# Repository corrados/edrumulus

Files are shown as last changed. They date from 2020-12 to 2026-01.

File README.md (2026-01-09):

# Edrumulus

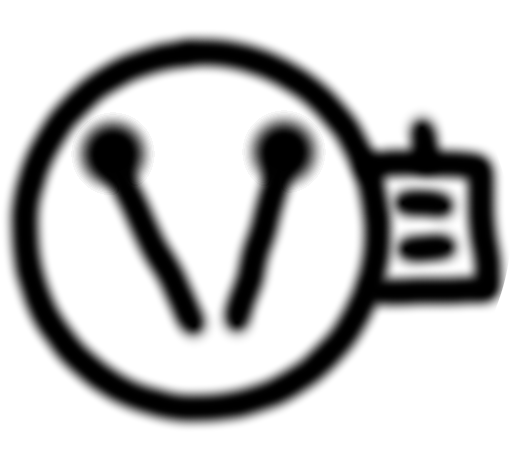
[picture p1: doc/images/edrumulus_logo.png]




**Edrumulus** is a high quality Open Source e-drum trigger module software which runs on a micro processor.

Project requirements:
- The trigger performance shall be similar to the Roland TD-27.
- Overall latency should be as small as possible. The goal is to achieve a latency < 10 ms.
- The required analog front end design shall be as simple as possible using the fewest number of
  parts possible.

## Videos

[](https://www.youtube.com/watch?v=tBlKvivwAE4)
[](https://www.youtube.com/watch?v=naP-ODXl9Y0)
[](https://www.youtube.com/watch?v=HZXtSe5p0rs)

## News

Find all important updates of the Edrumulus project in the [change log file](doc/ChangeLog.md)
and in the [discussion forums](https://github.com/corrados/edrumulus/discussions). A road map
of the Edrumulus project can be found in the [TODO file](doc/TODO.md).

## Features

- Positional sensing
- Retrigger cancellation
- Rim shot/cymbol choke detection
- Cross talk cancellation
- Clipping compensation
- Supported micro processor developer boards:
  - **ESP32 (dual core) DEVKIT V1 or similar**
  - **ESP32-S3**
  - **Teensy 4.0/4.1**

## Documentation

- [Manual](doc/manual.md)
- [Algorithm](doc/algorithm.md)

## Prototype hardware

We want to capture the entire signal without non-linear analog preprocessing.
Since micro controllers usually only convert analog signals in the range of 0 to 3.3 V,
we have to move the point of operation in the middle of the voltage range.

A circuit diagram of a simplified prototype which only supports a mono piezo pad and
a hi-hat controller input is given in the following picture:
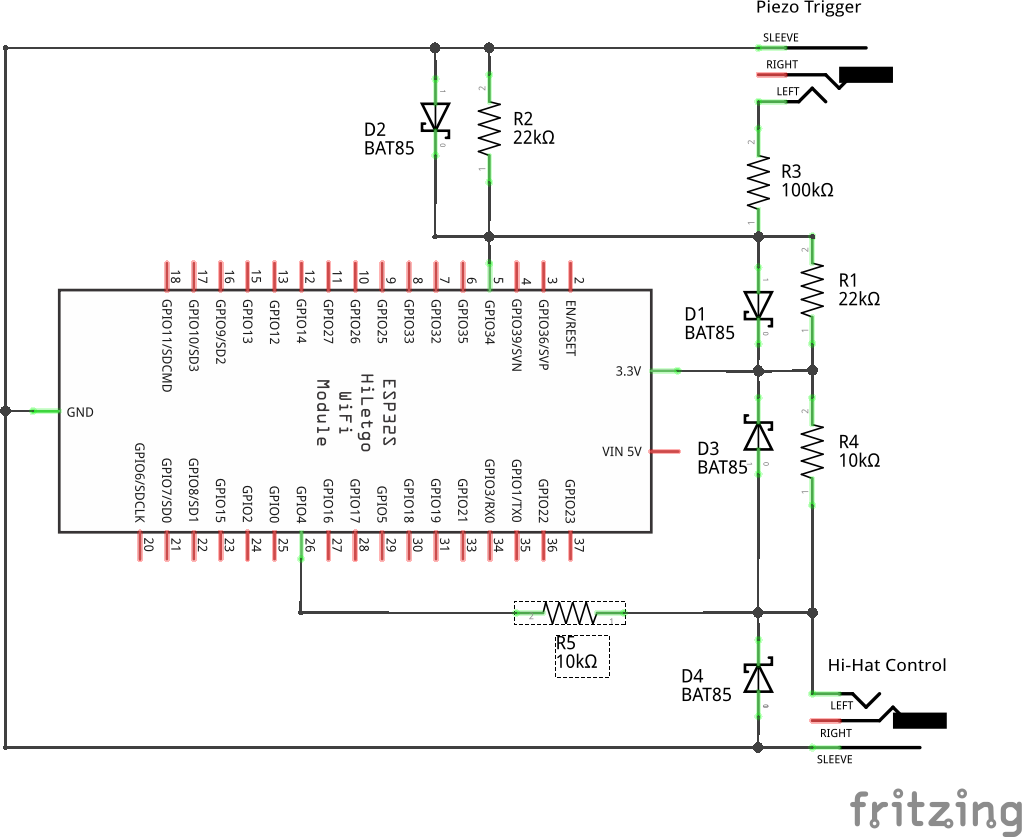
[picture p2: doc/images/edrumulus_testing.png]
<br/><br/>

The full circuit diagram of Prototype2 is given in [this PDF file](hardware/prototype2/edrumulus.pdf).

*DISCLAIMER* All these circuit diagrams are used for my first prototypes and work fine for me. Use them
at your own risk. In particular the circuits may not work for currently unsupported pieces of hardware.

## Gallery

A gallery of user implementations of Edrumulus prototypes [can be found here](doc/gallery.md).

## Links

- [EavesDrum](https://eavesdrum.io) ([Source code](https://github.com/tobigun/EavesDrum))

- [eXaDrums](https://exadrums.com) ([Hackaday](https://hackaday.io/project/9350-exadrums), [Source code](https://github.com/SpintroniK/libeXaDrums))

- [Drumidy](https://hackaday.io/project/176712-drumidy-electronic-midi-drum-controller) ([Source code](https://github.com/EvgenyD/Drumidy)): Uses a STM32 processor with 18 inputs and supports re-trigger cancellation.

- [open e-drums](https://open-e-drums.com) ([Source code](https://github.com/RyoKosaka/HelloDrum-arduino-Library))

- [An Arduino based standalone drum kit Hackaday](https://hackaday.io/project/171929-an-arduino-based-standalone-drum-kit) ([Source code](https://hackaday.io/project/171929-an-arduino-based-standalone-drum-kit#menu-files)): Generates audio, too.

- Forum: [How to solve a system of hyperbola equations](https://math.stackexchange.com/questions/3373011/how-to-solve-this-system-of-hyperbola-equations)

- Forum: [E-Drum Technik-Thread (für Elektrotechnik- und Informatik-Interessierte)](https://www.drummerforum.de/forum/71415-e-drum-technik-thread-f%C3%BCr-elektrotechnik-und-informatik-interessierte.html)

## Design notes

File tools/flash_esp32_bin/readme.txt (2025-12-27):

In Arduino IDE export binaries and copy them in this folder. Note that for current Arduino IDE, the binaries are stored in .cache directory.
Path to boot file for esp32 v3.3.4 library: /home/[user]/.arduino15/packages/esp32/hardware/esp32/3.3.4/tools/partitions/boot_app0.bin

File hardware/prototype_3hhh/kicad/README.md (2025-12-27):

# edrumulus 3hhh prototype with a Teensy 4.1

PCBA design of the [edrumulus circuit](https://github.com/corrados/edrumulus/blob/661487f7e5eb3b547a28747b91cd4156a5f1f353/hardware/prototype2/edrumulus.pdf) with [modifications by 3hhh](https://github.com/corrados/edrumulus/discussions/98) to be used with a [Teensy 4.1](https://www.pjrc.com/store/teensy41.html) with soldered [pins](https://www.pjrc.com/store/teensy41_pins.html).

## Features

- size: 12x7cm
- price: ~30 EUR plus shipping and tariffs (~10 EUR to EU) at https://jlcpcb.com/ for 5 units (2025)
- little soldering required:
  - female socket for the Teensy 4.1
  - SMD components intended for assembly at the manufacturer
- all 18 Teensy 4.1 analog inputs are connected to respective edrumulus circuits
- female header as "breakout" connector to the drum hardware via DuPont jumper wires: Standard 6,3mm Jack stereo cables can relatively easily be soldered to three male-male jumper wires to connect the board to the drum kit (search "solder wires" on youtube). It may make sense to use short cables for soldering and connect them to longer 6,3mm cables as needed.
- 3hhh modifications:
  - Rp=10k for higher sensitivity
  - some pins (A1-A5) with Rs=100k for low sensitivity needs (kick, ...)
  - some pins (A6-A17) with Rs=10k for high sensitivity needs (snare, hihat, ...)
  - 1N5819WS Schottky diode: cheaper and lower forward voltage than BAT85
- M2 screw holes
- also see [this image](./edrumulus_3hhh.jpg)

## JLCPCB manufacturing

Make sure to select:

- 2 layers
- Suface Finish: LeadFree HASL or ENIG
- Mark on PCB: Order Number(Specify Position)
- PCB Assembly

Manufacturing incl. assembly (PCBA) can be done elsewhere as well, but was optimized for JLCPCB.

## Used software

[KiCad 9](https://www.kicad.org/) with the [JLCPCB plugin](https://github.com/Bouni/kicad-jlcpcb-tools).

Useful presets: https://github.com/sethhillbrand/kicad_templates

Helpful KiCad tutorial: https://www.youtube.com/playlist?list=PLUOaI24LpvQPls1Ru_qECJrENwzD7XImd

## Known issues

- edrumulus currently maxes out at ~15 used analog inputs
- the used female headers tend to run out of stock and may have to be replaced with others
- GND needs to be expanded with a small breadboard

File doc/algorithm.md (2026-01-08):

# Drum triggering algorithm

The task to convert a hit on the drum pad with the stick to a MIDI signal consists of multiple stages.
The first stage is the detection of the position in time of the stick hit. This we call the
__peak detection__. Then we __estimate the velocity of the hit__ using the detected peak. The next
step is to estimate the position of the stick hit on the pad (i.e. if the hit was in the center or
at the edge of the pad). This is called __positional sensing__. Another step is to use the information
of a second piezo sensor to detect if we have a rim shot which leads to a __rim shot detection__. In
this step we can also detect if we have a cross stick situation.

## Peak detection

### Signal filtering

The noise of cheap ADCs is usually not equally distributed over the entire frequency spectrum. e.g.,
the Teensy 4.0 noise spectrum looks like the following plot and has high noise energy at the high
frequencies:
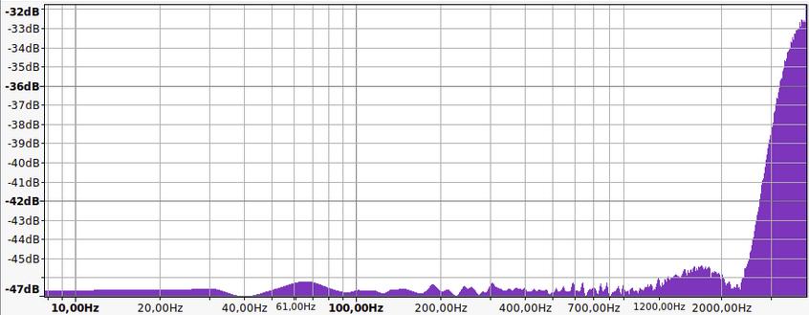
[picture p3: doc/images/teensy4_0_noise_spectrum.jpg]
Teensy 4.0 noise spectrum
<br/>

The spectrum of a piezo signal (in this example using a PD-120 mesh head pad) looks like this:
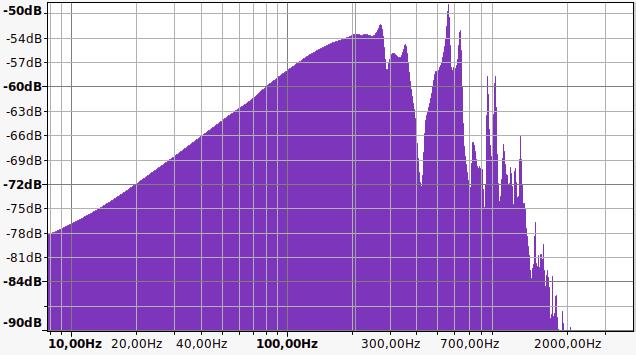
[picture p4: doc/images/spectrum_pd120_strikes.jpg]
Spectrum PD-120 strikes
<br/>

The most energy of that signal is located near 200 Hz. Therefore, to improve the peak detection,
it makes sense to apply a band-pass filter to filter out ADC noise in spectrum parts which are
not used by the pad piezo signal like very low frequencies and high frequencies. Thus,
a band-pass filter is applied to match the useful signal spectrum and filter out the noise.

The pass-band width is a trade-off between noise cancellation and filter delay. As you can see in
the following plot where the blue trace is the original ADC signal and the red trace is the
band-pass filtered signal. Typically, you see three distinct peaks in the red trace which is the
band-pass filtered signal no matter what the original peak looks like:
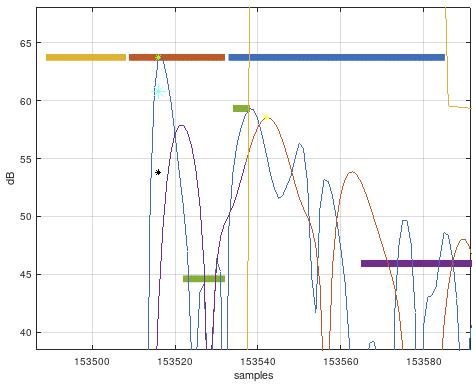
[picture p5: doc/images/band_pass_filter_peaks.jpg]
Band-pass filter peaks
<br/>

This effect is amplified if the upper cut-off frequency of the band-pass filter is lowered.
It has shown that a good compromise is to use a pass-band range of 40 Hz to 400 Hz.

#### Pre-scan time

Caused by the three peaks of the band-pass filtered signal as described in the last section, it
can happen that the second peak (the middle peak) is higher than the first peak. If a buzz-roll
is played and the time distance between strikes is short, the retrigger cancellation can lead to
the fact that the second peak is above the detection threshold and the first peak is not. This
could lead to the problem that the very first/main peak is not inside the scan time period. To
overcome this problem, we introduce a so-called pre-scan time where we store the ADC signal
in a FIFO and search in a time period right before the scan time for a possible first/main
peak. This is marked by the yellow bar in the above plot which shows the three peaks of the
band-pass filtered signal (The red bar is the scan time and the blue bar is the mask time).

#### Latency of the band-pass filtered signal

The band-pass filter introduces a filter delay which is usually below 2 ms. The good thing is
that this filter delay can be ignored as long as it is shorter than the scan time. This is
because we only use the band-pass filtered signal for the threshold test. For anything
else we use the pure ADC signal which is not delayed. So, we store the original ADC signal
in a FIFO and can therefore start the scan time in the past, i.e., undo the band-pass filter
delay.

### Retrigger cancellation

To improve the peak detection, we can make use of the known decay curve of the trigger pad in use.
After successfully detecting a peak we know that this peak causes a slowly decaying power
curve. It has a known shape which we can subtract from the captured signal to improve the
detection of the next pad hit.

The problem is that the main peak power compared to the mesh head vibration power greatly depends
on the position of the hit on the pad. I.e., the main peak stands way out of the _noise_ when hitting
the pad in the middle. If we use the detection hit velocity for the start point of the decay
cancellation, we subtract too much power in case the hit is in the middle of the pad and we may
subtract too little if the hit is at the edge of the pad.

In the following picture, the effect of the retrigger cancellation algorithm on a press roll
example can be seen. The yellow line shows the exponential decay attenuation we apply to the signal
after a hit was detected. The blue trace is the original captured signal and the orange trace is
the captured signal after applying the retrigger cancellation:
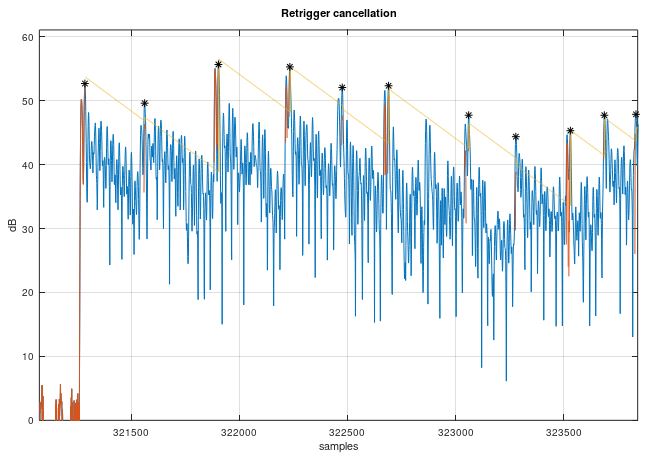
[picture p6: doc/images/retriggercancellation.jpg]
Retrigger cancellation
<br/>

## Positional sensing

If you hit the pad close to the edge, the resulting sound has less low frequencies
and sounds more crisp. Thus, the idea is to low-pass filter the signal and at the detected peak position we
calculate the power ratio of the low-pass filtered signal with the unfiltered signal. This is then
the metric for the positional sensing.

The flow diagram of the algorithm is as follows:

```
                   ┌──────────────┐    ┌───────────┐
                   │              │    │           │    positional
ADC signal ───┬───►│ detect first ├───►│ calculate ├───► sensing
              │    │    peak      │    │   metric  │      result
              │    │              │    │           │
              │    └───────┬──────┘    └───────────┘
              │            │                 ▲
              │            │                 │
              │            │                 │
              │            ▼                 │
              │     ┌────────────┐    ┌──────┴───────┐
              │     │            │    │              │
              └────►│  low-pass  ├───►│ detect first │
                    │   filter   │    │    peak      │
                    │            │    │              │
                    └────────────┘    └──────────────┘
```

The impulse response of the low-pass filter is a triangle shape where the length of the triangle
defines the cut-off frequency of the filter and [can be approximated](https://dsp.stackexchange.com/questions/9966/what-is-the-cut-off-frequency-of-a-moving-average-filter)
with $\frac {\sqrt{0.196202 + F_{co}^2}}{F_{co}},$ where $F_{co}$ is the cut-off frequency and N is the length of the impulse response.

Further testing showed that it is important to use the very first peak in time for positional sensing. If
a later peak is used, the positional sensing based on the low-pass filtered signal does not yield
good results.

### Positional sensing if a rim-shot is played

It has shown that the normal positional sensing metric must be adjusted if a rim shot is used.
In that case, we use the rim shot detection metric instead which gives a good indication of the position:
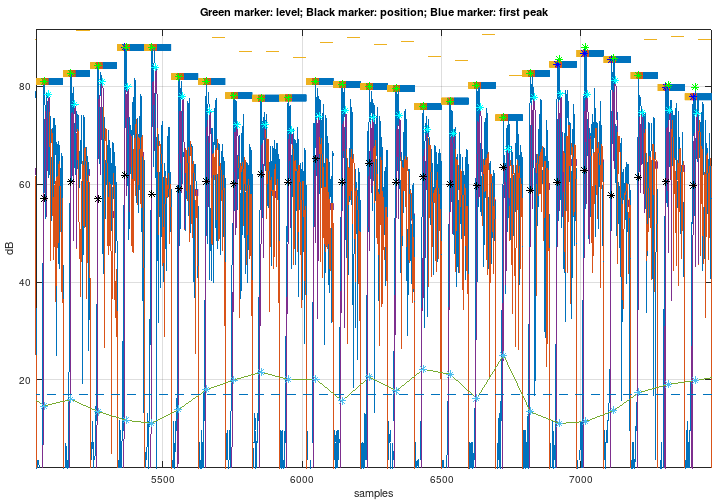
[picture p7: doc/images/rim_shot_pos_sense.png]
Positional sensing with rim shots
<br/><br/>
The idea is that if the strike is far away from the center mounted piezo,
the peak in the rim piezo is much higher than that from the center mounted piezo. If the strike is close
to the middle of the pad, the peak of the center mounted piezo is much higher compared to the rim piezo.

## Rim shot detection

To detect a rim shot, a second piezo sensor is typically mounted at the casing of the pad. To
support rim shot detection, we need a second input signal. At this point I want to reference this
[excellent description of piezo sensing](https://github.com/RyoKosaka/HelloDrum-arduino-Library/blob/master/docs/sensing.md)
by [RyoKosaka](https://github.com/RyoKosaka).

Unfortunately, when I tried out different algorithms for rim shot detection I found out that a simple
algorithm as proposed by RyoKosaka did not give me the expected performance. After I found out that
the rim shot detection is not that straightforward, I did some testing with my Roland TDW-20 and I
figured out that even this professional module has its problems with rim shot detection. The
detection results were not perfect either.

# Algorithm development

The algorithms are developed using a regular audio card. The drum pad output signal is captured and
the signal processing and algorithm development is done in Octave. The development runs in three steps:

1. Create the algorithms using a captured test signal and analyze it as a whole. This is the
   easiest and fastest way to create and improve the algorithms (this is the "playground"). The
   corresponding source file is algorithm/drumtrigger.m.

2. If the algorithm works ok, it is ported to a sample-based processing. The goal is to make the
   Octave code as similar to the C++ micro controller implementation as possible. The corresponding
   source file is algorithm/edrumulus.m.

3. Port the sample-based processing code to C++ and test it in real-time on the hardware. To make
   sure the port was successful, we send test data to the micro controller, query the processed
   signal and compare it in Octave to the reference code.

# Test signals

To support a new pad type, test data should be recorded. If a second trigger is supported, a
stereo signal sampled at 8 kHz shall be used, otherwise use a monophonic recording. Make sure
that the signal is never clipped, even for the highest velocity hits.

## Normal test data capture

The following hit sequence shall be recorded:

- 5 single hits at medium velocity near the center of the pad
  - intended for estimating the decay curve gradient
- 10 to 20 single hits near the center of the pad varying the hit velocity from lowest velocity
  to highest possible velocity
  - intended for threshold/sensitivity adjustment
- about 10 hits with low velocity starting from left edge of the pad going to the middle and
  back to the edge of the pad
- about 10 hits with high velocity starting from left edge of the pad going to the middle and
  back to the edge of the pad
  - both test signals are intended for positional sensing
- press roll at low velocity near the middle of the pad
- press roll at high velocity near the middle of the pad
- press roll at low velocity near the edge of the pad
- press roll at high velocity near the edge of the pad
- press roll varying velocity from high to low and back to high near the middle of the pad
- press roll varying velocity from high to low and back to high near the edge of the pad
  - the press rolls are for optimizing the parameters for the retrigger cancellation

## Rim shot test data capture

The rim shot test data capture is especially useful for mesh hat pads which use a rim shot
piezo. The following hit sequence shall be recorded:

- 5 hits at low velocity near the center of the pad
- 5 rim shots at low velocity near the center of the pad
- 5 hits at medium velocity near the center of the pad
- 5 rim shots at medium velocity near the center of the pad
- 5 hits at high velocity near the center of the pad
- 5 rim shots at high velocity near the center of the pad
- 5 hits at low velocity near the edge of the pad
- 5 hits at high velocity near the edge of the pad

# Latency between pad hit and audio output of the synthesized drum sound

As given in our project specifications, the overall latency should be as small as possible.
The goal is to get a latency < 10 ms. This overall latency consists of:

Time to

- analog-digital convert the analog pad signal,
- process the digital signal with the trigger detection algorithms (filter delays, etc.),
- transmit the MIDI signal,
- create a digital synthesized drum sound signal from the received MIDI signal,
- digital-analg convert the digital signal to get the final audio signal to be played in the loudspeaker or headphone.

If the trigger detection algorithm runs on a microcontroller or DSP and the analog-to-digital conversion
is done on a per-sample bases (i.e. not based on blocks like on a regular audio interface on a PC), this
delay is negligible.

The delay introduced by the trigger detection algorithms is more critical. E.g., if we filter the digital
signal with a FIR filter, this filter will introduce a delay of half the length of the impulse response
used by the FIR filter. As a result, we are restricted in the length of the impulse response to keep the delay low.
The same thing applies to, e.g., moving average filters or scan times. All this introduces delay which we
want to minimize to get to our goal in the project specifications.

The transmission delay of the MIDI signal depends on the channel. If we use the serial communication channel
over USB to transmit the MIDI signal, the delay should be negligible. But if we, e.g., use the bluetooth
of an ESP32 to transmit the MIDI signal, significant delay is introduced by this (about 10 ms).

The synthesis and digital-to-analog conversion of the drum audio signal shall not be covered by this
project (at least not right now). So, we can ignore this part for now.

## Comparison of e-drum module latencies

According to https://www.vdrums.com/forum/general/the-lounge/1182869-fastest-lowest-latency-drum-module-available and http://onyx3.com/EDLM, the drum modules have the following measured latencies:

- Roland TD-50\30: **3 ms**    (measured by Chris K)
- Roland TD11\15:  **3 ms**    (measured by Chris K)
- Roland TD15:     **3.15 ms** (measured by 30YearsLater)
- Roland TD12:     **3.60 ms** (measured by 30YearsLater)
- Roland TD-20:    **5.7 ms**  (measured by Chris K)
- Roland TD-4:     **3.8 ms**  (measured by onyx3.com)
- Roland TD-17:    **3.6 ms**  (measured by onyx3.com)
- MIMIC:           **4 ms**    (measured by Chris K)

I measured the latency of my Roland TDW-20 module by using a stereo splitter cable and connected the
trigger output of my PD-120 pad directly to one channel of my sound card input and also to the trigger
input of the TDW-20 module (note that I used the snare input which supports rim shot detection and
positional sensing which may have an influence on the overall TD-20 latency).
Then I connected the analog audio output of the TDW-20 to the other stereo channel of
my sound card and recorded the signal with Audacity. I now measured the latency between the main
peak of the pad trigger to the first peak of the synthesized signal from the TDW-20. As seen in the
screen shot, there is a latency of about **7 ms**:
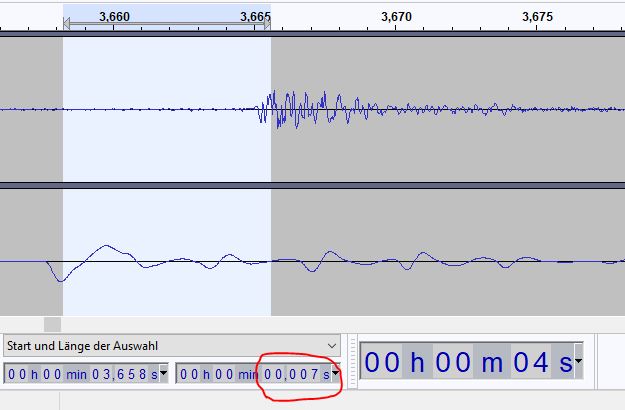
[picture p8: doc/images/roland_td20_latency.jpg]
Roland TDW-20 drum module measured latency
<br/>

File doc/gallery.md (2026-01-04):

# Edrumulus Gallery of User Implementations

## 3hhh

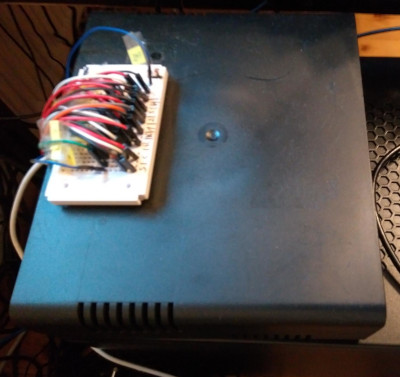
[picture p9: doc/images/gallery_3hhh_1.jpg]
<br/>
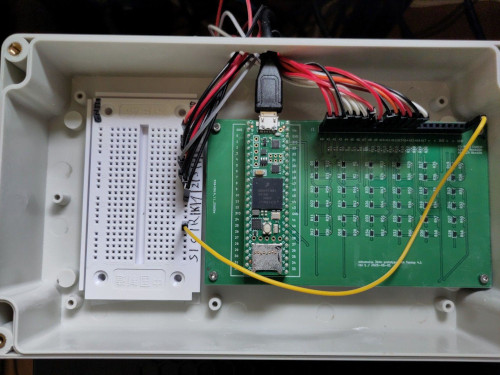
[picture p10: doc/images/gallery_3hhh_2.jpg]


## thijstriemstra

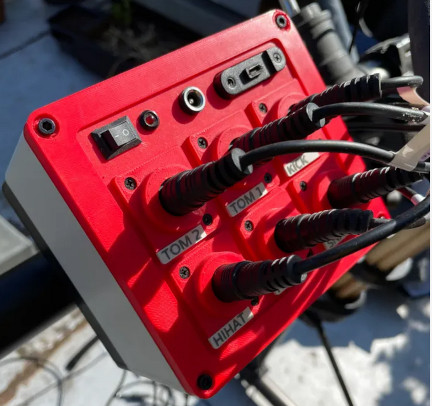
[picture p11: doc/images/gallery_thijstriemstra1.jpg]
thijstriemstra Prototype
<br/>
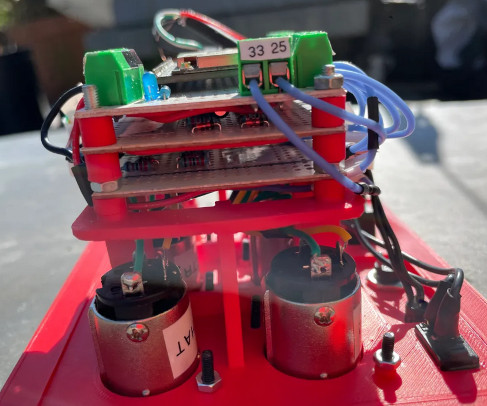
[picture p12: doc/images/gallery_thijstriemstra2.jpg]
thijstriemstra Prototype Inside


<br/>[](https://www.youtube.com/watch?v=YWE1LgwQbbQ)

## analogbetateam

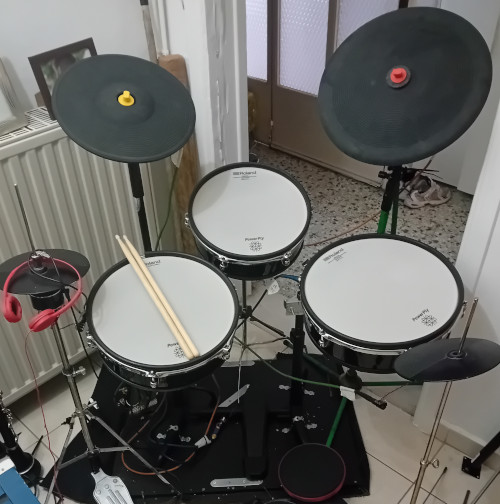
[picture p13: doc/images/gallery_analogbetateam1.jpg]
analogbetateam Prototype
<br/>
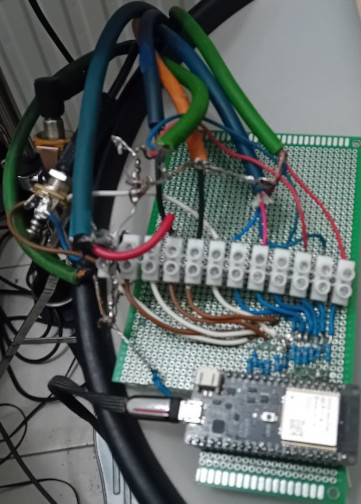
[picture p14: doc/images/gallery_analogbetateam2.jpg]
analogbetateam Prototype Inside


<br/>[](https://www.youtube.com/watch?v=lJCxvKZ8xkM)

## shepss123

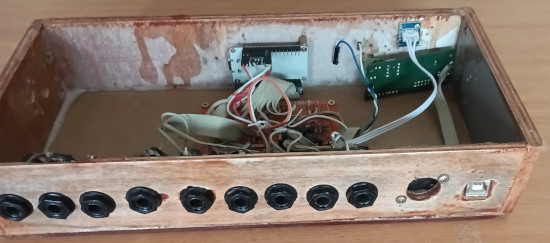
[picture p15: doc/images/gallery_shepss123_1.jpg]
shepss123 Prototype Inside
<br/>
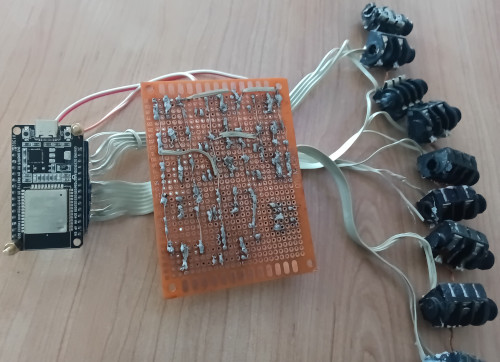
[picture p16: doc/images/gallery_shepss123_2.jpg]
shepss123 Prototype


## ryanalexmartin

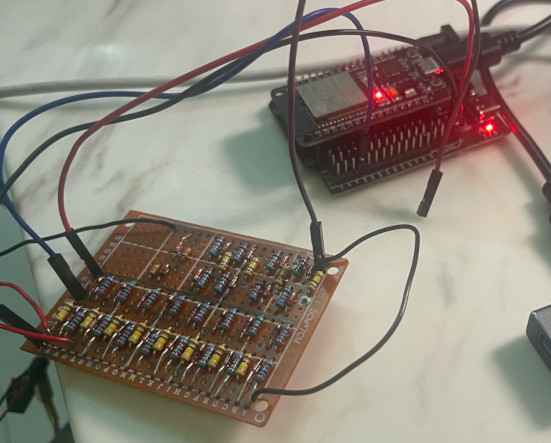
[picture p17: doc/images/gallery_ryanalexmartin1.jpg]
ryanalexmartin Prototype
<br/>

## ocimjr

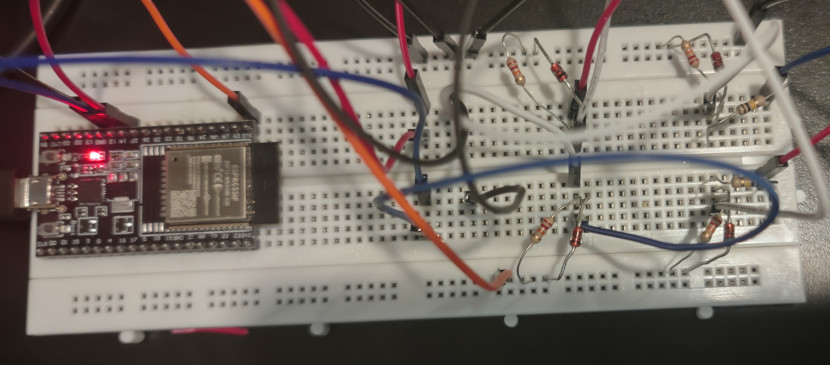
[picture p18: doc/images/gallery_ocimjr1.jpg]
ocimjr Prototype
<br/>

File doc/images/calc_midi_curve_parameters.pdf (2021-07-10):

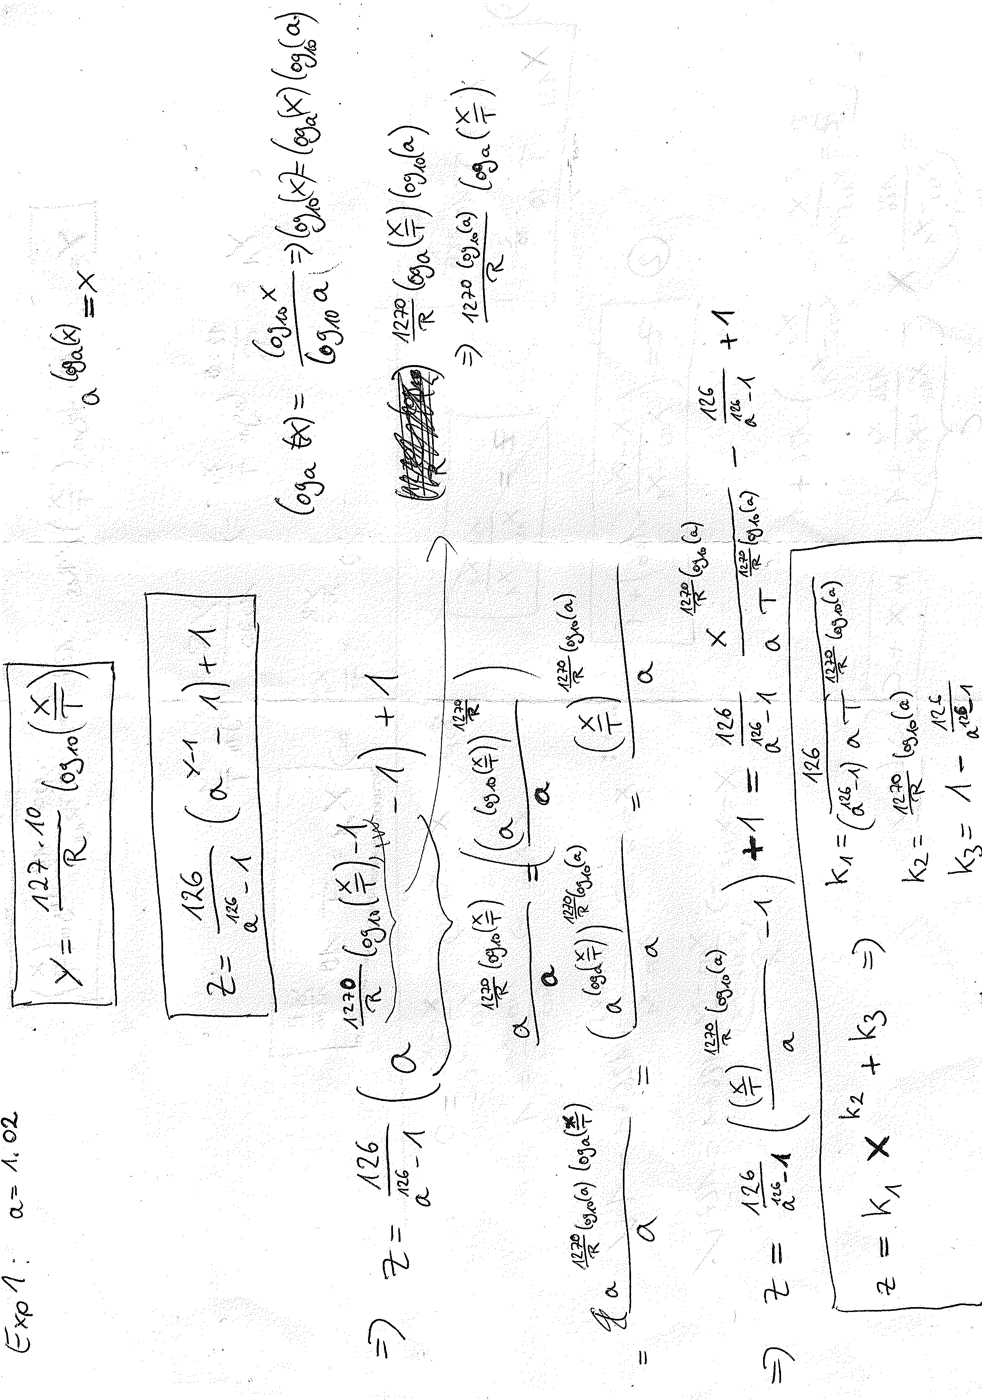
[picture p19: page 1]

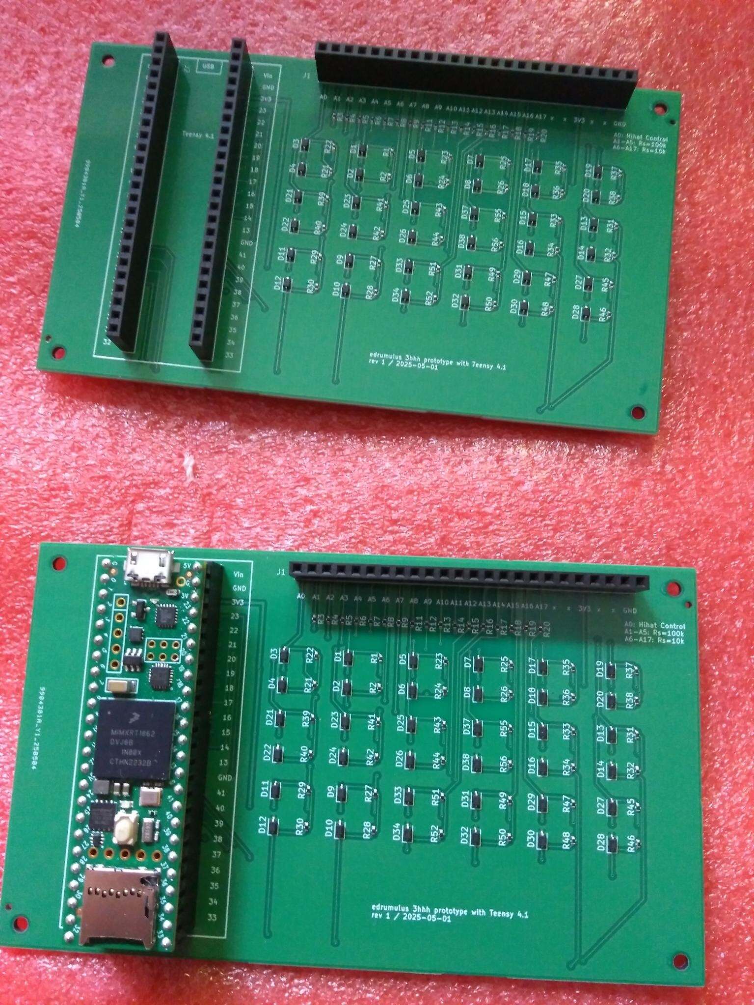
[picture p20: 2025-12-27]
hardware/prototype_3hhh/kicad/edrumulus_3hhh.jpg

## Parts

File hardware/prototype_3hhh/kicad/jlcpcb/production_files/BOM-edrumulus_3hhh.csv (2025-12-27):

Comment | Designator | Footprint | LCSC | Quantity
D | D1,D10,D11,D12,D13,D14,D15,D16,D17,D18,D19,D2,D20,D21,D22,D23,D24,D25,D26,D27,D28,D29,D3,D30,D31,D32,D33,D34,D37,D38,D4,D5,D6,D7,D8,D9 | D_SOD-323 | C191023 | 36
100k | R3,R4,R5,R6,R7 | R_0402_1005Metric | C25741 | 5
10k | R1,R11,R12,R13,R14,R15,R16,R17,R18,R19,R2,R20,R21,R22,R23,R24,R25,R26,R27,R28,R29,R30,R31,R32,R33,R34,R35,R36,R37,R38,R39,R40,R41,R42,R43,R44,R45,R46,R47,R48,R49,R50,R51,R52,R55,R56,R8,R9 | R_0402_1005Metric | C25744 | 48
Conn_01x24_Socket | J1,J2,J3 | 1x24P Female Header Hong Cheng HC-PM254-8.5H-1x24PZ | C41376163 | 3

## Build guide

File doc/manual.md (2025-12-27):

# Edrumulus User Manual

Edrumulus is a high quality open source e-drum trigger module software. To use Edrumulus, you need to have:

- a supported micro controller developer board (see the README file for supported micro controllers),
- an analog front end circuit to connect the trigger pads to the micro controller (either a bread board is
  used or soldering skills are needed),
- the [Arduino](https://www.arduino.cc/en/software) or [PlatformIO](https://platformio.org/) IDE for flashing the micro controller firmware,
- [Python](https://www.python.org) to control Edrumulus trigger parameters in real-time.
  - Install the Python PIP packages python-rtmidi and windows-curses.

## Analog front end circuit

If Edrumulus is installed on the micro controller and there is no analog front end circuit attached,
you will get a lot of false triggering (i.e. a lot of MIDI notes). For the Edrumulus system to work correctly,
all configured ADC inputs must have the analog front end circuit attached.

If an analog front end for a configured input is missing or faulty, Edrumulus will report a DC offset error.

If you need higher sensitivity for low and medium velocity hits, you can try the MPS-750X circuit from below.

## Setup for ESP32

Install the Arduino IDE and add the ESP32 Board Manager according to
[this linked description](https://docs.espressif.com/projects/arduino-esp32/en/latest/installing.html).
Now open the edrumulus.ino file in the Arduino IDE and compile and upload.

## Use Edrumulus in your DAW

Go into edrumulus/tools directory and start edrumulus_gui.py. This tool will connect to Edrumulus and
creates (virtual) MIDI ports which can be selected in your DAW as a MIDI device. This tool works on
Windows, Linux and MacOS.

E.g., on Linux simply type `python3 edrumulus_gui.py`. If you have an ESP32-S3, this usually is on a
different serial port than the normal ESP32. E.g., for an ESP32-S3 on Windows, the following command
should work: `python edrumulus_gui.py serial COM4`.

## Hardware-specific comments

### How to support new pieces of hardware

1. Start with prototype 2 and optimize the analog circuit. Random testing or a simulation with software like LTSpice could be used.
3. Analyze the samples in the Octave model to identify the edrumulus parameters:
   - Attach the pad to a normal sound card and record the strikes with 8 kHz sampling rate and according to https://github.com/corrados/edrumulus/blob/main/doc/algorithm.md#test-signals.
   - Add the recording to https://github.com/corrados/edrumulus/tree/main/algorithm/signals.
   - Create a new type in https://github.com/corrados/edrumulus/blob/main/algorithm/signalsandsettings.m and use an
     initial parameter set from a similar pad as a starting point.
   - Call the script signalsandsettings.m in Octave which automatically uses the script drumtrigger.m.
   - Adjust the parameters so that the decay curve looks ok and try to get as little false triggers as possible.
   - The updated parameters are then used in https://github.com/corrados/edrumulus/blob/main/edrumulus_parameters.cpp.
   - To get it fully working, the new type has to be added at multiple places, e.g. in the GUI python script, too.
4. Test the parameters in practice. Modify the available real-time parameters for hopefully better results. Possibly go back to previous steps.

### Millenium MPS-750X

- Recommended circuit: [Rs=10k, Rp=10k, Cp=0](https://github.com/corrados/edrumulus/discussions/98) with low forward voltage diodes (e.g. Shottky BAT85) and Rs=100k for the kick drum.
  - Rs=10k versus Rs=100k increases the sensitivity for low and medium velocity hits at the expense of higher shorting risk for harder hits. This usually does not make sense for pads with low sensitivity needs such as the kick drum. Values between Rs=10k and Rs=100k may be chosen as a compromise.
- TRS pins:
  - Toms: hit piezo = T, rim piezo = R, GND = S.
  - Cymbals including Hi-Hat: Bow piezo = S, Rim switch = R (none for Hi-Hat), GND = T.
- Ride and crash cymbals draw some current.
- The ride rim switch differs from the ride bell switch by a 5k resistor.
- Set all MPS750X potis to maximum output with a screw driver (sometimes the direction appears to be indicated incorrectly).

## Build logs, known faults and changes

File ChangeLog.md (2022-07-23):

# Edrumulus Project Log

## 2022-07-23 Confusion about the PDA-120LS pad

  My assumption was that all Roland pads with mesh heads do support positional sensing. So, I
  acciently recommended the PDA-120LS for having positional sensing support with Edrumulus.
  After recording a test signal with that pad, I had trouble to find any parameters where the
  positional sensing works at all. Finally, I found out that this pad does not use a center-
  mounted pizeo but three piezos at the edges of the mesh head. That explains why I could not
  get the positional sensing working. So, be careful what kind of mesh head pad you buy if you
  want to have positional sensing.

## 2022-07-02 Youtube video of prototype 3 (HD-1)

  A [Youtube Video](https://youtu.be/tBlKvivwAE4) of Edrumulus prototype 3 (HD-1) is
  now available showing the trigger performance in real action.

## 2022-06-18 Unreliable settings storage on ESP32

  Unfortunately, it seems that the settings storage on the ESP32 does not work as expected.
  On my prototype 3 (HD-1), some settings are not recalled correctly. This especially
  happens if the attached Raspberry Pi must be resetted after, e.g., a freeze. Either the
  sudden power off of the ESP32 is the cause or the Raspberry Pi sends arbitrary MIDI signals
  when it is shut-down. This has to be investigated...

## 2022-01-22 [[r0.4](https://github.com/corrados/edrumulus/releases/tag/r0_4)] Store settings on Edrumulus

  Edrumulus stores all trigger parameter on the micro processor using the Arduino
  EEPROM library now. It is no longer necessary to hard-code pad trigger parameters for
  your prototype in edrumulus.ino. After flashing the new firmware for the first time,
  the settings must be reset. Either use the Linux EdrumulusGUI and press the **r** key
  or use the Octave edrumuluscontrol.m GUI and press the **Reset All Settings** button.

## 2022-01-16 [[r0.3](https://github.com/corrados/edrumulus/releases/tag/r0_3)] New Linux console GUI

  There is a new tool available to show/modify Edrumulus parameters in a Linux (remote) shell
  using the ncurses library. This comes handy if Edrumulus is used with Drumgizmo running on
  a headless Raspberry Pi. This GUI is coded in one single file tools/edrumulus_gui.cpp.
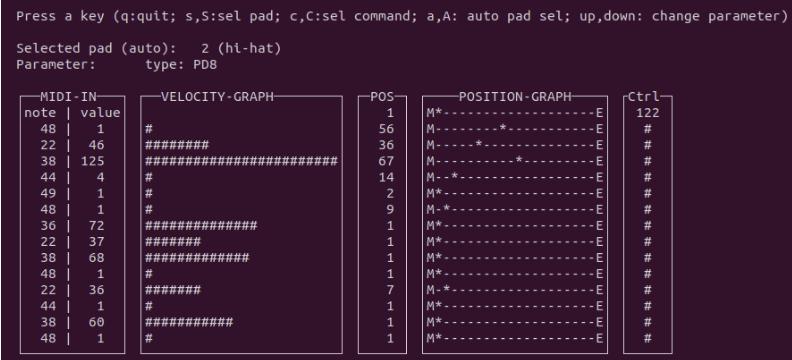
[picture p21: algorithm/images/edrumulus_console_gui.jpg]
Edrumulus console GUI
  <br/>

## 2022-01-09 Edrumulus prototype 3 (HD-1)

  Today was the first time I tested Edrumulus in a full drum-kit setup and
  stand-alone (i.e. no PC or Laptop needed). The prototype 3 consists of an
  ESP32 with 7 pad and 1 control inputs, a Raspberry Pi 3 with a 32 GB SD card
  and a Behringer UFO 202 USB audio interface. It worked pretty amazingly well.
  Of course, there is plenty of room for improvement. But for a first try it was
  a great experience. Even positional sensing was possible with the PDX-8
  mesh pad even that it does not have a center mounted piezo trigger.
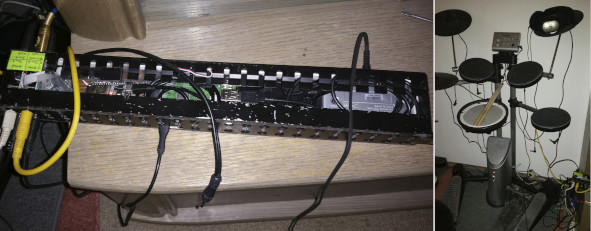
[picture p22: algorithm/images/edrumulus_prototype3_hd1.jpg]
Prototype 3 (HD-1)
  <br/>

## 2022-01-09 Possible out-of-memory issue for the ESP32

  Today I flashed the current Edrumulus code on my ESP32 and it immediately crashed. After
  disabling the initialization of the last configured pad it did not crash anymore so, I
  assume that we have an out-of-memory issue for the ESP32.

## 2022-01-08 Hot spot detection for mesh head pads

  I was working on a hot spot detection algorithm on a Git side branch recently. As a reference,
  I have used the piezo signal of a PD-80R and PD120 recorded with a conventional audio card.
  These audio card inputs are usually optimized for low impedence microphones. I developed an
  algorithm which worked fine for these signals but did not work at all for running it in
  real-time on a micro controller. The reason for that is caused by the mismatched input of the
  audio card for piezo signals. The shape of the signal is so different that the algorithm
  did not work at all. A new algorithm and further investigations are needed.

## 2021-12-16 Rim shot detection again

  After fixing a bug with the detection of the first peak and introducing a band-pass filter
  for the rim piezo signal of the PD-80R, the rim shot detection is now acceptable (but still
  far from perfect).

## 2021-12-05 New algorithms ready

  The improved peak detection and positional sensing algorithms are now ready and the code
  was merged from a Git side branch to the main branch. By implementing these improvements,
  the source code was heavily changed. Thus, a lot of fine tuning has to be done to, e.g.,
  tweak the pad parameters for the new algorithms and fix possible new issues.

## 2021-11-21 Time to say goodbye, Hilbert...

  The filtered signal currently used for peak detection is a Hilbert filtered signal with
  a moving average low-pass filter applied to it. The initial motivation for this design
  was to reduce the noise and improve the main lobe energy measurement. It turned out that
  it is advantageous to just use the peak value instead of an average.<br/>
  Therefore, we should use an optimized filter which improves the peak detection. To
  reduce the noise floor, a low-pass filter should still be applied. At the same time, some
  high pass filter should be applied to filter out very low frequency noise caused by, e.g,
  the movement of the pad stand after a hit on the pad. Thus, a Butterworth band-pass filter
  with a pass-band of 40 to 400 Hz was chosen. The shorter the pass-band, the longer the filter
  settle time will be. Since the settle time should be as short as possible, it
  is a trade-off between noise reduction and latency.<br/>
  In the following picture, the current Hilbert filter based design is compared to the new
  Butterworth filter design where the peak detection threshold is tweaked for each scenario
  so that no false peaks are detected in the entire signal:
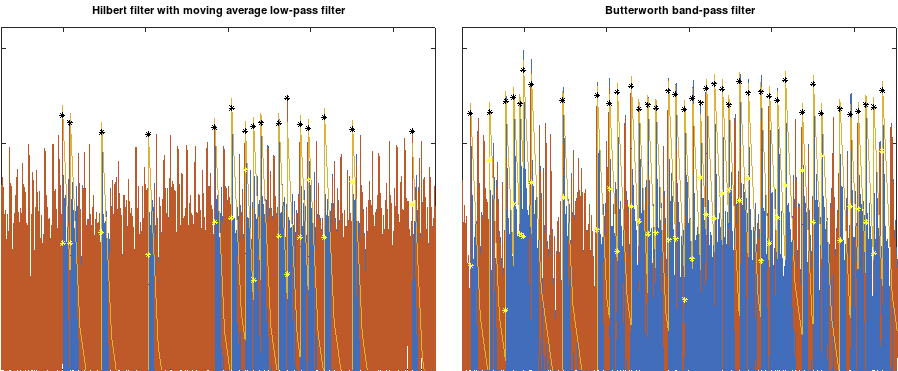
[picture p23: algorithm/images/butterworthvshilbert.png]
Butterworth filter versus Hilbert filter
  <br/><br/>
  It can be seen that the new Butterworth filter design detects more peaks compared to
  the existing Hilber filter design.<br/>
  Note that the investigation and implementation is currently on a Git side branch. It will
  take some time to finish this work until it is ready to be merged on the Git main branch.

## 2021-10-09 Fixing issues and improving positional sensing
  I am currently heavily changing the Edrumulus code on a Git side branch. I found an issue
  with the moving average filter of the Hilbert filter result and also want to improve the
  positional sensing. As soon as these changes are done, the code will be merged onto the
  main Git branch.

## 2021-10-02 PD-80R investigations
  I just found out that on the PD-80R mesh pad the detected MIDI velocity at the
  edge of the pad is much too small compared to the hit with the same force in the middle of
  the pad. The problem is that there is a moving average of 2 ms applied to the signal which
  is used to find the maximum value. If you play a mesh pad at the edge, the main peak is of
  smaller width compared to the peak if you hit the mesh pad in the middle. Therefore, a lot
  more energy is collected with the long moving average filter for the hit in the middle. To
  fix this issue, the moving average could be shortened to, e.g., 0.5 ms. But if this is
  modified, multiple other problems arise like we have to rise the threshold. This is most
  probably caused by the fact that the longer averaging has filtered away small peaks from
  the ADC noise. Also, the retrigger cancellation does not work as good anymore.<br/>
  To solve the issue, one way would be to use the longer moving average filter for the
  threshold detection and a shorter moving average filter for the MIDI velocity detection.

## 2021-09-28 PD-8 positional sensing does not work
  It turned out that the positional sensing algorithm does not work at all for the
  Roland PD-8 rubber pad. Interestingly, it works quite good for the Yamaha TP-80 rubber pad.
  More investigations are needed to find out the cause of the problem.<br/>
  A detailed view of the curcuit board for the jack sockets which are based on the patchbay is
  shown in the following picture:
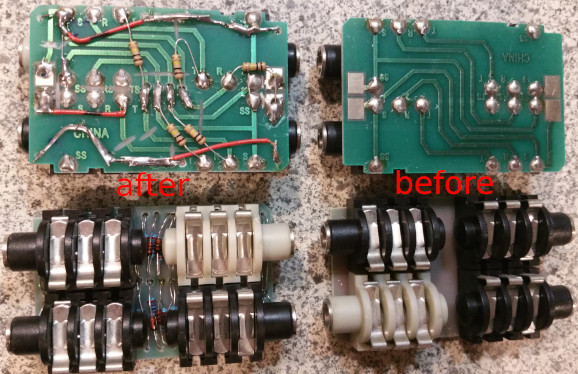
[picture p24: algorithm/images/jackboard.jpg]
Jack board
  <br/>

## 2021-09-19 Some project logs
  - One outstanding serious issue is false triggering in case no pad is played. This may be caused
    by electromagnetic interference like if someone switches a light on or it is caused by the
    microcontroller and its ADC itself.
  - In Edrumulus the start of the Scan Time is defined at the first detected peak. Usually, the
    scan time is defined from the point in time when the input signal crosses the trigger threshold.
    It has shown that if, e.g., the trigger is hit directly, we might get strange effects before the
    main peak so that the signal goes above the threshold earlier than for normal pad hits and as
    a consequence, the scan time would not cover the same amount of the regular peaks as with the
    normal pad hits.
  - For the PD80R, the positional sensing must be improved since sometimes a false first peak is
    detected if the piezo is hit directly with the stick (hot spot).

## 2021-07-17 Adding a cross talk cancellation
  Now an experimental pad cross talk cancellation algorithm is supported in
  Edrumulus. This is useful if pads are attached on the same stand and trigger each other.

## 2021-07-04 Improving ADC spike detection algorithm
  Still too many false detections on the ESP32. The ADC spike detection algorithm
  must be improved. A new algorithm development file "adc_spike_cancellation.m" was created.

## 2021-05-15 Hardware support is stable
  After a lot of tweaking, both boards (ESP32 and Teensy) perform good enough now
  so that I can concentrate on the algorithm development again. On the Teensy, I had to disable
  the "keeper" and average multiple ADC samples to get correct and spike free readings. Since
  the ARM core is so fast, there were no problems running the algorithms in real time.<br/>
  For the ESP32 the situation is different. The CPU speed was the limiting factor for a long time.
  Fortunately, I found out that it is possible to run the ADC processing on one CPU core and
  do the signal processing on a different CPU core. That solved the speed issue. I did not find
  a way to suppress the ADC spikes on the ESP32 but I solved the problem in software with a spike
  cancellation algorithm. This solution is not ideal (especially for low velocity hits the
  performance is degraded) but still good enough.

## 2021-05-09 Teensy 4.0 versus ESP32
  There is a new prototype, now using a Teensy 4.0 developer board:
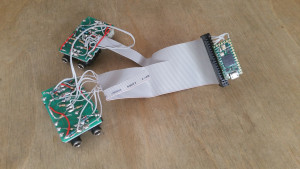
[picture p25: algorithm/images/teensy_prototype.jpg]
Teensy Prototype
  <br/><br/>
  Difference between ESP32 and Teensy 4.0 with regard to Edrumulus:
  Feature | ESP32 | Teensy 4.0
  --- | --- | ---
  #ADC inputs | 18 | 14
  FPU | yes | yes (better performance than ESP32)
  Speed | 240 MHz dual core | 600 MHz single core
  ADC | 2 ADCs, a lot of spikes | 2 ADCs, less spikes (but still some smaller spikes visible)
  USB MIDI | over serial, needs Hairless MIDI or ttyMidi | shows up as USB MIDI device
  Debugging | either serial debugging or MIDI | MIDI and debugging can be done in parallel
  Cost | ~10 € | ~20 €

## 2021-05-02 Prototype 1 on Youtube
  Here is link to a Youtube video of the new Prototype 1 in action: https://youtu.be/UKeuFm_DDTk
  <br/>I was running [Drumgizmo](https://drumgizmo.org) under Linux on my Laptop with the
  [The Aasimonster](https://drumgizmo.org/wiki/doku.php?id=kits:the_aasimonster) drum kit where the
  snare samples were replaced by Tama Artstar snare samples which support positional sensing.

## 2021-05-01 Minimal drumset prototype
  There is another Edrumulus prototype which is a minimal
  drumset with kick/snare/hi-hat:
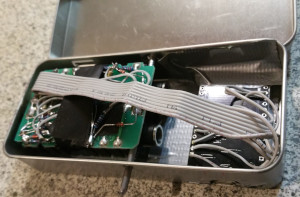
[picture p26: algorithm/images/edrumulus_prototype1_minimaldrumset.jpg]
Prototype 1 minimal
  <br/>

## 2021-04-10 Prototype
  Here is what my current Edrumulus prototype looks like:
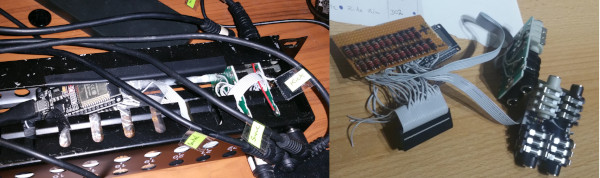
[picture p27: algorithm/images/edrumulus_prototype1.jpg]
Prototype 1
  <br/>

## 2021-04-04 ADC spikes of the ESP32
  This is how the ESP32 ADC signal looks like:
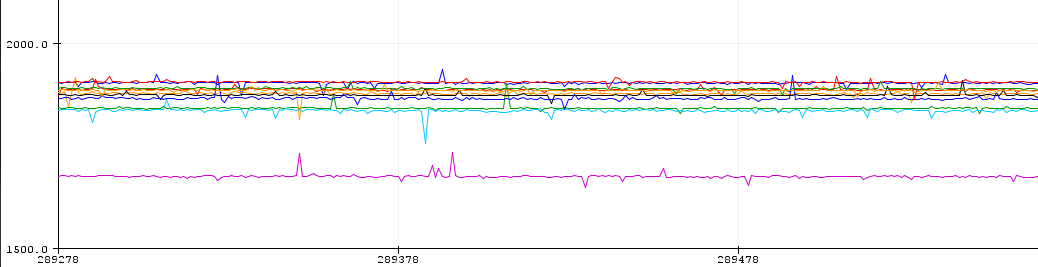
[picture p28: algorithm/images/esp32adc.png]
ESP32 ADC Signals
  <br/><br/>
  These spikes seem to be a hardware restriction of the ESP32. I am trying to mitigate this
  effect by implementing a spike suppression algorithm.

## 2021-04-03 Using our own analogRead implementation
  The Edrumulus now implements its own analogRead function so we can use
  the newest arduino-esp32 library version (which is 1.0.6 at present time).

## 2021-04-01 Speed tests
  Some speed tests with 6 pads:
  Everything + adc1_get_raw call: **0.368 ms**, Everything: **0.1162 ms**, Without process sample: **0.077 ms**,
  Without analogRead: **0.0455 ms**.<br/>
  Conclusion: The new ESP32 Arduino Library now [uses the IDF driver](https://github.com/espressif/arduino-esp32/pull/3377)
  which is basically the adc1_get_raw function which is very slow as seen in my speed tests. My speed tests also
  showed that the bottle neck is the analog read.

## 2021-03-24 Measurements of hi-hat controllers
  Measurements of hi-hat controllers:
  **VH-12 controller:** open **14 kOhm**, closed **10 kOhm**, pressed **8 kOhm**,
  **FD-8 controller:**  open **50 kOhm**, closed **0 Ohm**.

## 2021-03-23 Issue with Arduino board manager for ESP32
  I just updated the Ardunio board manager "ESP32 by Espressif Systems" to Version
  1.0.5 and now the code runs much slower on the ESP32 module so that I cannot even run just one
  pad with 8 kHz sampling rate anymore. So I had to revert the board manager version to 1.0.4. I
  hope that with the next board manager update this issue will be fixed and we get back to the
  normal speed on the hardware. For the time being I will stick to version 1.0.4.

## 2021-03-20 Improving retrigger cancellation algorithm
  The retrigger cancellation algorithm is now improved. The decay power is now estimated
  and the decay curve adjusted accordingly. I also bought three used patchbays which have a lot of
  jack sockets which can be used as trigger inputs.
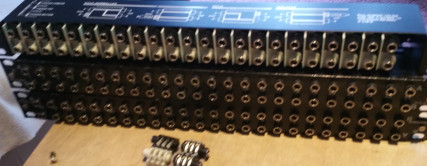
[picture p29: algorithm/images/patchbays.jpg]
Used patchbays
  <br/>

## 2021-02-05 Using Drumgizmo
  I am currently evaluating the great [Drumgizmo](https://drumgizmo.org) software
  to be used in conjunction with Edrumulus. I am in contact with the [main developer](https://drumgizmo.org/wiki/doku.php?id=team) and have
  already written some code to [support ALSA MIDI in Drumgizmo](https://linuxmusicians.com/viewtopic.php?f=56&t=22714).
  I am currently trying to run Drumgizmo on a Raspberry Pi zero but I assume that I will
  need at least a Raspberry Pi 4 to get a decent performance.

## 2021-01-24 Rim shot detection done
  Rim shot detection is now ready but does not yet perform as good as the reference
  Roland TD-20 module. Anyway, by just rotating my PD-120 pad so that I hit the rim approximately
  at the position where the jack plug is located, the rim shot detection works much better now
  since the rim shot piezo is also located close to the jack plug.

## 2021-01-19 Rim shot detection development
  Still working on the rim shot detection using the PD-120 pad. It turns out to be very
  difficult to get a reliable rim shot detection. So, it will take some more time to solve this problem.

  The current project plan is to continue working on making the PD-120 triggering as good as possible.
  If possible, I would like to compare the performance of Edrumulus to the TD-20 by capturing the piezo
  signal together with the MIDI output of the TD-20.

  If the PD-120 triggering is ready, I'll start to support other pad types like the PD-80R and the PD-6.
  Then support kick trigger pads like the KD-8. Finally, the hi-hat/crash/ride pads shall be supported.

## 2020-12-22 Testing BLE MIDI
  Just tested BLE MIDI (i.e. MIDI over bluetooth). I could successfully connect to GarageBand
  on an iPhone. Unfortunately, the bluetooth connection caused some interference in the audio input signal
  so that the threshold had to be increased and also we got a lot of false detections on low velocity hits
  at the edge of the pad. So for future hardware designs some shielding should be considered. Also, I started
  looking at the second piezo signal to support rim shot detection.

## 2020-12-20 Support positional sensing on an ESP32
  The positional sensing algorithm is now also ported to the ESP32 micro controller. I have made a
  new Youtube video using the current implementation (Git commit c796369): https://youtu.be/naP-ODXl9Y0

## 2020-12-18 Running initial algorithms on an ESP32
  I have ported the Octave peak detection code to the ESP32 developer board (a DOIT ESP32 DEVKIT V1,
  no positional sensing yet) and connected it via my PC and Hairless MIDI to my Roland TD-20 module so that
  the snare sound was coming out of the TD-20. This time I could test the performance in real-time. The parameters
  were not yet optimized but still, the results were very promising. Without positional sensing, the ESP32 runs at
  about 56 kHz sampling rate when calculating the peak detection algorithm on one pad. Since I only need 8 kHz
  sampling rate (maybe even 4 kHz is sufficient), we have a lot of headroom for the positional sensing algorithm
  or to add rim shot support and support multiple pads.

## 2020-12-13 Initial algorithm tests
  I am very pleased about the current algorithm performance. The algorithm is not yet fine-tuned but
  already performs pretty well. I have created a short Youtube video of the algorithm (Git commit c83743e) to show
  the current performance in action: https://youtu.be/6eQjCD-DFjo

  The following plot shows how the current status of the algorithms performs. At the beginning there are
  some single hits. Then there follows a region with a snare drum roll. After that, there are single hits
  which start from the middle, move to the edge and go back to the middle of the pad where the hits are
  equally strong. As shown by the black markers, the positional sensing seems to work pretty well. Also,
  the peak detection and velocity estimation seems to be pretty good as well.
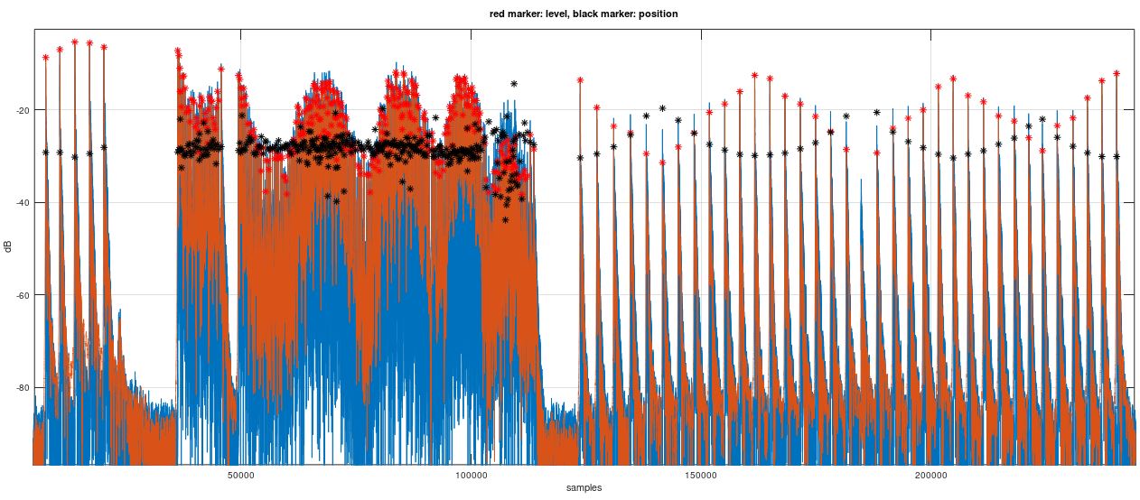
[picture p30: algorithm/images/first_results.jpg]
First results plot
  <br/>

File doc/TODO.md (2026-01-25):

# Edrumulus Road Map

The road map items are sorted by priority.

- [ ] **Investigate if a neural network (AI) can be used for Edrumulus (Github Issue [168](https://github.com/corrados/edrumulus/issues/168))**

  Challanges:
  - Make the network as small as possible so that it can be run on, e.g., an ESP32-S3.
  - What about latency of the algorithm? Can the AI lern to keep the delay below a certain threshold?
  - Do we have sufficient recordings or are there much more needed to lern the neural network?

- [ ] **Hot spot suppression on mesh pads with center piezo**

  Striking directly on the piezo results in detected velocity values which are much too high.

  Recent recordings show that there seems to be no direct detection possibility of hot spot situations.
  It is more likely that we have to use the positional sensing information for this. If a
  position close to the middle of the pad is detected, we can apply an attenuation in case of
  hot spot suppression is turned on. But the positional sensing may not be precise enough to
  result in good detection of a hot spot strike.

- [ ] **Support direct rim strike**

  See https://github.com/corrados/edrumulus/discussions/84.

- [ ] **Introduce a first peak detection reliability**

  This can be used to improve the positional sensing. E.g., if the reliability is low, we could
  use the position of the last detected peak if it is close to the current peak in time (e.g., if
  we have a fast roll situation). But the last detected peak is maybe not a good idea to use since
  we usually have two sticks and the position of the last peak is most probably from the other
  stick which position is most probably away from the correct position of the current peak.

- [ ] **Change rim shot/positinal sensing counters**

  Taken from the code:
    - only use one counter instead of rim_shot_cnt and pos_sense_cnt
    - as long as counter is not finished, do check "hil_filt_new > threshold" again to see if we have a higher peak in that
      time window -> if yes, restart everything using the new detected peak

- [ ] **Create a super simple default drum kit in the git repo so that run_edrumulus.sh runs successfully without any other dependencies**

  See https://github.com/corrados/edrumulus/discussions/94#discussioncomment-6994715.

- [ ] **Add support for USB OTG MIDI for the ESP32-S3**

  It seems we have to wait for the Github espressif/arduino-esp32 project to support the newest ESP-IDF
  so that #include "tinyusb.h" does not give a compiler error. See esp-idf/examples/peripherals/usb/device/tusb_midi
  for an example code.

- [ ] **Improve rim shot detection**

  Especially for pads like the PDA-120L where the piezos are located near the edge, the rim shot detection does perform poorly.

- [ ] **Add support for rim boost setting for multiple head sensor pads**

  The rim boost setting is only supported for pads with just one head sensor.

- [ ] **Cross talk cancellation doesn't work reliably (Github Issue [#109](https://github.com/corrados/edrumulus/issues/109))**

  User 3hhh observed that cross talk spikes may actually arrive before the spike of the pad he actually hit.
  -> Can be fixed with the xtalk programm created by 3hhh (see Git submodule in tools directory).

- [ ] **For the ESP32 prototype, adjust the ADC_noise_peak_velocity_scaling in edrumulus.h correctly**

- [ ] **Should we consider pre-scan time high peaks for velocity estimation?**

- [ ] **Documentation (user manual)**

  Create an Edrumulus manual which describes the hardware/software setup, parameter description, HOWTOs, etc.

- [ ] **Algorihm documentation**

  The algorithm description should be improved. Especially, improve retrigger cancellation section.

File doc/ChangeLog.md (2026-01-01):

# Edrumulus Project Log

## 2026-01-01 Introduce load indicator

  A CPU load indicator is added to the GUI which can be used to get an idea of the available
  CPU headroom for the current pad settings. Also, it can be used to speed optimize the source
  code. Be aware that the load indicator does not include all processing so that a load of
  approx. 95 % already drops the sampling rate.

## 2024-06-19 [[r0.9](https://github.com/corrados/edrumulus/releases/tag/r0_9)] Introduce clang format

  Too much time spend for formatting the source code. We let the clang format tool do this
  from now on. The correct format is now checked in the Github workflow.<br/>
  To format the code use: `clang-format -i *.cpp *.c *.h *.ino`

## 2024-01-07 Initial support for positional sensing for rim shots

  The normal positional sensing algorithm did not work correctly if a rim shot was played.
  A new simple algorithm is now implemented which uses the same metric as the rim shot
  detection. This algorithm is only used in case a rim shot was detected. The idea is that
  if the strike gets farer away from the center piezo, the power ratio between the maximum
  peak of the center piezo to the rim shot piezo becomes lower.

## 2023-12-02 Improvements for edrumulus_gui.py

  On Windows it is no longer required to run loopMIDI and HairlessMIDI tools to communicate
  with Edrumulus ESP32 prototypes. edrumulus_gui.py implements the serial communication
  and creates a virtual MIDI port now.

## 2023-07-16 Initial support for 3-zone pads like the Roland CY-12R

  There is an initial support for 3-zone pads like the Roland CY-12R implemented now. With a
  new coupling setting, the second input jack for the pad can be selected. The coupling is only
  supported for cymbal pad types CY5/6/8.<br/>
  The trigger performance is not yet optimal and still needs some tweaking, i.e., some
  modifications in the code are needed to finish up the support for 3-zone pads.

## 2023-06-27 [[r0.8](https://github.com/corrados/edrumulus/releases/tag/r0_8)] New case for prototype 5

  I bought a new case for my prototype 5 using a Raspberry Pi 3B+. The case was designed
  to use an audio header for the Raspberry Pi but the Edrumulus header fitted well with
  only minor modifications. It works headless, i.e., without any display and buttons. It
  is controlled with a browser on a phone instead. This feature is available with the
  run_edrumulus.sh script using the webui argument.
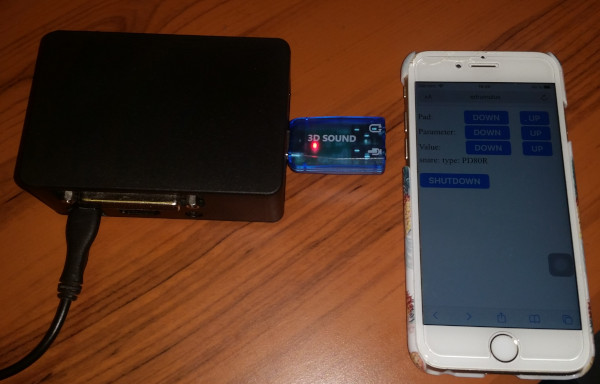
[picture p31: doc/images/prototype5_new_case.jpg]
Edrumulus prototype 5 with new case
  <br/>

## 2023-06-12 [[r0.7](https://github.com/corrados/edrumulus/releases/tag/r0_7)] New clipping compensation

  I finished the new clipping compensation algorithm which is based on the number of clipped
  samples and the average value of the two neighbor samples. Therefore, it supports a continuous
  increase of MIDI velocity values even in case of an overload.

## 2023-04-28 [[r0.6](https://github.com/corrados/edrumulus/releases/tag/r0_6)] Rim shot detection findings

  It seems the assumption that overloaded signals influence the rim shot detection
  performance is not true. Setting max_num_overloads=0 (i.e. rim shots are disabled if
  any clipping is detected) does still give false rim shot detections on the PD-80R in
  case of loud strikes in the middle of the pad. It is quite abvious that hitting the
  piezo cone directly is the real cause of the problem.<br/>
  A test showed that rim_use_low_freq_bp=true works better on the PD-80R. Also, if the
  rim shot detection is not disabled if is_overloaded_state than this does not change
  the rim shot detection behavior on, at least, the PD-80R.<br/>
  I just did a comparison with two PD-80R, where one was connected to Edrumulus and one
  to the Tom1 input of the Roland TD-27. It showed that the rim shot detection performance
  of Edrumulus was at least as good as the TD-27 module. It might be the case that the
  Tom1 input is not as good as the dedicated Snare input of the TD-27.

## 2023-04-18 Added initial support for ESP32-S3

  Initial support for the ESP32-S3 developer board was implemented. Edrumulus runs without crashing
  using 13 ADC inputs. Still outstanding is testing the ESP32-S3 with an analog front-end attached and
  edrum pads connected to it.

## 2023-01-17 Auto start Edrumulus on Raspberry Pi is not trivial

  To auto start Edrumulus on a Raspberry Pi I tried to use the systemctl with:
  ```
  WorkingDirectory=/home/pi/edrumulus/tools
  Environment="JACK_NO_AUDIO_RESERVATION=1"
  ExecStart=/bin/sh -c 'exec /home/pi/edrumulus/tools/run_edrumulus.sh lcdgui >/var/log/edrumulus1.log 2>/var/log/edrumulus2.log'
  ```
  But that gave me a segmentation fault in Drumgizmo. Only running the service as the pi
  user in rc.local has worked:
  ```
  cd /home/pi/edrumulus/tools
  export JACK_NO_AUDIO_RESERVATION=1
  su pi ./run_edrumulus.sh lcdgui &
  ```

## 2023-01-08 edrumulus_gui.py replaces EdrumulusGUI

  The C++ version of the command line Edrumulus GUI is now replaced by an equivalent Python
  implementation. Now, the LCD-GUI can be merged in that file. Also, the settings file
  management can now be implemented in that file giving us a single source implementation.

## 2022-10-16 Multiple head sensors

  The PDA120LS pad has three mesh head piezo sensors which are combined into one output signal.
  I have modified this pad to output each sensor signal separately. On a Git branch I have
  implemented a proof of concept to utilize the multiple head sensor signals to improve the
  positional sensing and eliminate the hot spot problem. The new positional sensing algorithm
  measures the time difference of the first peak location of all three sensors. The transverse
  wave emitted from a strike travells slower than the speed of sound. The measured time difference
  of 20 cm distance is approx. 2 ms or 16 samples at 8 kHz sampling rate. This is enough to
  measure the position with a good precision.<br/>
  The challenge is to detect the first peak of each sensor correctly. Also, since we process
  each sensor separately, it is important to combine the three peaks correctly. Otherwise we get
  double trigger problems. Another issue is to derive the position from the measured distances.
  Right now I am using a simple approximation. This [Youtube Video](https://youtu.be/HZXtSe5p0rs)
  shows how the algorithm performs.<br/>
  A simple way to eliminate the hot spots is to average the detected velocities of all sensors.
  First tests showed that this works very well. The detected velocity is consistent independent
  on the strike position, i.e., even on the edge of the pad and if a piezo sensor is hit directly.

## 2022-08-18 Edrumulus prototype 5 (advanced Raspberry Pi hat PCB)

  The most advanced Edrumulus prototype up to now was build. It is a Raspberry Pi hat design where
  we use a 4 layer PCB. The PCB layout was optimized for minizing the ESP32 ADC spikes and was
  done by [jstma](https://github.com/jstma) (thank you very much for that!).<br/>
  Prototype 5 features a display/button front panel which is stacked on top of the Edrumulus hat.
  First tests showed an improved performance of this prototype compared to other ESP32 prototypes
  where the spike cancellation could be turned off using the same pad threshold settings and also
  almost no "ghost strikes" were seen in the initial test.
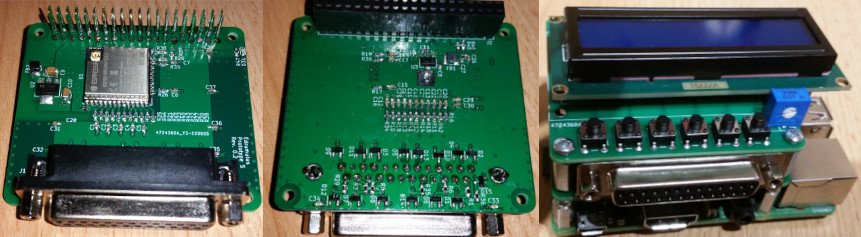
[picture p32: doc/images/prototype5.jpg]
Edrumulus prototype 5
  <br/>

## 2022-08-16 Edrumulus prototype 6 (PCB with audio jacks and DIN5 MIDI ports)

  A new prototype 6 is ready. It uses normal audio jack connectors and features standard DIN-5
  MIDI connectors. The schematics are changed a bit to support a separate voltage regulator
  just for the bias resistors and add some more capacitors to try to reduce the ADC spikes of
  the ESP32. The new MIDI connectors work fine but, unfortunately, the ADC spike reduction was
  not successful. Even with that new design, there are still a lot of spikes visible in the ADC
  readings.<br/>
  Soon, prototype 5 will be ready, too, which uses a much more advanced PCB design to
  eliminate ADC spikes. We will see if that design yields better results.
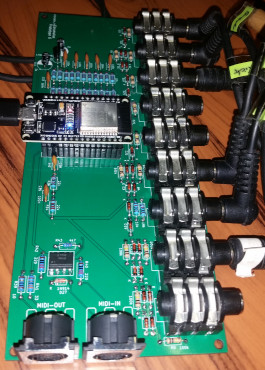
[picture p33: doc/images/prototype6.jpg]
Edrumulus prototype 6
  <br/>

## 2022-08-06 [[r0.5](https://github.com/corrados/edrumulus/releases/tag/r0_5)] Simple overload correction

  A simple signal overload correction is now supported. The initial idea in the TODO list was to
  use a low-pass filter to recreate the clipped peak value. It is quite challanging to find the
  correct filter parameters like cut-off, latency correction, amplitude correction, etc.
  Therefore, a simpler approach was implemented now. We simply count the number of samples which
  are detected to be clipped and assign these numbers to amplification values for the clipped
  estimated peak value. Since the number of clipped samples might be incorrect because of noise
  or even that not only the main peak is clipped but also the second main peak as well, only a
  maximum of 4 dB is amplified and only the steps 1, 2, 3 and 4 dB are supported.

## 2022-08-03 Edrumulus prototype 4 (Raspberry Pi hat PCB)

  There is a new Edrumulus prototype available which uses a custom PCB created with KiCad and
  is intended to be used as a Raspberry Pi hat. It has a DB-25 trigger connector which is
  compatible to the Roland TD9/TD11/TD15/TD25 multicore cable. The usage as a Raspberry Pi hat
  is optional, i.e., this prototype can be used with a PC using a normal USB cable conntected
  to the ESP32 development board. But make sure **not** to attach it to a Raspberry Pi and connect
  the USB cable at the same time! If the prototype is connected to the Raspberry Pi, it gets
  powered from the Raspberry Pi and this would interfere with the power from the PC via the USB
  cable.<br/>
  Unfortunately, there is a hardware bug which has to be fixed by soldering a capacitor
  to the 3.3V and GND near the kick drum input (see the red circle on the last photo), otherwise
  you get false triggering on that input.
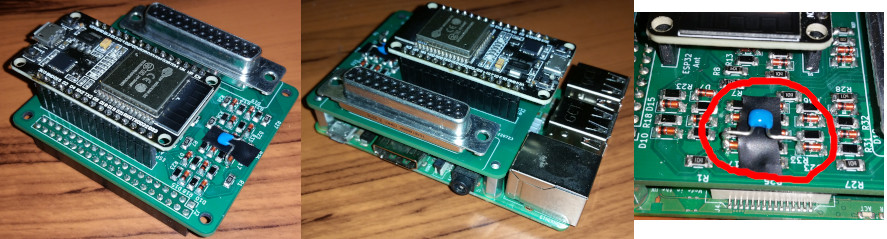
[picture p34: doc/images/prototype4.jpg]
Edrumulus prototype 4
  <br/>

## 2022-07-23 Confusion about the PDA-120LS pad

  My assumption was that all Roland pads with mesh heads do support positional sensing. So, I
  acciently recommended the PDA-120LS for having positional sensing support with Edrumulus.
  After recording a test signal with that pad, I had trouble to find any parameters where the
  positional sensing works at all. Finally, I found out that this pad does not use a center-
  mounted pizeo but three piezos at the edges of the mesh head. That explains why I could not
  get the positional sensing working. So, be careful what kind of mesh head pad you buy if you
  want to have positional sensing.

## 2022-07-02 Youtube video of prototype 3 (HD-1)

  A [Youtube Video](https://youtu.be/tBlKvivwAE4) of Edrumulus prototype 3 (HD-1) is
  now available showing the trigger performance in real action.

## 2022-06-18 Unreliable settings storage on ESP32

  Unfortunately, it seems that the settings storage on the ESP32 does not work as expected.
  On my prototype 3 (HD-1), some settings are not recalled correctly. This especially
  happens if the attached Raspberry Pi must be resetted after, e.g., a freeze. Either the
  sudden power off of the ESP32 is the cause or the Raspberry Pi sends arbitrary MIDI signals
  when it is shut-down. This has to be investigated...

## 2022-01-22 [[r0.4](https://github.com/corrados/edrumulus/releases/tag/r0_4)] Store settings on Edrumulus

  Edrumulus stores all trigger parameter on the micro processor using the Arduino
  EEPROM library now. It is no longer necessary to hard-code pad trigger parameters for
  your prototype in edrumulus.ino. After flashing the new firmware for the first time,
  the settings must be reset. Either use the Linux EdrumulusGUI and press the **r** key
  or use the Octave edrumuluscontrol.m GUI and press the **Reset All Settings** button.

## 2022-01-16 [[r0.3](https://github.com/corrados/edrumulus/releases/tag/r0_3)] New Linux console GUI

  There is a new tool available to show/modify Edrumulus parameters in a Linux (remote) shell
  using the ncurses library. This comes handy if Edrumulus is used with Drumgizmo running on
  a headless Raspberry Pi. This GUI is coded in one single file tools/edrumulus_gui.cpp.
  <br/>Edrumulus console GUI

## 2022-01-09 Edrumulus prototype 3 (HD-1)

  Today was the first time I tested Edrumulus in a full drum-kit setup and
  stand-alone (i.e. no PC or Laptop needed). The prototype 3 consists of an
  ESP32 with 7 pad and 1 control inputs, a Raspberry Pi 3 with a 32 GB SD card
  and a Behringer UFO 202 USB audio interface. It worked pretty amazingly well.
  Of course, there is plenty of room for improvement. But for a first try it was
  a great experience. Even positional sensing was possible with the PDX-8
  mesh pad even that it does not have a center mounted piezo trigger.
  <br/>Prototype 3 (HD-1)

## 2022-01-09 Possible out-of-memory issue for the ESP32

  Today I flashed the current Edrumulus code on my ESP32 and it immediately crashed. After
  disabling the initialization of the last configured pad it did not crash anymore so, I
  assume that we have an out-of-memory issue for the ESP32.

## 2022-01-08 Hot spot detection for mesh head pads

  I was working on a hot spot detection algorithm on a Git side branch recently. As a reference,
  I have used the piezo signal of a PD-80R and PD120 recorded with a conventional audio card.
  These audio card inputs are usually optimized for low impedence microphones. I developed an
  algorithm which worked fine for these signals but did not work at all for running it in
  real-time on a micro controller. The reason for that is caused by the mismatched input of the
  audio card for piezo signals. The shape of the signal is so different that the algorithm
  did not work at all. A new algorithm and further investigations are needed.

## 2021-12-16 Rim shot detection again

  After fixing a bug with the detection of the first peak and introducing a band-pass filter
  for the rim piezo signal of the PD-80R, the rim shot detection is now acceptable (but still
  far from perfect).

## 2021-12-05 New algorithms ready

  The improved peak detection and positional sensing algorithms are now ready and the code
  was merged from a Git side branch to the main branch. By implementing these improvements,
  the source code was heavily changed. Thus, a lot of fine tuning has to be done to, e.g.,
  tweak the pad parameters for the new algorithms and fix possible new issues.

## 2021-11-21 Time to say goodbye, Hilbert...

  The filtered signal currently used for peak detection is a Hilbert filtered signal with
  a moving average low-pass filter applied to it. The initial motivation for this design
  was to reduce the noise and improve the main lobe energy measurement. It turned out that
  it is advantageous to just use the peak value instead of an average.<br/>
  Therefore, we should use an optimized filter which improves the peak detection. To
  reduce the noise floor, a low-pass filter should still be applied. At the same time, some
  high pass filter should be applied to filter out very low frequency noise caused by, e.g,
  the movement of the pad stand after a hit on the pad. Thus, a Butterworth band-pass filter
  with a pass-band of 40 to 400 Hz was chosen. The shorter the pass-band, the longer the filter
  settle time will be. Since the settle time should be as short as possible, it
  is a trade-off between noise reduction and latency.<br/>
  In the following picture, the current Hilbert filter based design is compared to the new
  Butterworth filter design where the peak detection threshold is tweaked for each scenario
  so that no false peaks are detected in the entire signal:
  <br/>Butterworth filter versus Hilbert filter<br/>
  It can be seen that the new Butterworth filter design detects more peaks compared to
  the existing Hilber filter design.<br/>
  Note that the investigation and implementation is currently on a Git side branch. It will
  take some time to finish this work until it is ready to be merged on the Git main branch.

## 2021-10-09 Fixing issues and improving positional sensing
  I am currently heavily changing the Edrumulus code on a Git side branch. I found an issue
  with the moving average filter of the Hilbert filter result and also want to improve the
  positional sensing. As soon as these changes are done, the code will be merged onto the
  main Git branch.

## 2021-10-02 PD-80R investigations
  I just found out that on the PD-80R mesh pad the detected MIDI velocity at the
  edge of the pad is much too small compared to the hit with the same force in the middle of
  the pad. The problem is that there is a moving average of 2 ms applied to the signal which
  is used to find the maximum value. If you play a mesh pad at the edge, the main peak is of
  smaller width compared to the peak if you hit the mesh pad in the middle. Therefore, a lot
  more energy is collected with the long moving average filter for the hit in the middle. To
  fix this issue, the moving average could be shortened to, e.g., 0.5 ms. But if this is
  modified, multiple other problems arise like we have to rise the threshold. This is most
  probably caused by the fact that the longer averaging has filtered away small peaks from
  the ADC noise. Also, the retrigger cancellation does not work as good anymore.<br/>
  To solve the issue, one way would be to use the longer moving average filter for the
  threshold detection and a shorter moving average filter for the MIDI velocity detection.

## 2021-09-28 PD-8 positional sensing does not work
  It turned out that the positional sensing algorithm does not work at all for the
  Roland PD-8 rubber pad. Interestingly, it works quite good for the Yamaha TP-80 rubber pad.
  More investigations are needed to find out the cause of the problem.<br/>
  A detailed view of the curcuit board for the jack sockets which are based on the patchbay is
  shown in the following picture:
  <br/>Jack board

## 2021-09-19 Some project logs
  - One outstanding serious issue is false triggering in case no pad is played. This may be caused
    by electromagnetic interference like if someone switches a light on or it is caused by the
    microcontroller and its ADC itself.
  - In Edrumulus the start of the Scan Time is defined at the first detected peak. Usually, the
    scan time is defined from the point in time when the input signal crosses the trigger threshold.
    It has shown that if, e.g., the trigger is hit directly, we might get strange effects before the
    main peak so that the signal goes above the threshold earlier than for normal pad hits and as
    a consequence, the scan time would not cover the same amount of the regular peaks as with the
    normal pad hits.
  - For the PD80R, the positional sensing must be improved since sometimes a false first peak is
    detected if the piezo is hit directly with the stick (hot spot).

## 2021-07-17 Adding a cross talk cancellation
  Now an experimental pad cross talk cancellation algorithm is supported in
  Edrumulus. This is useful if pads are attached on the same stand and trigger each other.

## 2021-07-04 Improving ADC spike detection algorithm
  Still too many false detections on the ESP32. The ADC spike detection algorithm
  must be improved. A new algorithm development file "adc_spike_cancellation.m" was created.

## 2021-05-15 Hardware support is stable
  After a lot of tweaking, both boards (ESP32 and Teensy) perform good enough now
  so that I can concentrate on the algorithm development again. On the Teensy, I had to disable
  the "keeper" and average multiple ADC samples to get correct and spike free readings. Since
  the ARM core is so fast, there were no problems running the algorithms in real time.<br/>
  For the ESP32 the situation is different. The CPU speed was the limiting factor for a long time.
  Fortunately, I found out that it is possible to run the ADC processing on one CPU core and
  do the signal processing on a different CPU core. That solved the speed issue. I did not find
  a way to suppress the ADC spikes on the ESP32 but I solved the problem in software with a spike
  cancellation algorithm. This solution is not ideal (especially for low velocity hits the
  performance is degraded) but still good enough.

## 2021-05-09 Teensy 4.0 versus ESP32
  There is a new prototype, now using a Teensy 4.0 developer board:
  <br/>Teensy Prototype<br/>
  Difference between ESP32 and Teensy 4.0 with regard to Edrumulus:
  Feature | ESP32 | Teensy 4.0
  --- | --- | ---
  #ADC inputs | 18 | 14
  FPU | yes | yes (better performance than ESP32)
  Speed | 240 MHz dual core | 600 MHz single core
  ADC | 2 ADCs, a lot of spikes | 2 ADCs, less spikes (but still some smaller spikes visible)
  USB MIDI | over serial, needs Hairless MIDI or ttyMidi | shows up as USB MIDI device
  Debugging | either serial debugging or MIDI | MIDI and debugging can be done in parallel
  Cost | ~10 € | ~20 €

## 2021-05-02 Prototype 1 on Youtube
  Here is link to a Youtube video of the new Prototype 1 in action: https://youtu.be/UKeuFm_DDTk
  <br/>I was running [Drumgizmo](https://drumgizmo.org) under Linux on my Laptop with the
  [The Aasimonster](https://drumgizmo.org/wiki/doku.php?id=kits:the_aasimonster) drum kit where the
  snare samples were replaced by Tama Artstar snare samples which support positional sensing.

## 2021-05-01 Minimal drumset prototype
  There is another Edrumulus prototype which is a minimal
  drumset with kick/snare/hi-hat:
  <br/>Prototype 1 minimal

## 2021-04-10 Prototype
  Here is what my current Edrumulus prototype looks like:
  <br/>Prototype 1

## 2021-04-04 ADC spikes of the ESP32
  This is how the ESP32 ADC signal looks like:
  <br/>ESP32 ADC Signals<br/>
  These spikes seem to be a hardware restriction of the ESP32. I am trying to mitigate this
  effect by implementing a spike suppression algorithm.

## 2021-04-03 Using our own analogRead implementation
  The Edrumulus now implements its own analogRead function so we can use
  the newest arduino-esp32 library version (which is 1.0.6 at present time).

## 2021-04-01 Speed tests
  Some speed tests with 6 pads:
  Everything + adc1_get_raw call: **0.368 ms**, Everything: **0.1162 ms**, Without process sample: **0.077 ms**,
  Without analogRead: **0.0455 ms**.<br/>
  Conclusion: The new ESP32 Arduino Library now [uses the IDF driver](https://github.com/espressif/arduino-esp32/pull/3377)
  which is basically the adc1_get_raw function which is very slow as seen in my speed tests. My speed tests also
  showed that the bottle neck is the analog read.

## 2021-03-24 Measurements of hi-hat controllers
  Measurements of hi-hat controllers:
  **VH-12 controller:** open **14 kOhm**, closed **10 kOhm**, pressed **8 kOhm**,
  **FD-8 controller:**  open **50 kOhm**, closed **0 Ohm**.

  **VH-12 MIDI on Roland TD-27**:
  - Strike on the top:
    - MIDI note 42 only at foot pedal MIDI note 127.
    - MIDI note 46 if foot pedal MIDI note is < 127.
  - Strike on the edge:
    - MIDI note 22 only at foot pedal MIDI note 127.
    - MIDI note 26 if foot pedal MIDI note is < 127.

  **FD-8 on Roland TD-6**:
  - Strike on the top:
    - MIDI note 42 if foot pedal MIDI note is >= 85.
    - MIDI note 46 if foot pedal MIDI note is < 85.

## 2021-03-23 Issue with Arduino board manager for ESP32
  I just updated the Ardunio board manager "ESP32 by Espressif Systems" to Version
  1.0.5 and now the code runs much slower on the ESP32 module so that I cannot even run just one
  pad with 8 kHz sampling rate anymore. So I had to revert the board manager version to 1.0.4. I
  hope that with the next board manager update this issue will be fixed and we get back to the
  normal speed on the hardware. For the time being I will stick to version 1.0.4.

## 2021-03-20 Improving retrigger cancellation algorithm
  The retrigger cancellation algorithm is now improved. The decay power is now estimated
  and the decay curve adjusted accordingly. I also bought three used patchbays which have a lot of
  jack sockets which can be used as trigger inputs.
  <br/>Used patchbays

## 2021-02-05 Using Drumgizmo
  I am currently evaluating the great [Drumgizmo](https://drumgizmo.org) software
  to be used in conjunction with Edrumulus. I am in contact with the [main developer](https://drumgizmo.org/wiki/doku.php?id=team) and have
  already written some code to [support ALSA MIDI in Drumgizmo](https://linuxmusicians.com/viewtopic.php?f=56&t=22714).
  I am currently trying to run Drumgizmo on a Raspberry Pi zero but I assume that I will
  need at least a Raspberry Pi 4 to get a decent performance.

## 2021-01-24 Rim shot detection done
  Rim shot detection is now ready but does not yet perform as good as the reference
  Roland TD-20 module. Anyway, by just rotating my PD-120 pad so that I hit the rim approximately
  at the position where the jack plug is located, the rim shot detection works much better now
  since the rim shot piezo is also located close to the jack plug.

## 2021-01-19 Rim shot detection development
  Still working on the rim shot detection using the PD-120 pad. It turns out to be very
  difficult to get a reliable rim shot detection. So, it will take some more time to solve this problem.

  The current project plan is to continue working on making the PD-120 triggering as good as possible.
  If possible, I would like to compare the performance of Edrumulus to the TD-20 by capturing the piezo
  signal together with the MIDI output of the TD-20.

  If the PD-120 triggering is ready, I'll start to support other pad types like the PD-80R and the PD-6.
  Then support kick trigger pads like the KD-8. Finally, the hi-hat/crash/ride pads shall be supported.

## 2020-12-22 Testing BLE MIDI
  Just tested BLE MIDI (i.e. MIDI over bluetooth). I could successfully connect to GarageBand
  on an iPhone. Unfortunately, the bluetooth connection caused some interference in the audio input signal
  so that the threshold had to be increased and also we got a lot of false detections on low velocity hits
  at the edge of the pad. So for future hardware designs some shielding should be considered. Also, I started
  looking at the second piezo signal to support rim shot detection.

## 2020-12-20 Support positional sensing on an ESP32
  The positional sensing algorithm is now also ported to the ESP32 micro controller. I have made a
  new Youtube video using the current implementation (Git commit c796369): https://youtu.be/naP-ODXl9Y0

## 2020-12-18 Running initial algorithms on an ESP32
  I have ported the Octave peak detection code to the ESP32 developer board (a DOIT ESP32 DEVKIT V1,
  no positional sensing yet) and connected it via my PC and Hairless MIDI to my Roland TD-20 module so that
  the snare sound was coming out of the TD-20. This time I could test the performance in real-time. The parameters
  were not yet optimized but still, the results were very promising. Without positional sensing, the ESP32 runs at
  about 56 kHz sampling rate when calculating the peak detection algorithm on one pad. Since I only need 8 kHz
  sampling rate (maybe even 4 kHz is sufficient), we have a lot of headroom for the positional sensing algorithm
  or to add rim shot support and support multiple pads.

## 2020-12-13 Initial algorithm tests
  I am very pleased about the current algorithm performance. The algorithm is not yet fine-tuned but
  already performs pretty well. I have created a short Youtube video of the algorithm (Git commit c83743e) to show
  the current performance in action: https://youtu.be/6eQjCD-DFjo

  The following plot shows how the current status of the algorithms performs. At the beginning there are
  some single hits. Then there follows a region with a snare drum roll. After that, there are single hits
  which start from the middle, move to the edge and go back to the middle of the pad where the hits are
  equally strong. As shown by the black markers, the positional sensing seems to work pretty well. Also,
  the peak detection and velocity estimation seems to be pretty good as well.
  <br/>First results plot

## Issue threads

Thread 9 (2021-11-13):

Circuit question

thijstriemstra, 2021-11-13:
hi, I'd like to give this a try but is this disclaimer still up to date or are there changes to the diagram?

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

corrados, 2021-11-14:
I am no hardware design expert. So, yes, the disclaimer is still valid. All I can say is that it works well for me.

Please note that this schematic does not show you all the needed components nor the input ports to the ESP32 are correct. There is just one schematic given for any piezo trigger and one for the hi-hat controller. If you want to use, e.g., 6 pads with stereo piezo support, you need to build the circuit for the piezo input 12 times and use the correct ESP32 input ports as given in
https://github.com/corrados/edrumulus/blob/10fa7ffbeec366b2b21db8af47cd8eb771b7b096/edrumulus.ino#L60
and
https://github.com/corrados/edrumulus/blob/10fa7ffbeec366b2b21db8af47cd8eb771b7b096/edrumulus.ino#L61

Please also note that Edrumulus is still just experimental software. It works ok but there is still a lot of room for improvement. Also, I only support the pads given in the enum
https://github.com/corrados/edrumulus/blob/10fa7ffbeec366b2b21db8af47cd8eb771b7b096/edrumulus.h#L26
If you have self-made pads, Edrumulus might not perform well at all.

thijstriemstra, 2021-11-14:
i would like to test with my roland cy-5, roland pd-5 and pd-125bk. looks like this project is worth a try so ordering components for this project today!

corrados, 2021-11-14:
Do you want to use the ESP32 or the Teensy? I would recommend the Teensy, actually.

thijstriemstra, 2021-11-14:
i have a esp32 devkit v4 i wanted to use but i can try teensy as well.

thijstriemstra, 2021-11-14:
ps. do you have the source of that fritzing sketch and could you add it to the repository?

corrados, 2021-11-14:
> do you have the source of that fritzing sketch and could you add it to the repository?

Here it is:
[edrumulus_new.zip](https://github.com/corrados/edrumulus/files/7534081/edrumulus_new.zip)

> and any advice on what type of piezo trigger/hhat control ports? A 1/4 stereo jack female pcb mount with 2 pins? or 3?

I am using normal stereo jack ports which are soldered to a small PCB as seen in the following picture: https://github.com/corrados/edrumulus/blob/main/algorithm/images/jackboard.jpg. These PCBs are taken from an old patchbay.

> I really like these: https://www.ebay.com/itm/324731292802

Wow, this looks really professional. Even Roland modules do only use the simply types.

> Also, is it possible to trigger this in a DAW using MIDI?

Edrumulus just sends out MIDI notes over serial to the host PC. If you are using Windows, you need the Hairless MIDI tool to convert it to a MIDI stream which a DAW can use.

In my [Linux script](https://github.com/corrados/edrumulus/blob/main/tools/run_edrumulus.sh), I am using the ttymidi tool and send the MIDI signal to [Drumgizmo](https://drumgizmo.org).

bzass, 2021-11-14:
> If you have self-made pads, Edrumulus might not perform well at all.

Hi, I'm also super impressed by your work - thanks for sharing this project and your active contributions! I would like to give it a try with ESP32 and a custom pad based on the Open Edrums project by Ryo Kosaka. I know that those are not currently supported. Would it be possible for you one day to write or record a short tutorial about your methodology of tuning parameters to the other pads or at least a practical explanation of parameters to allow for manual tuning? That would be much appreciated and make it possible for a broader community to tune them to their pads. Thanks once again!

corrados, 2021-11-14:
> Would it be possible for you one day to write or record a short tutorial about your methodology of tuning parameters to the other pads or at least a practical explanation of parameters to allow for manual tuning?

At present time it would be better that you record a wave file of your piezo trigger signal captured with a sampling rate of 8 kHz and hitting the pad according to the rules defined in https://github.com/corrados/edrumulus/tree/main/algorithm#test-signals. I could then add your wave file in the "signals" directory of the Git repo: https://github.com/corrados/edrumulus/tree/main/algorithm/signals. I could then tune the parameters for you.

> That would be much appreciated and make it possible for a broader community to tune them to their pads.

The problem is that the algorithms are not yet fix. I want to improve the positional sensing and also want to tune some other parts of the algorithm. Each change of the algorithm will most probably require the pad parameters to be adjusted. Therefore it does not make sense to fine-tune the parameters yet.

thijstriemstra, 2021-11-14:
Thanks for the feedback!

>  I would recommend the Teensy, actually.

Any reason? Faster? Cheaper?

> Wow, this looks really professional. Even Roland modules do only use the simply types.

Yea! Found [6 for $14](https://www.ebay.com/itm/124892424978) that I'll give a try.

corrados, 2021-11-14:
> Any reason? Faster? Cheaper?

The ESP32 has some unsolved hardware issues. The ADC multiplexer seems not to separate the inputs good enough. E.g., if I move the Hi-Hat pedal it changes the DC offset of another piezo trigger input which is bad. I did not see such issues with the Teensy. Also, the ADC spikes are much smaller for the Teensy.

bzass, 2021-11-14:
> The problem is that the algorithms are not yet fix. I want to improve the positional sensing and also want to tune some other parts of the algorithm. Each change of the algorithm will most probably require the pad parameters to be adjusted. Therefore it does not make sense to fine-tune the parameters yet.

Thanks a lot for your reply. Fully understood, I will wait for things to get more stable. It would be great to get some docs/tutorials after it happens so that we don't need to bother you with parameters for custom pads.

Thanks again for this great contribution.

thijstriemstra, 2021-11-14:
thanks, didn't know that. I'll get a teensy 4.0.

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

Closed 2021-11-21.

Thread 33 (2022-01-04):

BOARD_LED_PIN definition

thijstriemstra, 2022-01-04:
Currently `BOARD_LED_PIN` is defined in edrumulus_hardware.h. Since my ESP32 doesn't have a builtin LED, [I need to change it to a different GPIO nr](https://github.com/corrados/edrumulus/compare/thijstriemstra_prototype). Ideally I wouldn't want to touch anything in edrumulus source except for the .ino file so my request is to move or add support for defining the BOARD_LED_PIN in the .ino instead, leaving edrumulus source untouched.

corrados, 2022-01-05:
The BOARD_LED_PIN definition is specific to a developer board. E.g., for the ESP32 board I own, it is pin 2 and this should not be changed. That is the reason why it is defined in the edrumulus_hardware header file. You, as an end user, should not change it.

But the current edrumulus code does already support your request in my opinion. The variable which is actually used for the board LED pin is "status_LED_pin" and this is defined in edrumulus.ino file:
https://github.com/corrados/edrumulus/blob/d7a8f19a484a9471233c446e7a2fbfa6572bf7d5/edrumulus.ino#L40

So, you could simply write:
`const int status_LED_pin    = 23;//BOARD_LED_PIN; // internal LED used for overload indicator`
and therefore need no changes in edrumulus_hardware.h.

thijstriemstra, 2022-01-05:
Thanks!

Closed 2022-01-05.

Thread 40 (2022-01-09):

Add version number

thijstriemstra, 2022-01-09:
It would be useful for people using edrumulus in their project to be able to display/determine a version for Edrumulus. For my first prototype, if I add a display, this would be the first thing I want to see when the device is on.

corrados, 2022-01-10:
This is now supported:
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

thijstriemstra, 2022-01-11:
thanks @corrados Only I was more thinking of adding it to `edrumulus.h` which my customized version of `edrumulus.ino` loads. I would expect any user of edrumulus to copy the .ino, make their own adjustments, and include the external edrumulus library (which has the version nr). Your approach would be something the end user uses for their own version nr, e.g. `MyEdrums 0.1`.

thijstriemstra, 2022-01-18:
thanks. can you also use the version number in the changelog (and bump it up when a new changelog entry is added)? And creating a git tag after that would be great.

corrados, 2022-01-19:
Sure. It's done now.

Closed 2022-01-10.

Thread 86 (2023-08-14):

Is Prototype 2 still supported/recommended? (get_prototype_pins)

ryanalexmartin, 2023-08-14:
In this method, there are a few prototype boards listed.  I hand soldered the Prototype 2 circuit, so I'm really hoping I don't need to solder the newer iterations.

If pin 5 is not set to low, then the code defaults to prototype 4.  If I am using the prototype 2 front end circuit, will the pin values and default settings for the prototype 4 board still work correctly?  If so, could this be reflected in a comment in the code?  If not, could prototype 2's PDF be removed, or a disclaimer added?

```
// -----------------------------------------------------------------------------
// ESP32 Dual Core -------------------------------------------------------------
// -----------------------------------------------------------------------------
#ifdef ESP_PLATFORM

int Edrumulus_hardware::get_prototype_pins ( int** analog_pins,
                                             int** analog_pins_rimshot,
                                             int*  number_pins,
                                             int*  status_LED_pin )
{
#ifdef CONFIG_IDF_TARGET_ESP32
  // Definition:
  // - Pin 5 is "input enabled, pull-up resistor" -> if read value is 1, we know that we have a
  //   legacy or custom board. Boards which support the identification set this pin to low.
  // - Pin 18, 19, 22, 23 define a 4 bit sequence which identifies the prototype hardware.
  // NOTE: avoid ESP32 GPIO 25/26 for piezo inputs since they are DAC pins which cause an incorrect DC offset
  //       estimation and DC offset drift which makes the spike cancellation algorithm not working correctly
  pinMode ( 5, INPUT );

  // check support of protoype board identification
  if ( digitalRead ( 5 ) == 0 )
  {
    // read the identification bit field and check the states
    pinMode ( 18, INPUT ); const int bit1 = digitalRead ( 18 );
    pinMode ( 19, INPUT ); const int bit2 = digitalRead ( 19 );
    pinMode ( 22, INPUT ); const int bit3 = digitalRead ( 22 );
    pinMode ( 23, INPUT ); const int bit4 = digitalRead ( 23 );

    if ( ( bit1 == 0 ) && ( bit2 == 0 ) && ( bit3 == 0 ) && ( bit4 == 0 ) )
    {
      // Prototype 5: 0, 0, 0, 0 -----------------------------------------------
      // analog pins setup:               snare | kick | hi-hat | hi-hat-ctrl | crash | tom1 | ride | tom2 | tom3
      static int analog_pins5[]         = { 12,     2,     33,        4,         34,     15,    35,    27,    32 };
      static int analog_pins_rimshot5[] = { 14,    -1,     26,       -1,         36,     13,    25,    -1,    -1 };
      *analog_pins         = analog_pins5;
      *analog_pins_rimshot = analog_pins_rimshot5;
      *number_pins         = sizeof ( analog_pins5 ) / sizeof ( int );
      *status_LED_pin      = 21; // LED is connected to IO21 on prototype 5
      return 5;
    }
    else if ( ( bit1 > 0 ) && ( bit2 == 0 ) && ( bit3 == 0 ) && ( bit4 == 0 ) )
    {
      // Prototype 6: 1, 0, 0, 0 -----------------------------------------------
      // analog pins setup:               snare | kick | hi-hat | hi-hat-ctrl | crash | tom1 | ride | tom2 | tom3
      static int analog_pins6[]         = { 36,    33,     32,       25,         34,     39,    27,    12,    15 };
      static int analog_pins_rimshot6[] = { 35,    -1,     26,       -1,         14,     -1,    13,    -1,    -1 };
      *analog_pins         = analog_pins6;
      *analog_pins_rimshot = analog_pins_rimshot6;
      *number_pins         = sizeof ( analog_pins6 ) / sizeof ( int );
      *status_LED_pin      = BOARD_LED_PIN;
      return 6;
    }
  }

  // if no GPIO prototype identification is available, we assume it is Prototype 4
  // analog pins setup:               snare | kick | hi-hat | hi-hat-ctrl | crash | tom1 | ride | tom2 | tom3
  static int analog_pins4[]         = { 36,    33,     32,       25,         34,     39,    27,    12,    15 };
  static int analog_pins_rimshot4[] = { 35,    -1,     26,       -1,         14,     -1,    13,    -1,    -1 };
  *analog_pins         = analog_pins4;
  *analog_pins_rimshot = analog_pins_rimshot4;
  *number_pins         = sizeof ( analog_pins4 ) / sizeof ( int );
  *status_LED_pin      = BOARD_LED_PIN;
  return 4;
#else // CONFIG_IDF_TARGET_ESP32S3
  // analog pins setup:                 snare | kick | hi-hat | hi-hat-ctrl | crash | tom1 | ride | tom2 | tom3
  static int analog_pins_s3[]         = {  4,     6,      7,        9,         10,     12,    13,    15,    16 };
  static int analog_pins_rimshot_s3[] = {  5,    -1,      8,       -1,         11,     -1,    14,    -1,    -1 };
  *analog_pins         = analog_pins_s3;
  *analog_pins_rimshot = analog_pins_rimshot_s3;
  *number_pins         = sizeof ( analog_pins_s3 ) / sizeof ( int );
  *status_LED_pin      = BOARD_LED_PIN;
  return 4;
#endif
}
```

corrados, 2023-08-14:
That's correct. I just added some clarification in the source code to make it clear, see https://github.com/corrados/edrumulus/commit/6fbba963e4070379057935972f63135191c61021.

corrados, 2023-08-15:
> If so, could this be reflected in a comment in the code? If not, could prototype 2's PDF be removed, or a disclaimer added?

Since I changed the code and added the additional comment, I treat this issue as solved and will close it now.

Closed 2023-08-15.

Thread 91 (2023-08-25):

Floating signal on disconnected ports

3hhh, 2023-08-25:
The input and thus the midi signals generally start to float on ports without drums connected.
Obviously that's not great for testing, broken parts, performances, ...

The available solutions I'm currently aware of:
1. Use a simple pull-down resistor.
    Apparently there's some debate about whether this is advisable for analog inputs (e.g. [here](https://forum.pjrc.com/threads/23522-pull-up-down-and-analog-inputs)), but I guess I'll give it a try sooner or later.
1. Use e.g. cinch connectors with 3 pins where the third pin can be used to deactivate the input circuit ("off switch").
1. Fix it in software by detecting floating input signals and not generate midi output in that case.

Since the second option is not backwards compatible and also doesn't work with the Roland cable, I only consider the other two options viable at the moment.

corrados, 2023-08-26:
> The input and thus the midi signals generally start to float on ports without drums connected.

Does it make a difference if the pad is connected on that port or not? For my prototypes, I have a lot of unused ports but they do not behave differently if a pad is connected or not. Maybe your 100k resistor has long legs and acts like an antenna?

Usually, the power supply of the ESP32 board is responsible for the ghost MIDI notes. E.g., for my prototype 5 which get's its power directly from a raspberry pi and not from the PC USB port, the noise is much smaller and therefore the sensitivity is much better.

If you use a noisy power supply, I recommend to increase the threshold.

ocimjr, 2023-08-26:
Yesterday I was testing with a mac, plugged in a wall with 3 pins plug, and esp32 was plugged in a active usb hub... I was having a lot of spikes and it was impossible to use. I had to put threshold to 31.

Since you said the leg of a component, if it is long, can be an antenna, this can be my problem?
Or should I buy a dedicated power supply to esp32? With so, which one you suggest?

corrados, 2023-08-26:
> I had to put threshold to 31.

That doesn't sound correct at all. I never had it on such high values. Are these channels where you have to set the threshold to 31 are inputs which are not used? I assume that you have the correct resistors/diodes connected to all ESP32 ADC inputs which are used by ESP32. Is this the case?

ocimjr, 2023-08-26:
This only occurs when I have my mac plugged in a wall. I only use 4 inputs. I you don't my I put some photos of prototype

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

Can you check... I change the input on software to match the one on the board.

Thank you

corrados, 2023-08-26:
Have you changed the software to only use these 4 inputs?

ocimjr, 2023-08-26:
Yes ->
Edrumulus.ino
`void preset_settings()
{

  // default MIDI note assignments
  edrumulus.set_midi_notes      ( 0, 38, 37 ); // snare
  edrumulus.set_midi_notes      ( 1, 36, 36 ); // kick
  //edrumulus.set_midi_notes      ( hihat_pad_idx, 42, 22 );
  //edrumulus.set_midi_notes_open ( hihat_pad_idx, 46, 26 );
  //edrumulus.set_midi_notes      ( hihatctrl_pad_idx, 44, 44 ); // Hi-Hat pedal hit
  //edrumulus.set_midi_notes      ( 4, 51, 53 ); // ride (edge: 59, bell: 53)
  //edrumulus.set_midi_notes      ( 5, 53, 59 ); // ride (edge: 59, bell: 53)

  // default drum kit setup
  edrumulus.set_pad_type ( 0, Edrumulus::PDX100 );  // snare
  edrumulus.set_pad_type ( 1, Edrumulus::PDX100 );  // snare
  //edrumulus.set_pad_type ( 1, Edrumulus::KD8 );  // kick
  //edrumulus.set_pad_type ( 2, Edrumulus::CY5 );  // Hi-Hat
  //edrumulus.set_pad_type ( 3, Edrumulus::FD8 );  // Hi-Hat-ctrl
  //edrumulus.set_pad_type ( 4, Edrumulus::CY8 );  // ride1
  //edrumulus.set_pad_type ( 5, Edrumulus::CY8 );  // ride2
  //edrumulus.set_coupled_pad_idx( 4, 5 );
}`

and in edrumulus_hardware.cpp

`Edrumulus_hardware::get_prototype_pins
// if no GPIO prototype identification is available, we assume it is Prototype 4
  // analog pins setup:               snare | kick | hi-hat | hi-hat-ctrl | ride1 | ride2
  static int analog_pins4[]         = { 32 ,   34}; //33,     32,       25,            34,    12 };
  static int analog_pins_rimshot4[] = { 33 ,   35};//-1,     26,       -1,            27,    -1 };
`

corrados, 2023-08-26:
Ok, these software changes look ok.

> Or should I buy a dedicated power supply to esp32? With so, which one you suggest?

The problem is that you need the USB connection to the PC to receive the MIDI notes. In prototype 5, I use a serial connection to the Raspberry Pi and therefore can power the ESP32 differently.

As I mentioned in another thread, you might try to use a powered USB hub. Maybe the power supply of these hubs are a little bit less noisy.

ocimjr, 2023-08-26:
I'm already using a powered usb hub, I saw that thread. So, I'm running out of ideas.

Get Outlook for Android<https://aka.ms/AAb9ysg>
________________________________
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

ocimjr, 2023-08-26:
This is a plotter from ports 32 and 33. More in the region of 2000 and some spikes from 2100 and I event saw 2600

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

corrados, 2023-08-27:
These peaks look too high. I've never seen such high peaks on my prototypes. Maybe you have a cell-phone right next to your prototype or something else which does a lot of electrical interference. I can see that you have a slightly different ESP32 board than me. Mine has a bit less inputs. Maybe the power unit is different and makes more noise?

ocimjr, 2023-08-28:
No cellular is not near or other source of interference.
I bought a expansion board that has a power supply. I should receive in 2 weeks time. I'll this will solve the issue. I update you when i received. Thanks again for your help.

3hhh, 2023-08-29:
> Does it make a difference if the pad is connected on that port or not? For my prototypes, I have a lot of unused ports but they do not behave differently if a pad is connected or not. Maybe your 100k resistor has long legs and acts like an antenna?

I haven't seen this issue yet neither and one of my tests indeed shows a zero signal without a pad connected. Now that I look at the prototype 2 diagram again I also see that a constant 1,65V should be at the ADC when there's no signal, i.e. practice confirmed theory.

I think I always misunderstood the manual sentence:
"If Edrumulus is installed on the micro controller and there is no analog front end circuit attached, you will get a lot of false triggering (i.e. a lot of MIDI notes). For the Edrumulus system to work correctly, all configured ADC inputs must have the analog front end circuit attached."

Apparently you meant the front end circuit without the pads...

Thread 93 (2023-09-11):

Analog circuit

3hhh, 2023-09-11:
As already discussed, I'm pretty sure that the analog circuit is not optimal and likely doesn't work for everyone.
E.g. for me the proposed 22k voltage divider produced a rather bad SNR leading to many other issues.

The differences mostly come from the unknown Piezo output voltage range, which may be +- 0,1-10V.
The effective voltage range depends on:
- piezo hardware (size, thickness)
- trigger cushion foam (i.e. the maximum velocity at which a user can possibly hit the piezo)

In my particular case the voltage range of the piezo seems to be around +-1V and rarely more. This can be measured rather easily by plugging the piezo to the line in which runs at +-1V range. If there's no clipping, then you're apparently in that range.

I played a bit with the apparent industry-standard software [LTSpice](https://www.analog.com/en/design-center/design-tools-and-calculators/ltspice-simulator.html) to find a set of parameters that may work for me and interestingly found quite a different one from the proposed parameters.

Here's a comparison of the parameters proposed by edrumulus and the seemingly better ones for my case (+-1V, 2kHz spikes):
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
[simulation (needs to be renamed to edrumulus.asc)](https://github.com/corrados/edrumulus/files/12576561/edrumulus.txt)
(The C3=1p case is roughly identical to what edrumulus does = no capacitor.)

One can see that the voltage range in the edrumulus example is ~0,3V, whereas it could be ~2V as in the second example. Of course that also affects the SNR.

Therefore imho it would be more honest to tell people that they need to play with the parameters to find a circuit that may work for them.

Disclaimer: I still need to validate the simulation in practice.

corrados, 2023-09-11:
> If there's no clipping, then you're apparently in that range.

Some clipping is allowed. I have implemented a clipping compensation in software.

> Therefore imho it would be more honest to tell people that they need to play with the parameters to find a circuit that may work for them.

This is the current disclaimer on the main page:

**DISCLAIMER All these circuit diagrams are used for my first prototypes and work fine for me. Use them at your own risk.**

If you want to see a different text then please make a proposal.

corrados, 2023-09-11:
BTW, I may convert this Issue in a Discussion thread later on because as soon as I close it, most people will not find the investigation results you have given in your initial post. I assume that new users will only check for help in the Discussion forums.

3hhh, 2023-09-12:
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

I guess "In particular the circuits may not work for currently unsupported pieces of hardware." might be fair enough for a disclaimer.

However additionally some documentation on how to support new pieces of hardware would've been clarifying and helpful.

Currently the steps appear to be:

1. Start with prototype2 & optimize the analog circuit (atm it is unclear to me how to do that apart from random testing; I might know more once I can verify my simulation in practice).
2. Create samples for the edrumulus Octave model according to the existing doc. Probably getting them from the edrumulus hardware itself is more realisitic than from whatever sound card.
3. Analyze the samples in the Octave model to identify the edrumulus parameters. We discussed that in the forum.
4. Set the identified parameters in the edrumulus C++ code and test them in practice. Modify the available real-time parameters for hopefully better results. Possibly go back to previous steps.

corrados, 2023-09-12:
> I guess "In particular the circuits may not work for currently unsupported pieces of hardware." might be fair enough for a disclaimer.

done

3hhh, 2023-09-15:
Nice, thanks!

Btw I tested it in practice and unfortunately I couldn't record a signal that looked significantly better than previous ones (maybe there's some generic issue with the way I'm recording, idk). However I could lower the edrumulus threshold from an unusable 20 to around 10. Therefore I guess I'm going to stick with Rs=1k, Rp=100k, Cp=0 for the MPS 750x Tom for now. Cp dampens the gain as expected, but it doesn't look like I need it for the MPS 750x Tom.

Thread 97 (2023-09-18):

spike cancellation looks like a local parameter, but is a global one

3hhh, 2023-09-18:
[edrumulus_parameters.cpp](https://github.com/corrados/edrumulus/blob/f63b367f78c7ee1b8e91e68009a4e7668ca356ec/edrumulus_parameters.cpp) currently has no way of setting the spike cancellation parameter.

According to https://github.com/corrados/edrumulus/blob/f63b367f78c7ee1b8e91e68009a4e7668ca356ec/edrumulus.cpp#L31-L35 it should be set to 4 for ESP32 and to 0 for Teensy. However edrumulus_gui.py sets it to 4 when opened.

(I want to permanently set it to 2 for one of my pads.)

corrados, 2023-09-18:
> I want to permanently set it to 2 for one of my pads.

Spike cancellation is a global parameter and cannot be set for each pad separately.

> it should be set to 4 for ESP32 and to 0 for Teensy. However edrumulus_gui.py sets it to 4 when opened.

edrumulus_gui.py stores the current parameters in a settings file and recovers these settings on the next start. If you change the spike cancellation to 2, close edrumulus_gui.py and re-open it, is it then set to 2 or to 4?

corrados, 2023-09-18:
> Hm then maybe edrumulus_gui.py is misleading as it allows setting this per pad.

It's a bit of a hack. edrumulus_gui.py does not support global parameters. If you change the spike cancellation on one pad in edrumulus_gui.py, it will be changed on all other pads, too.

> Also it's a bit weird that it apparently overwrites the C++ define, which would be in place without edrumulus_gui.py starting.

This is the case with all user parameters. I am always using edrumulus_gui.py to manage all the trigger parameters.

> I also want to set the default because I'm pretty sure I'll forget about this setting after using it for a longer while...

Then you have to decide: Either use edrumulus_gui.py and let this tool manage all the parameters or do not use edrumulus_gui.py at all and only use hard-coded parameters in the Edrumulus firmware.

corrados, 2023-09-18:
> it should be set to 4 for ESP32 and to 0 for Teensy. However edrumulus_gui.py sets it to 4 when opened.

BTW: If you checkout the Edrumulus Git repo and did not change any parameter manually in edrumulus_gui.py, you are using my trigger settings which I am using for my current testing. This is the reason you are seeing a 4:

https://github.com/corrados/edrumulus/blob/6876846aedd3711f255a8a6c53989b148718fbea/tools/settings/trigger_settings.txt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

(110 is the MIDI note for the spike cancellation setting)

In this file you can also see that all pads have the same value, e.g.,
https://github.com/corrados/edrumulus/blob/6876846aedd3711f255a8a6c53989b148718fbea/tools/settings/trigger_settings.txt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
and
https://github.com/corrados/edrumulus/blob/6876846aedd3711f255a8a6c53989b148718fbea/tools/settings/trigger_settings.txt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

corrados, 2023-10-26:
I have now implemented an additional label for the "spike" parameter to make it clear that it is a global and not a pad-specific parameter:

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

3hhh, 2023-10-26:
Thanks, looks good to me! :-)

Closed 2023-10-26.

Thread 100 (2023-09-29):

Rim signals may be too strong for edrumulus

3hhh, 2023-09-29:
My MPS750x ride generates a rim piezo signal that is very strong. Setting the rim boost to 0 and the rim threshold to 31 still produces bad results (too many rim triggers).
It would therefore be good to have higher threshold or negative rim boost available.

Alternatively I could of course dampen the signal in hardware, but imho having a strong signal available shouldn't be a disadvantage.

By the way that's how one might distinguish bell, bow & rim on that ride: If the rim signal is weak (currently rim boost 0, rim threshold 31), it's probably the bell, if it's mediocre, it's the bow, otherwise the rim.
Possibly Millenium still does it differently though.

corrados, 2023-09-29:
> My MPS750x ride generates a rim piezo signal that is very strong

Are you shure that it is a piezo which detects the rim signal? I would have assumed that it is a switch and not a piezo. How have you setup your pad paramters? You can configure if it shall be a rim pizeo or rim switch.

3hhh, 2023-09-30:
I just updated the MPS750x branch so that you can see it for yourself.

corrados, 2023-09-30:
This is a recording of my PD-8 pad which definitely has a switch and no piezo on the second channel (first channel is the head piezo, second channel is the rim switch):
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
It looks very similar to what is in your file mps750x_ride_all:
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
I am very sure that you also have a switch and no pizeo on the rim.

corrados, 2023-09-30:
On test you could do is to measure the resistance of the rim if you have a multi-meter at hand. Then you can measure the Ohms when the pad is not touched and measure the Ohms when you press the choke (i.e., press the edge of the cymbal as if you would choke a real cymbal) which should close the rim switch.

3hhh, 2023-09-30:
Kk, I'll see whether I can do that.

Anyway [this line here](https://github.com/corrados/edrumulus/blob/b0b166b8f097994ed9c09867722e050e4969f20e/edrumulus.cpp#L502) only allows at most 10^((31-44)/10) = 5% as threshold.

corrados, 2023-09-30:
Yea, you are right. I think I have to fix this, soon. It's already too long on my [TODO list](https://github.com/corrados/edrumulus/blob/a12022450183326117c2aa946cc758a870b7e79f/doc/TODO.md?plain=1#L46) :-).

corrados, 2023-09-30:
Ok, TODO is done now: https://github.com/corrados/edrumulus/commit/55516d7516f6b2bb02411829039922a2fb868ff1

corrados, 2023-09-30:
> Anyway [this line here](https://github.com/corrados/edrumulus/blob/b0b166b8f097994ed9c09867722e050e4969f20e/edrumulus.cpp#L502) only allows at most 10^((31-44)/10) = 5% as threshold.

BTW, the line you referenced is for piezo rim triggers but you have to set your pad to rim switch which then uses the new formula I have just changed.

3hhh, 2023-10-02:
> On test you could do is to measure the resistance of the rim if you have a multi-meter at hand. Then you can measure the Ohms when the pad is not touched and measure the Ohms when you press the choke (i.e., press the edge of the cymbal as if you would choke a real cymbal) which should close the rim switch.

The resistance goes down from MOhm to 0 on the choke. I guess that indicates it's a switch?

corrados, 2023-10-02:
Yes, definitely. It's a switch.

3hhh, 2023-10-03:
Thanks for the update!

It kind of works now.
"Kind of" because it's less reliable than with the original module: E.g. if I hit the bell or bow with medium velocity, edrumulus will trigger a rimshot.

corrados, 2023-10-03:
I assume you are using the same resistors for the rim switch as for the piezos, right? Maybe it makes sense to play a bit with the resistor values to improve the rim switch detection.
In my setup with Roland pads, the same resistors work fine for piezo and switch but that may not be the case with your Millenium pads.

3hhh, 2023-10-04:
The signal and SNR is just fine, i.e. there's no need to play with the resitors at the moment. However I verified with my sound card that there is a rim signal whenever I hit the bell. That signal has roughly the same strength as the one I get whenever I hit the rim, which imho indicates that Millenium uses a different algorithm to identify rim, bow and bell. Hitting the bow also triggers the rim signal, albeit at a much lower level.

Anyway the original issue was fixed, i.e. this one can be closed.

Closed 2023-10-04.

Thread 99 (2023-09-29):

Disconnecting a rimshot input makes regular hits become rimshots

3hhh, 2023-09-29:
1. Use a pad with `pad_settings.rim_shot_is_used = true;` and possibly `pad_settings.rim_use_low_freq_bp = false;`.
2. Notice that everything works as intended.
3. Physically disconnect the rimshot input cable.
4. Notice that regular hits on the pad play the rimshot Midi note instead of the regular Midi note.

This may be a programming mistake or an instance of #91 on the rimshot input, idk.

corrados, 2023-09-29:
Have you tried to adjust the rim shot threshold to mitigate the incorrect rim shot detection on a disconnected cable?

3hhh, 2023-10-02:
> Have you tried to adjust the rim shot threshold to mitigate the incorrect rim shot detection on a disconnected cable?

Yes, but reliably only with a threshold of 31.

corrados, 2023-10-02:
Is it a rim switch or a piezo on the rim?

3hhh, 2023-10-02:
I tested it with the snare, i.e. pieo.

corrados, 2023-10-02:
Are you sure the piezo is directly connected to Edrumulus input? Because a piezo has a high resistance, see e.g. [this page](https://www.f3lix-tutorial.com/piezo-materials): "_A piezo material is basically an insulator. That means the internal Resistance is extremely high._".

I.e., if the piezo is directly connected, it should not make a difference if it is connected to Edrumulus or not.

corrados, 2023-10-02:
But anyway, this is actually not a supported use case for Edrumulus. You either connect your dual-trigger pad with a stereo jack connector to an Edrumulus input. Therefore, always both piezos or no piezo is connected. If you permanently want to disconnect the rim piezo, you simply configure the pad in Edrumulus as a single-trigger pad.

3hhh, 2023-10-02:
I don't want to permanently disconnect it. This is once again about accidents that may happen during playing.

The only good thing about this behaviour is that one probably notices it rather quickly.

A piezo that is not being hit is essentially a capacitor. That should explain why it makes slightly unsteady 1.65V from a power supply more steady.

3hhh, 2023-10-03:
So essentially you're saying that this is an instance of #91.

To prevent #91, only band pass filtering or some application logic such as "if there are more than X (configurable per port) triggers per second from a single port, disable that port & inform the user".

3hhh, 2023-10-04:
My signal and SNR seem very fine since I use Rp=100k, Rs=1k, velocity threshold 2 & high sensitivity. I could even remove the powered USB hub and power the Teensy from a desktop PC USB port without noticing any difference.

We digress though. If you don't want to fix that issue, that's fine as well. It's your call after all.

3hhh, 2023-10-11:
> My signal and SNR seem very fine since I use Rp=100k, Rs=1k, velocity threshold 2 & high sensitivity. I could even remove the powered USB hub and power the Teensy from a desktop PC USB port without noticing any difference.

Looks like I need to revise that as once I connect more than just the snare, I have a lot of noise in my circuit. Is this a common well-known issue or do I have to suspect that my circuit is bad somewhere?

corrados, 2023-10-11:
> I connect more than just the snare, I have a lot of noise in my circuit

I do not have such an issue with my ESP32 prototype even if I connect multiple pads to it.

3hhh, 2023-10-12:
So I kept the circuit & kick input pin stable (A0) and moved the snare pin around for testing on a Teensy 4.1.

The results are very confusing:
Snare on A9/A8 produces the aforementioned noise (but only with the kick connected), snare on A10/11 has less noise, same on A17/18 and snare on A14/15 (I tested https://github.com/corrados/edrumulus/pull/103) runs into ADC max (the LED blinks) on medium velocity hits. All of that just by recompiling edrumulus with new pin numbers and moving the snare input cable around.

Why does the ADC quality depend so much on the input pin? Any ideas what to try?
I'm lost.
Btw it's not the Teensy power input - I even ran it on batteries and experienced the aforementioned noise.

corrados, 2023-10-12:
> snare on A14/15 (I tested https://github.com/corrados/edrumulus/pull/103) runs into ADC max (the LED blinks) on medium velocity hits

That's a very interesting find. Maybe that is the reason why you were not happy with my analog front end design and selected your own resistor values. Maybe the reason was that your Teensy input was somehow attenuated causing the problems.

I have a Teensy 4.0 which works fine with the Edrumulus code. Obviously, there seem to be some incompatibilities between Teensy 4.0 and Teensy 4.1, unfortunately.

I can see in your code (https://github.com/corrados/edrumulus/pull/103) that you did changes at the ADC configuration. The "MIMXRT1062DVL6A keeper" gave me headaches when I was trying to support the Teensy. In your code I see that you use "INPUT_DISABLE". Do you really want to disable the inputs? Or is it to disable the keeper?

One reason for the effects you see could be (which I do not hope) that your hardware has a defect. Maybe some high spikes from the piezos did harm the inputs.

3hhh, 2023-10-12:
> That's a very interesting find. Maybe that is the reason why you were not happy with my analog front end design and selected your own resistor values. Maybe the reason was that your Teensy input was somehow attenuated causing the problems.

> One reason for the effects you see could be (which I do not hope) that your hardware has a defect. Maybe some high spikes from the piezos did harm the inputs.

Yes, maybe you're right that my Teensy is broken - especially since I noticed that I hadn't [minded the gap](https://www.youtube.com/shorts/QerwqYASMLg). ^^
So the Piezo may well have sent some negative voltages to the ADC input for a while.
On a side note: If that bricks the Teensy, I wonder whether the Teensy may brick when it's switched off and someone plays the drums for fun (e.g. kids)?
Anyway my parameters apparently even somehow work without the voltage divider lol.

> I can see in your code (https://github.com/corrados/edrumulus/pull/103) that you did changes at the ADC configuration. The "MIMXRT1062DVL6A keeper" gave me headaches when I was trying to support the Teensy. In your code I see that you use "INPUT_DISABLE". Do you really want to disable the inputs? Or is it to disable the keeper?

It disables the keeper. I also removed the pin-specific code as the ADC library should do it better anyway. The ADC library e.g. also implements load balancing between the ADCs.

corrados, 2023-10-13:
> It disables the keeper. I also removed the pin-specific code as the ADC library should do it better anyway. The ADC library e.g. also implements load balancing between the ADCs.

More than two years ago, I have used the same functions as you now do but this was my comment: "try to disable keepers [...] seems not to work".
See https://github.com/corrados/edrumulus/commit/e66203f994f48930c29f1bcef8db23c44383e186.
And after that, I introduced the direct modification of the registers instead:
See https://github.com/corrados/edrumulus/commit/f52ad6018cc71ce0bc0395f0ca8d91faec11d891.

So, obviously, I was not happy with this function. I cannot remember the details but it certainly had a good reason to modify the registers directly because I also prefer to use the API functions normally.

3hhh, 2023-10-13:
Hm I now tested the Teensy with the voltage divider connected to several pins and some simple analogRead() code and the voltage continually degrades from 1.65V to 1.4V and possibly less. I'd say it's gone for good...

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

I'm pretty sure you were unhappy because it didn't work as you attempted to use analog pin numbers with `pinMode()`, which only accepts real pin numbers.

corrados, 2023-10-14:
> I'm pretty sure you were unhappy because it didn't work as you attempted to use analog pin numbers with pinMode(), which only accepts real pin numbers. At least that's what the incorrect code you referenced indicates.

No, it was not about the pin numbers. That worked fine for me all the time. It really was about strange behavior of the ADC input.

Maybe your Teensy is not dead but just is not configured correctly and shows a weird behavior caused by this. Can you upload an official example source code from the Teensy page which makes use of the ADC to check if they are really broken?

3hhh, 2023-10-14:
> Maybe your Teensy is not dead but just is not configured correctly and shows a weird behavior caused by this. Can you upload an official example source code from the Teensy page which makes use of the ADC to check if they are really broken?

My tests were done with a slightly modified version of the official code from https://github.com/pedvide/ADC/blob/master/examples/analogRead/analogRead.ino

I'll also check the replacement I ordered with that code, i.e. I'll then know for sure.

corrados, 2023-10-15:
I recommend to start with my values of the resistors first since I use these schematics for a long time and very happy with it. It has a 100k resistor in series and that should also protect the Teensy/ESP32.

3hhh, 2023-10-15:
On 10/15/23 12:53, Volker Fischer wrote:
> I recommend to start with my values of the resistors first since I use these schematics for a long time and very happy with it. It has a 100k resistor in series and that should also protect the Teensy/ESP32.

Hm yes, my values are indeed somewhat more risky. However I believe that the clamping diodes are the real issue, not the series resistor:
The clamping diodes may need 0,6-0,7V to short, thus leaving the input at ~4V, but the Teensy ADC only supports -0,3V-3,6V. Your 100k series resistor mitigates the issue by almost always making the clamping diodes useless (the input voltage would need to be _really_ high to make the clamping diodes short). With 1k, I rely on them, but that may be a false sense of security as indicated above... A real solution wuld be another voltage divider to make the diodes short at 3,3V, but of course that's not great on a breadboard - possibly suitable for your PCB designs though.

On a plus side, my values should be a lot better at low piezo input voltages as you drop ~100/122 = 81% input signal voltage on your 100k series resistor whereas I only drop ~1/101 = 1% there. Possibly I could live with Rs=100k, Rp=100k and thus drop ~50% at Rs. Or choose Rp higher, but that produces other issues with the ADC, which needs low input impedance to be able to draw current quickly enough (one might be able to mitigate those issues with a capacitor I read, but oh well...).

corrados, 2023-10-15:
I was just curious if you are happy with my schematics if the Teensy is ok (and not broken) because I would like to know if the Millenium pads really have such a lower output voltage compared to the Roland pads.

Closed 2023-10-20.

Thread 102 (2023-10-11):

Teensy: High pins don't work

3hhh, 2023-10-11:
I just wanted to use pin A17 on a Teensy 4.1 and it didn't work.

I think the reason is that analogRead(17) reads pin 17, which is A3. Teensy forums suggest to use analogRead(A17) instead, but putting A17 as pin for edrumulus didn't work neither. Possibly A17 is defined by some non-Teensy include, I don't know.

According to the Teensy forums this behaviour applies to all pins >= 14. Maybe it even applies to all Arduino boards?

https://forum.pjrc.com/threads/64046-Cannot-find-A14-A17-on-a-Teensy-4-1
https://forum.pjrc.com/threads/54963-trouble-reading-Analog-pins-A14-and-above

3hhh, 2023-10-11:
Btw I also tried with pin `41` instead of `17` and `A17` and that didn't work neither.

Closed 2023-10-24.

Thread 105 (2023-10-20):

Hihat stomp is weak and cannot be mixed alone

3hhh, 2023-10-20:
The hihat stomp output was rather weak during my tests compared to the hihat hits.

This could be fixed by postprocessing it with a mixer; however edrumulus currently uses the same Midi note for a stomp as for a hit on the hihat.

Imho it would be better to use different notes, so that such volume issues can be fixed during postprocessing.
Also, stomping sounds slightly different from hitting a hihat in practice, i.e. one might want to use different samples anyway.

corrados, 2023-10-20:
There is a separate MIDI not for Hi-Hat stomp action, see https://github.com/corrados/edrumulus/blob/e8c524a2bbbc87cd74a47a6215480357342b2832/edrumulus.ino#L107

3hhh, 2023-10-21:
Thanks for the hint!

During my testing I had noticed 4 different notes for the hihat: Two for hits on bow and edge and another two for the open/closed bow/edge variant.
Maybe my stomps aren't detected?
I'll investigate further....

3hhh, 2023-10-22:
> Maybe my stomps aren't detected?

Yes, they weren't detected. I managed to fix it by setting a high threshold & sensitivity for the control port.

With a lower threshold I could observe my hihat pedal movements on the screen, which was really nice and would easily enable half-open hihat Midi notes, if one wanted to support that feature.

Anyway this particular issue is invalid.

Closed 2023-10-22.

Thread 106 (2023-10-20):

Pos sensing only works with middle piezo

3hhh, 2023-10-20:
The Millenium MPS750x snare has its piezo at the top of the pad.

This has the advantage of a reduced hot spot effect, but doesn't work so well with edrumulus pos sensing, which currently assumes the piezo to be located in the middle of the pad.

It would be nice to support pads with piezos at the top.

I believe a simple version might be possible by translating the current pos sensing as follows:
middle --> edge
edge --> edge
everything else (somewhere in between) --> middle / reduce distance to edge by 50%

I'll test that once I have some time.

corrados, 2023-10-20:
The PDX-8 has the piezo on the bottom of the pad. You can tweak the positional sensing to work of for that pad with the existing parameters pos_threshold and pos_sensitivity.

3hhh, 2023-10-21:
> The PDX-8 has the piezo on the bottom of the pad.

But in the middle, isn't it?

> You can tweak the positional sensing to work of for that pad with the existing parameters pos_threshold and pos_sensitivity.

Yes, I noticed that it produces some consistent values.
However obviously it believes the middle to be at the top.
It should be possible to adapt that behaviour though.

corrados, 2023-10-21:
>>    The PDX-8 has the piezo on the bottom of the pad.

> But in the middle, isn't it?

No, it is at the bottom.

> However obviously it believes the middle to be at the top.

No, it does not. I just outputs the distance to the piezo. More information you cannot extract from a single sensor.

ignotus666, 2023-10-21:
This was with a Megadrum, but I was able to get positional sensing working with a side-mounted trigger. The trick was to install a cone (no sensor) in the centre. You can see how it performed [here](https://youtube.com/watch?v=rB1VslJnXjE&si=jxRTz72flsqtkOcD).

corrados, 2023-10-21:
That's a nice trick, thanks for sharing.

3hhh, 2023-10-30:
> It just outputs the distance to the piezo. More information you cannot extract from a single sensor.

I then wonder how the PDX-8 behaves when you get close to the bottom. Does it correctly identify it as edge?
I guess not as that would contradict your distance statement.

So if a signle piezo can just measure the distance - which makes sense to me -, this problem cannot be solved in software only anyway (if you draw a circle on the top of a pad you'll notice that it hits both edges, but the middle as well - how should one decide then?) and I guess my current settings with the top piezo are as good as they can get.

corrados, 2023-10-30:
> I guess not as that would contradict your distance statement.

That's correct. If you hit at the bottom, it detects it as the center. You have to adjust the positional sensing parameters in a way that the actual strike in the middle position is detected as the middle position so that if you move to the bottom, the position does not change. Just if you move towards the upper edge, the position is detected as edge. This is the best you can do with a piezo which is not mounted in the middle (or you use the trick suggested by ignotus666 but this would require to change the hardware).

3hhh, 2023-10-30:
Ok, then this won't be implemented and can be closed.

Closed 2023-10-30.

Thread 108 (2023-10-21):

edrumulus_gui.py removes trigger settings, if killed

3hhh, 2023-10-21:
To reproduce:

1. Start `edrumulus_gui.py`.
2. E.g. remove the Teensy controller from USB to make it hang (this may be a separate bug of its own).
3. Kill `edrumulus_gui.py`
4. Notice that the `trigger_setting.txt` is 0 bytes.

corrados, 2023-10-22:
This is annoying. Thanks for reporting. I have just implemented a fix for this issue.

3hhh, 2023-10-23:
Nice, thanks!

Closed 2023-10-24.

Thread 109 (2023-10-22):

cross talk cancellation doesn't work reliably

3hhh, 2023-10-22:
My set has a lot of cross talk and setting all cross talk values of all pads to 31 still doesn't fix it.

I even set the cancellation time to 100ms, but I still observed cross talk on e.g. hard snare rim shots.

Imho the issue probably lies with the [algorithm](https://github.com/corrados/edrumulus/blob/a6489c6a952ec3fcea3d6e65bf15fbdb5d347c6c/edrumulus.cpp#L300-L326):
If I understand it correctly, it simply checks whether there were higher spikes in the past. However I observed in practice that cross talk spikes may actually arrive _before_ the spike of the pad I actually hit. This is not taken into account by the current algorithm. Of course that would involve holding back the Midi output, which in effect introduces a latency.

corrados, 2023-10-23:
> However I observed in practice that cross talk spikes may actually arrive before the spike of the pad I actually hit

That is very interesting. I have not experienced such an issue with my setup.

Initially, I thought this would make no sense because if I hit a pad and this triggers another one, the pad which is hit should always be the first to trigger since it will take some time for the audio wave to travel from the original pad to the pad which give a false trigger. But this is just the view of the physics. It may happen that the pad configurations are different between the two pads (e.g. scan times) which can lead to the case that the original pad generates a MIDI signal after the other pad.

Hmm. As you wrote, introducing latency is not a good thing.

3hhh, 2023-10-23:
I was considering to fix it by piping the edrumulus Midi output to Ardour and using a Midi cross-talk cancellation plugin there, then pipe it to drumgizmo. I'm unsure how well that setup will perform though...
Also it seems that there's no such pre-made Midi plugin out there (I found a native one for Reaper, but that's it).

corrados, 2023-10-23:
Interesting concept of using an external tool to mitigate cross-talk. If that works, other similar projects like, e.g., eXaDrums could also use it.

3hhh, 2023-10-28:
I'll test [this filter](https://gist.github.com/3hhh/640e66a959f21b074bafb289fc1887cf) for now.

corrados, 2023-10-30:
Great. Please update us in this thread how it works and how happy you are with that solution.

3hhh, 2023-11-03:
I noticed some delay on fast hihat pedal stomps. I guess those cause the most MIDI messages to be created and can  overwhelm the script. Since that happened on a rather fast machine I guess it won't work too well on a raspberry pi.
However I improved the script a bit in the latest version, so that it's harder to run into the issue.
Possibly multithreading might help, too.

Anyway in total I'm pretty happy with it so far.

corrados, 2023-11-03:
Thanks for the feedback. Maybe it's now time that you create a post in [this discussion thread](https://github.com/corrados/edrumulus/discussions/28) ;-)

3hhh, 2023-11-04:
Fyi: I just fixed the code causing the aforementioned issues.

3hhh, 2023-11-11:
New repo: https://github.com/3hhh/xtalk

corrados, 2023-11-11:
Great :-). I have just added your repo as a sub-module in the edrumulus/tools directory.

giff25, 2025-05-27:
Id like to take a spin at the problem but im struggling to know where to start. Is the crosstalk between different pads or between different sensors on each pad? either way why does it occur?

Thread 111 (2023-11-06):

cymbal choke causes rim triggers

3hhh, 2023-11-06:
Using the cymbal choke currently causes low volume rim triggers (usually two or so).

Also, holding the choke sometimes seems to just delay playback rather than stopping it. The latter may be a drumgizmo issue though.

corrados, 2023-11-07:
Yes, this is true. I can see this with my Roland cymbal as well. But it is not noticeable during my normal playing.

The choke detection in Edrumulus is delayed a bit. Therefore, you will have a similar issue like you had with the cross-talk cancellation. The invalid detected strike will be there before the choke is detected.

Maybe you could try to suppress these MIDI notes with your Python script like you do with the cross-talk cancellation. Would be interesting to know if that works.

corrados, 2023-11-07:
I just tested this with my Roland TD-27 and the Roland cymbal pad and I sometimes see exactly the same behavior as in Edrumulus, i.e., a Note On with MIDI not 49 is output on pressing the pad (choking it):
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

3hhh, 2023-11-07:
Hm, I don't like to do things badly just because others do that, too.

I'll probably try to fix it with my cross-talk script.

corrados, 2023-11-07:
Would be interesting to know how your Millenium brain performs in this situation. Do you see similar effects?

3hhh, 2023-11-11:
This could partially be fixed via [my script](https://github.com/3hhh/xtalk). Only partially as the first incorrect MIDI event happens ~10ms before the choke, the second ~5ms and I only want to delay events by at most 5ms, i.e. the first will continue to pass.

3hhh, 2024-01-05:
Btw increasing the sense time helped with this issue. However it caused worse rim detection, so that I dropped the change again.

3hhh, 2025-05-27:
Nowadays I don't use the choke anymore.

I simply use soft MIDI notes (just move the pad a bit) after strong ones to choke.

Essentially this technique makes rim switches somewhat obsolete for choking.

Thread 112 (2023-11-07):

hihat pedal cross-talk

3hhh, 2023-11-07:
If the hihat pedal is used, the outcome is usually not just a pedal MIDI note, but a regular medium velocity hihat note or even hihat rim note as well. This is obviously caused by the hihat cymbals moving during the stomp. The resulting notes should be suppressed. Using the cross talk setting on the hihat helps, but isn't great as the hihat is only meant to be suppressed in that particular case and not when played together with other instruments.

Related: #109

corrados, 2023-11-07:
I tested this with my Roland TD-27 and my VH-12 hi-hat and see exactly the same behavior as in Edrumulus:

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

You get a hi-hat stomp sound (MIDI note 44) but also multiple MIDI notes 46 which are the normal hi-hat hits.

ignotus666, 2023-11-07:
This is a common issue in electronic hi hats that use a hi hat stand and a bottom cymbal - as opposed to a single cymbal, no stand, and a separate foot controller. There are people who prefer to use the latter setup precisely to avoid this.

There isn't really an easy way around it, because if you supress note on messages while the hi hat is travelling up or down, what about an actual intentional hit? I don't want that supressed, and how is the module supposed to tell the difference? At best you could supress notes sent that coincide with the hi hat hitting the top and bottom ranges after moving, but again it's the same problem - what if I intentionally hit it at that moment?

The best I've been able to do is address it at hardware level, using soft foam on the bottom cymbal to prevent them from clapping hard together when stomped on, and some more down where the felt is at the pedal chain to soften the hit when it goes up.

corrados, 2023-11-08:
Thanks for you comment, ignotus666. Since you have a lot of experience with DIY e-drums, it would be highly appreciated if you could build your own Edrumulus hardware and give valuable feedback ;-). BTW, great to have you contributing to my new project. It was a pleasure to work with you on Jamulus :+1:.

ignotus666, 2023-11-08:
The pleasure was (and still is) mine!

I would like to get around to building an Edrumulus module, but before I do I need to know whether my kit would be supported - I can't seem to find a list of compatible pad types. A lot of work has gone into building the kit over the years and I'd be quite reluctant to scrap what I have:

- Piezo/piezo snare and toms. I'd say these are supported.
- Piezo/switch crashes. Not sure about this. Piezo gives a bow note and the edge switch an edge note + choke.
- Piezo/switch/switch hi hat and ride. Same as the crashes + bell switch. Here the edge switch goes through a 10k resistor to distinguish it from the bell switch (both switches go to ring on the jack so all three zones just use a single stereo jack, like Yamaha does with their pads).
- Hall-effect sensor + magnet for the hi hat controller. Needs a ~5v source. The Megadrum module measures voltage changes, not resistance as seems the case here.
- In total my kit uses 21 inputs + hi hat controller. Not sure if that many inputs are supported.

If any of these are not yet supported but there are plans to do so, I'd be happy to collaborate with testing. My pads are DIY but mimic the behaviour of existing commercial pads, so it wouldn't be adding support for just a single user. Except maybe the hall-effect hi hat controller, which I am a huge fan of, however. For literally less than €10 you can make a DIY controller that is virtually indestructable as there are no mechanical/moving parts, and it works really reliably.

3hhh, 2023-11-09:
On 11/7/23 22:59, ignotus wrote:
> The best I've been able to do is address it at hardware level, using soft foam on the bottom cymbal to prevent them from clapping hard together when stomped on, and some more down where the felt is at the pedal chain to soften the hit when it goes up.

Thanks for the hint!
I tried it and indeed it made the issue less prominent, but unfortunately didn't fix it entirely. I guess I'll still have a look into a software solution. I agree that it's suboptimal, but on the other hand false suppressions would only happen, if I wanted to play a 1/16 note on the hihat bow at 80bpm with 40% the velocity of the hihat stomp or so. This is pretty uncommon for my play style so far...

Regarding your question on edrumulus support, you can see the commercially available supported pads in the code (edrumulus_parameters.cpp). They include piezo/piezo snare & toms, piezo/switch crashes and a poti hihat. The list of supported inputs is currently limited to snare | kick | hi-hat | hi-hat-ctrl | crash | tom1 | ride | tom2 | tom3 (each with at most 2 channels), but imho it essentially depends on the Arduino hardware used. You could combine multiple to obtain more ports. 21 is quite an impressive number though...

ignotus666, 2023-11-09:
So, I see that 3-zone cymbals, the hall-effect hi hat controller and the higher number of inputs aren't supported. I'm afraid that's a deal-breaker for me. I imagine it could be relatively easy to support the cymbals and maybe even the hi hat controller, but combining several Arduino boards to get more inputs sounds a bit... too much hassle. I was hoping multiplexers could be used; I think I recall someone testing that with some success but I'm not sure to what extent.

3hhh, 2023-11-09:
On 11/9/23 10:36, ignotus wrote:
> So, I see that 3-zone cymbals, the hall-effect hi hat controller and the higher number of inputs aren't supported. I'm afraid that's a deal-breaker for me. I imagine it could be relatively easy to support the cymbals and maybe even the hi hat controller, but combining several Arduino boards to get more inputs sounds a bit... too much hassle. I was hoping multiplexers could be used; I think I recall someone testing that with some success but I'm not sure to what extent.

Hm the Teensy registers itself as Midi device via USB to whatever host you're using. So multiplexing those together shouldn't be hard - probably you can just use qjackctl and in the worst case it's a ~100 line script with python-rtmidi. But yes, you'd have to run edrumulus GUI two times at the moment.
The Teensy 4.1 has 18 analog input pins, i.e. it would support 18 mono inputs (e.g. one piezo trigger per pin) in theory. Edrumulus currently uses 1-2 per pad. Whether the Teensy CPU is powerful enough to keep up with an 18 pin load idk - possibly @corrados knows more.

ignotus666, 2023-11-09:
The problem I see with using more than one Teensy (or ESP or whatever) is crosstalk. Unless the boards are "aware" of each other, it would be an issue. I know [Edrumin](https://www.audiofront.net/eDRUMin.php) modules can be daisy-chained and crosstalk between all pads is taken care of, but I have no idea how feasible doing that is.

corrados, 2023-11-09:
> A lot of work has gone into building the kit over the years and I'd be quite reluctant to scrap what I have

Sure, that was my expectation. You have something which works and why to change it. I have to admit, my intention for you was to do something [like this](https://github.com/corrados/edrumulus/discussions/83) which is a cheap ESP32 dev board, a bread board and some components and build a simple single input prototype. This way you do not have to spend a lot of money and can test the edrumulus performance for dynamics and positional sensing. Then you can already give me very valuable feedback :-).
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
corrados, 2023-11-10:
> This sounds good to me - I've got one of [these](https://www.lilygo.cc/products/lilygo%C2%AE-ttgo-t-display-1-14-inch-lcd-esp32-control-board) lying around that someone gave me. Would this board work?

I also have one of these. I just tried it out: Yes, it works :-).

> I use 21 channels - 10 stereo inputs + 1 mono.

Ok, then it's not so bad. Maybe a Teensy 4.0/4.1 is already capable of this number of channels.

3hhh, 2023-11-11:
To come back to the original issue:
I could fix this via https://github.com/3hhh/xtalk.

thijstriemstra, 2023-11-14:
>  Except maybe the hall-effect hi hat controller, which I am a huge fan of, however. For literally less than €10 you can make a DIY controller that is virtually indestructable as there are no mechanical/moving parts, and it works really reliably.

That sounds great @ignotus666, any resources on how to build such a diy version you can share?

ignotus666, 2023-11-14:
@thijstriemstra

It's very simple. I use a A1302 hall effect sensor, but I think they've been out of production for a few years. You can find what I presume to be knock-offs on Aliexpress that work, but I've found them to be less sensitive than the original. However, [this](https://www.bitsboxuk.com/index.php?main_page=product_info&cPath=302_305&products_id=2084) one will work too.

These sensors have three pins: voltage in, signal out and ground - I'm not sure how this would connect to the edrumulus board, but I suppose you'd take a 3.3v source from the board and connect the sensor's signal out pin to the hi hat input. And gnd of course. Then you need a neodymium magnet. I use one that's 10 x 20 x 30 mm.

Place the sensor fixed to the frame under the hi hat pedal, and the magnet stuck to the underside of the pedal, in such a way that when closed, sensor and magnet are ~2-5 mm away from each other (not touching). The open/closed range depends on the power of the magnet and your preference - I use a range of about 25-30 mm. The sensor is sensitive to polarity, so before mounting everything, make sure you know which side of the magnet (and the sensor - narrower face up) is the correct one. I 3D printed parts for the sensor (so it's at the right height) and the magnet. The magnet holds itself in place as the part it attaches to under the pedal is metal. I'll post an image - it's a bit dark and dusty, but hopefully you get the idea.

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

To give you an idea, I've been using this sensor for almost 15 years. I used to use magnets recycled from a hard drive but "upgraded" that a few years ago. Controllers that use mechanical parts (pots, FSRs with rubber actuators, etc.) will eventually wear, degrade and break. Bar an accident, this one will keep going indefinitely ;)

corrados, 2023-11-14:
That's brilliant. I wonder if the voltage curve you get is direct proportional to the position of the pedal or is it more like a non-linear relationship? Anyway, any non-linear curve could be compensated for in software.

ignotus666, 2023-11-14:
It isn't linear but it's close. As you say, it's easily compensated for in software. I use Superior Drummer and assign the different open levels there.

thijstriemstra, 2023-11-14:
that's great @ignotus666. are the 3d print files on thingiverse or printables.com by any chance? 😄

ignotus666, 2023-11-14:
I had a go at publishing it on Thingiverse but I can't get it to work... so I'll attach the .stl files here. You might have to edit them to fit your hi hat stand, though it's such a simple design you could just use them as a reference to create your own. The hole at the top isn't really needed for the hall sensor - the magnetic field won't mind a plastic barrier, doh! :-)

[hall-effect_housing.zip](https://github.com/corrados/edrumulus/files/13357189/hall-effect_housing.zip)

thijstriemstra, 2023-11-15:
thanks! I'll give it a try and get back to you.

3hhh, 2024-01-05:
Btw I noticed that significantly increasing the scan time for the cymbals helped with this issue. However it also caused worse rim shot detection, so that I dropped the change again.

giff25, 2025-05-27:
This makes me think of defining different voltage Delta thresholds for the hall effect sensor. If its above a certain threshold then the likely intention is to stomp and any "notes" should be suppressed until the voltage becomes roughly constant or there is distinct indication the hi-hats are closed . Would this be computationally feasible?

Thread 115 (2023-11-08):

Unable to run edrumulus_gui.py on Windows

thijstriemstra, 2023-11-08:
OS: Win10
Python: 3.10
Shell: Git bash
Controller: ESP32

After following the manual and installing Python packages I tried running `edrumulus_gui.py` using:

```console
tools/edrumulus_gui.py rtmidi
```

which results in:

```
/usr/bin/env: ‘python3’: No such file or directory
```

I would suggest using this in the docs instead:

```console
python tools/edrumulus_gui.py rtmidi
```

but it results in:

```
Redirection is not supported.
```

Any idea?

thijstriemstra, 2023-11-08:
If I use Powershell instead:

```
 python .\tools\edrumulus_gui.py rtmidi
```

I get this error instead:

```
Traceback (most recent call last):
  File "C:\Users\foo\projects\edrumulus\edrumulus\tools\edrumulus_gui.py", line 593, in <module>
    midiin, port_name_in   = open_midiinput([s for s in rtmidi.MidiIn().get_ports() if in_name in s][0], client_name="EdrumulusGUI")
IndexError: list index out of range

During handling of the above exception, another exception occurred:

Traceback (most recent call last):
  File "C:\Users\foo\projects\edrumulus\edrumulus\tools\edrumulus_gui.py", line 597, in <module>
    raise Exception("No Teensy Edrumulus device found")
Exception: No Teensy Edrumulus device found
```

But I'm using an ESP32 though..

corrados, 2023-11-08:
Did you run loopMIDI and HairlessMIDI before you started edrumulus_gui? See https://github.com/corrados/edrumulus/discussions/16#discussioncomment-5630286

corrados, 2023-11-08:
This help text should also be up to date: https://github.com/corrados/edrumulus/blob/main/doc/manual.md#setup-for-esp32-under-windows

corrados, 2023-11-08:
Also checkout the comment here: https://github.com/corrados/edrumulus/blob/main/doc/manual.md#edrumulus-user-manual

**"[Python](https://www.python.org/) to control Edrumulus trigger parameters in real-time.
    Install the Python PIP packages python-rtmidi and windows-curses."**

Did you install these Python packages?

thijstriemstra, 2023-11-08:
> Install the Python PIP packages python-rtmidi and windows-curses."

> Did you install these Python packages?

Yes, see my previous comment:

> Python 3.10.4 (tags/v3.10.4:9d38120, Mar 23 2022, 23:13:41) [MSC v.1929 64 bit (AMD64)] on win32
Type "help", "copyright", "credits" or "license" for more information.
>>> import rtmidi
>>> rtmidi.API_WINDOWS_MM in rtmidi.get_compiled_api()
True
>>> midiout = rtmidi.MidiOut()
>>> midiout.get_ports()
['Microsoft GS Wavetable Synth 0']

> Did you run loopMIDI and HairlessMIDI before you started edrumulus_gui? See https://github.com/corrados/edrumulus/discussions/16#discussioncomment-5630286

No, but when I do start them, and then run `python tools/edrumulus_gui.py rtmidi`, I'm getting a new exception:

```
Traceback (most recent call last):
  File "C:\Users\foo\projects\edrumulus\edrumulus\tools\edrumulus_gui.py", line 37, in <module>
    from rtmidi.midiutil import open_midiinput
ModuleNotFoundError: No module named 'rtmidi.midiutil'
```

thijstriemstra, 2023-11-08:
With pr #117 I am able to run `python tools\edrumulus_gui.py rtmidi` but the prompt/window is just empty:

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

Hopefully this is because I haven't my edrumulus esp32 device connected (because I haven't flashed new firmware yet)? Have you/can you try to start the edrumulus gui without a device connected @corrados and do you also get a blank screen in that case?

corrados, 2023-11-08:
> >  Did you install these Python packages?

> Yes, see my previous comment:

You have to be very carefully with the Python packages. Unfortunately, there are multiple rtmidi packages available but only the python-rtmidi works with Edrumulus. Please make sure you actually installed exactly this package and no other.

> No, but when I do start them, and then run python tools\edrumulus_gui.py rtmidi, I'm getting a new exception:

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

That indicates that the command line argument is not correctly given to the script. If rtmidi command line argument is given, no jack audio is used at all.

>  but the prompt/window is just empty [...] Hopefully this is because I haven't my edrumulus esp32 device connected

Exactly. Edrumulus must be connected for the script to work. Otherwise I also get an empty screen.

thijstriemstra, 2023-11-08:
> Exactly. Edrumulus must be connected for the script to work. Otherwise I also get an empty screen.

Great, then I'm confident to upgrade firmware and have ability to tune the parameters. I'd hate to put my edrumulus out of commission and go through trouble of reverting the firmware. Could you merge #117 though, without it I'm getting path issues.

corrados, 2023-11-08:
Before you update, please tag your current Git commit to be able to easily go back to the old version (just in case ;-) ).

corrados, 2023-11-08:
> Could you merge https://github.com/corrados/edrumulus/pull/117 though, without it I'm getting path issues.

done

thijstriemstra, 2023-11-08:
thanks. I'll upgrade firmware tomorrow and if everything's fine, close this ticket.

thijstriemstra, 2023-11-10:
>  if everything's fine, close this ticket.

So yesterday we were all ready to test out the new code, flashed new firmware, started edrumulus_gui.py and unfortunately it resulted in same black command prompt.. no errors, nothing. How can I debug this issue?

corrados, 2023-11-10:
Have you checked that you have loopMIDI correctly configured with the names "EdrumulusIn" and "EdrumulusOut"? You can try to flip the assignments in HairlessMIDI. Maybe this is the issue.

corrados, 2023-11-10:
I have just tried it out with the latest Git main branch and it works fine for me:
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

corrados, 2023-11-10:
I am pretty sure that it does not make a difference but you could try to enter the tools directory and start the script from there (you are in the edrumulus root directory: 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). At least this is what I usually do.

thijstriemstra, 2023-11-11:
> Have you checked that you have loopMIDI correctly configured with the names "EdrumulusIn" and "EdrumulusOut"?

Good point, I used a different name, let me try.

thijstriemstra, 2023-11-11:
>

Awesome, that worked:

> Good point, I used a different name, let me try.

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

I opened #121 to clarify things a little bit more, thanks for the screenshot.

thijstriemstra, 2023-11-11:
> I am pretty sure that it does not make a difference but you could try to enter the tools directory and start the script from there

I believe this potential issue was fixed with #117 but before that PR it would surely be an issue.

Closed 2023-11-11.

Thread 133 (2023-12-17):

Bad cymbal rim dynamics

3hhh, 2023-12-17:
I noticed that the cymbal rim dynamics are generally bad - there's just one or two velocity levels even though I have rim boost set to zero.

This may be related to my experiments in https://github.com/corrados/edrumulus/discussions/126, but I doubt that as the cymbal piezo value should be taken for the MIDI velocity and not the rim switch value.

corrados, 2023-12-17:
I cannot reproduce this issue. With my Roland CY pad, I get good dynamics when I hit the rim.

3hhh, 2023-12-17:
Interesting. Then I'll have to investigate this further...

3hhh, 2023-12-19:
So I went to some lengths to obtain proper samples from my Teensy with [this code](https://gist.github.com/3hhh/94f7199d1ebea5dd0502415375400813).
(Btw it would be useful to have some standardized way of obtaining samples in the repo.)

The results:
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

Unfortunately I cannot see any fault in my signals as their peak voltage clearly indicates the velocity (IIRC my hard ride rim hit wasn't so hard). Also, the rim switch capacitor circuit correctly indicates that it was used - admittedly sometimes a bit earlier or later than the hit piezo.
So in total I still think that the issue must be with the edrumulus code...

Also, with regards to https://github.com/corrados/edrumulus/discussions/126 the plots look neither good for the sample counting of the rim switch open time nor for the second threshold method to discern the bell from the edge. :-(
Maybe the velocity of the hit also has to be taken into account somehow, idk. Or use the hit piezo ripple length, but I don't understand the electronic background for that atm and it makes the different rim input impedances pointless.
Maybe I'll go back to the original circuit...

[raw data download](https://github.com/corrados/edrumulus/files/13718414/all.tar.gz)

corrados, 2023-12-20:
Maybe it is an issue with the internal pad trigger parameters. Maybe Edrumulus detects the main peak at the beginning of the burst:
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
BTW, you should use logarithmic voltage-axis to better visualize the dynamics of the signal.

3hhh, 2023-12-20:
On 12/20/23 07:21, Volker Fischer wrote:
> Maybe it is an issue with the internal pad trigger parameters. Maybe Edrumulus detects the main peak at the beginning of the burst

Ok, I increased the scan time to 8ms and since then I obtain _some_ dynamics in the range of 70 to 127 on the MPS750x crash and ride. I still cannot obtain lower velocities though. In fact, if I move from the center of the pad to the rim at constant low velocity, I can get velocity 10-20 hits until I reach the rim - then it suddenly becomes a rim hit of velocity ~70. Any idea why?

The high scan time is only needed for rim hits - I guess I _sometimes_ (definitely not in my test above) hit the pad multiple times during a rim hit (once at the rim and possibly one more time at the regular piezo location - at least that way I appear to get better dynamics) and I guess those signals may come in at different points in time.

I haven't tested increasing the scan time with the Lemon hihat yet (it has the same issue).

3hhh, 2024-01-05:
I went back to the original voltage divider circuit with my parameters and I now have good cymbal rim dynamics for the MPS750x pads again. So apparently this issue was a byproduct of [my capacitor circuit for the rim switch](https://github.com/corrados/edrumulus/discussions/126).

The Lemon hihat is still not perfect imo, but I'll look into that separately. Maybe the parameters could be chosen a bit differently.

Closed 2024-01-05.

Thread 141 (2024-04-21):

Idea: Test edrumulus on x64 hardware

3hhh, 2024-04-21:
Testing would be easier, if edrumulus could run on x64 hardware with emulated I/O.

It would also make the current Octave modeling unnecessary as an input signal could be directly run against the edrumulus code and the MIDI output be observed.

Ultimately it would enable automated testing via the CI pipeline.

One of the projects claiming to accomplish this: https://github.com/Arduino-CI/arduino_ci

giff25, 2025-05-28:
Why use a x64 system?

3hhh, 2025-05-29:
On 5/28/25 21:48, Victor Butkov wrote:
> giff25 left a comment (corrados/edrumulus#141)
>
> Why use a x64 system?

Some standard PC hardware was the point.

giff25, 2025-05-29:
Ok, Im still having trouble understanding the purpose of emulated I/O. Is it so we can just run the program on a PC rather than a dedicated board?

corrados, 2025-05-30:
I found out that each new function which was introduced caused more CPU cycles. Since we want to have a maximum number of inputs, it is not desired to have new functions.

For what reason do we need tests? Did the software crash in the past? At least it was never crashing for me.

Having a reference model in Octave/Matlab is a must for me.

giff25, 2025-05-30:
We can declare the functions as inline, it'll cause zero changes in performance while being able to separate the code into more neat units

giff25, 2025-05-30:
> For what reason do we need tests? Did the software crash in the past? At least it was never crashing for me.

Testing in this way just makes it easier to make changes in the code later down the road. Also I was thinking we might be able to automate the configuration process for new hardware after we figure out unit tests

Also also, we can potentially use some python libraries for the analysis instead of MATLAB/Octave so that its all part of the code; however i am not sure how this will effect the program size and whether we have enough memory to store it on the chip

corrados, 2025-05-30:
> use some python libraries for the analysis instead of MATLAB/Octave

This is how the Edrumulus algorithm design works: https://github.com/corrados/edrumulus/blob/main/doc/algorithm.md#algorithm-development

> declare the functions as inline, it'll cause zero changes in performance

Depends on the compiler. I am not sure if the ESP32 compiler does what you expect it to do.

giff25, 2025-05-30:
Also related to this issue, I see you were starting to mess around with platformIO. Have you considered ESP-IDF as an alternative?

corrados, 2025-06-01:
> How are you porting the code?

I port the code "by hand".

> I know GCC is very good at optimizing C/C++.

GCC is of no use for ESP32. We need the Espressif compiler to do the job.

> if [this](https://github.com/corrados/edrumulus/blob/main/doc/manual.md#setup-for-esp32) is your build process, then I think it would be worth changing it.

This is just my personal preference. I even do not use platformIO, the configuration is just for the GitHub runner. You can use any IDE you like.

3hhh, 2025-06-01:
> Do we currently have a standard way to view the midi output?
>
> Also, How would that get rid of the need for octave? wouldn't we need to see the processed digital signal rather than the midi output?

The idea was to not have to view anything by hand, if everything works as expected.

Essentially all input signals are [here](https://github.com/corrados/edrumulus/tree/main/algorithm/signals) and could be replayed as virtual ADC input against an emulated edrumulus implementation. The output would be MIDI, which can be easily automatically verified via unit tests (must be 3 hihat pedal stomps of increasing velocity or whatever).

Currently testing against the edrumulus C code only works if you have the respective drum hardware and the respective board and must be conducted manually.

The octave model enables some semi-manual testing of the input signals against the octave model, which in theory should be identical to the C code, but of course it won't be 100% accurate.

Anyway this was just an idea and I gues it would be quite a massive undertaking to implement it.
It's unlikely that I'll do it at least. The same probably applies to @corrados .

giff25, 2025-06-02:
> GCC is of no use for ESP32. We need the Espressif compiler to do the job.

is the espressif compiler what you currently use?

giff25, 2025-06-04:
So from what I can tell @corrados chose one of the only/better options for simulating adc with octave, while espressif has their own simulator it doesnt seem to support device drivers so I think emulating I/O is not going to be possible at the moment; however, I do think doing unit testing with CMock would still be beneficial. This way people can develop/test their functions without needing _all_ _of the hardware present._

If we want to move forward with it, I just need to know how to interact with the repo (I.e. develop the unit tests on a separate branch or fork the repo, etc.). let me know how you would like me to proceed and I can start developing them.

corrados, 2025-06-06:
You need to ask 3hhh. He created the "Idea". I actually do not see a need to do unit tests in the current state of the project. If we would have algorithm changes all the time and need to verify functionality, that could make sense.

If you are searching for things to improve in Edrumulus, you should pick one from the TODO list. E.g. the [user documentation](https://github.com/corrados/edrumulus/blob/main/doc/manual.md) could be improved, see, e.g., https://github.com/corrados/edrumulus/discussions/164

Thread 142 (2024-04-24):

Direct piezo hits sometimes cause a MIDI mute

3hhh, 2024-04-24:
As discussed in https://github.com/corrados/edrumulus/discussions/139#discussioncomment-9177871 direct very hard piezo hits on my MPS750x sometimes cause no edrumulus MIDI output.

In fact, there appears to be a very low volume (velocity usually around 1) MIDI note instead. This note and others were correctly filtered out as cross-talk by my `xtalk` script, which is why I had incorrectly not seen and mentioned them before.

After some investigation I came to the conclusion that the missing MIDI output is likely caused by the edrumulus clipping compensation algorithm:

By commenting in [these lines](https://github.com/corrados/edrumulus/blob/498634ce4e4da4f97486fd742cf2bd6d79b343ff/edrumulus.cpp#L1007-L1021) I obtained the following output whenever I ran into the bug:
```
1.
0.00 0.00 0.00 0.00 0.00 0.00 0.00 0.00 0.00 0.00 0.00 0.00 0.00 0.00 0.00 0.00 0.00 0.00 0.00 0.00 0.00 0.00 0.00 0.00 0.00 0.00 0.00 0.00 0.00 0.00 0.00 0.00 0.00 0.00 1.00 1.00 1.00 1.00 1.00 1.00 1.00 1.00 1.00 1.00 1.00 1.00 1.00 0.00 0.00 0.00 0.00 0.00 2.00 2.00 2.00 2.00 2.00 2.00 2.00 2.00 2.00 2.00 2.00 2.00 2.00 2.00 2.00 2.00 0.00 0.00 0.00 0.00 0.00 0.00 0.00 0.00

34 76 34 76 34

1303.47 1139.37 13 1221.42 -463.04 0.00

2.
0.00 0.00 0.00 0.00 0.00 0.00 0.00 0.00 0.00 0.00 0.00 0.00 0.00 0.00 0.00 0.00 0.00 0.00 0.00 0.00 0.00 0.00 0.00 0.00 0.00 0.00 0.00 0.00 0.00 0.00 0.00 0.00 0.00 0.00 1.00 1.00 1.00 1.00 1.00 1.00 1.00 1.00 1.00 1.00 1.00 1.00 1.00 1.00 0.00 0.00 0.00 2.00 0.00 2.00 2.00 2.00 2.00 2.00 2.00 2.00 2.00 2.00 2.00 2.00 2.00 2.00 2.00 2.00 0.00 0.00 0.00 0.00 0.00 0.00 0.00 0.00

34 76 34 76 34

191.25 909.14 14 550.19 -1134.04 0.00

3.
0.00 0.00 0.00 0.00 0.00 0.00 0.00 0.00 0.00 0.00 0.00 0.00 0.00 0.00 0.00 0.00 0.00 0.00 0.00 0.00 0.00 0.00 0.00 0.00 0.00 0.00 0.00 0.00 0.00 0.00 0.00 0.00 0.00 0.00 1.00 1.00 1.00 1.00 1.00 1.00 1.00 1.00 1.00 1.00 1.00 1.00 1.00 1.00 0.00 0.00 0.00 0.00 0.00 2.00 2.00 2.00 2.00 2.00 2.00 2.00 2.00 2.00 2.00 2.00 2.00 2.00 2.00 2.00 0.00 0.00 0.00 0.00 0.00 0.00 0.00 0.00

34 76 34 76 34

155.27 341.17 14 248.22 -1436.04 0.00
```

Please note that the peak (last value) is always considered to be zero by edrumulus whenever I ran into the bug.

Three samples where it works correctly:
```
1.
0.00 0.00 0.00 0.00 0.00 0.00 0.00 0.00 0.00 0.00 0.00 0.00 0.00 0.00 0.00 0.00 0.00 0.00 0.00 0.00 0.00 0.00 0.00 0.00 0.00 0.00 0.00 0.00 0.00 0.00 0.00 0.00 0.00 0.00 0.00 0.00 0.00 0.00 1.00 1.00 1.00 1.00 1.00 0.00 0.00 0.00 1.00 1.00 1.00 1.00 0.00 0.00 0.00 2.00 0.00 0.00 0.00 0.00 0.00 0.00 0.00 0.00 0.00 0.00 0.00 0.00 0.00 0.00 0.00 0.00 0.00 0.00 0.00 0.00 0.00 0.00

38 76 38 76 38

1509.29 1125.25 5 1317.27 -70.61 0.00 1.45 2434.53

2.
0.00 0.00 0.00 0.00 0.00 0.00 0.00 0.00 0.00 0.00 0.00 0.00 0.00 0.00 0.00 0.00 0.00 0.00 0.00 0.00 0.00 0.00 0.00 0.00 0.00 0.00 0.00 0.00 0.00 0.00 0.00 0.00 0.00 0.00 0.00 0.00 0.00 1.00 1.00 1.00 1.00 1.00 0.00 0.00 1.00 1.00 1.00 0.00 0.00 0.00 0.00 0.00 0.00 0.00 0.00 0.00 0.00 0.00 0.00 0.00 0.00 0.00 0.00 0.00 0.00 0.00 0.00 0.00 0.00 0.00 0.00 0.00 0.00 0.00 0.00 0.00

37 76 37 76 37

925.41 1537.37 5 1231.39 -156.59 0.00 1.45 2434.70

3.
0.00 0.00 0.00 0.00 0.00 0.00 0.00 0.00 0.00 0.00 0.00 0.00 0.00 0.00 0.00 0.00 0.00 0.00 0.00 0.00 0.00 0.00 0.00 0.00 0.00 0.00 0.00 0.00 0.00 0.00 0.00 0.00 0.00 0.00 0.00 0.00 0.00 1.00 1.00 1.00 1.00 1.00 0.00 0.00 0.00 0.00 1.00 1.00 1.00 1.00 0.00 0.00 2.00 0.00 0.00 0.00 0.00 0.00 0.00 0.00 2.00 0.00 0.00 0.00 0.00 0.00 0.00 0.00 0.00 0.00 0.00 0.00 0.00 0.00 0.00 0.00

37 76 37 76 37

257.99 1290.95 5 774.47 -613.99 0.00 1.45 2435.54
```

corrados, 2024-04-24:
Great that you found the cause of the issue and thank you for the detailed debug data.

> In fact, there appears to be a very low volume (velocity usually around 1) MIDI note instead. This note and others were correctly filtered out as cross-talk by my xtalk script, which is why I had incorrectly not seen and mentioned them before.

Yea, that makes totally sense now.

corrados, 2024-04-24:
That is very interesting. I just tried it out to dump the debug data on my PD-80R where the clipping compensation works just fine, and I got the following numbers:

```
19:47:37.999 -> 0.00 0.00 0.00 0.00 0.00 0.00 0.00 0.00 0.00 0.00 0.00 0.00 0.00 0.00 0.00 0.00 0.00 0.00 0.00 0.00 0.00 0.00 0.00 0.00 0.00 0.00 0.00 1.00 1.00 1.00
19:47:38.032 -> 27 30 27 30 27
19:47:38.032 -> 1378.04 0.00 3 1378.04 -455.95 0.00 nan nan
```
The nan are obviously wrong and a bug. What puzzles me is that I see nan and in your case there are just 6 values given where I expect 8 values. I assume that you also have nan values but your serial plotter may just omit the nan values.

corrados, 2024-04-24:
I guess you do not get the nan because I am using ESP32 and your are a Teensy. These two devices most probably treat nan values differently.

Anyway, I think I found the issue but have not a solution how to solve it. After deriving the clipping compensation in Octave, I later introduced a limit in the C++ implementation which was not there in the Octave reference code:

https://github.com/corrados/edrumulus/blob/89ccdd25d220467a12051861267e0b5f686c632e/edrumulus.cpp#L588

The "min ( 5," seems to cause the issue. If you like, you could remove that limit and try again if you still get the muted MIDI signals. Anyway, the limit was introduced by a reason and now I have to find a solution which still applies a limit but does not produce the nan values...

corrados, 2024-04-24:
I have just applied a fix to Git main branch. Can you please test if this fixes your issue?

3hhh, 2024-04-25:
Yes, that fixes it. Many thanks!
Maybe that'll make me look into pos sensing for the MPS750x again...

Btw you might be interested [in my latest project](https://github.com/3hhh/klickly).

Closed 2024-04-25.

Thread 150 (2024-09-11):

Hihat bow play sometimes not working

3hhh, 2024-09-11:
On my Lemon hihat I noticed that bow play sometimes does not produce any edrumulus output for mutiple seconds.

I _believe_ it happens right after edrumulus startup or after I do a very strong stomp. The latter may indicate an hardware issue as the Lemon hihat has a mute switch, which may be turned on by the stomp.

Usually it can be fixed by a few rim shots on the hihat - probably making the mute switch get loose again.

@corrados : Do you happen to have similar issues with your Roland hihat? Any ideas as to where to look?

3hhh, 2024-09-12:
Ok, I did some measurements and by now I think that the bow piezo is probably somewhat broken.

In any case it seems to be unlikely to be related to edrumulus, so that I'll close this for now.

Closed 2024-09-12.

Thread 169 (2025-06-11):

3hhh rev PCB teensy / gui

daltronbeats, 2025-06-11:
is there anything special i need to do to in the code to get the gui working with teensy 4.1? I can use it no problems with esp32 but im stuck at "trying to connect to edrumulus device" with the teensy (already enabled Serial + MIDI in arduino)

I have no led errors and MIDI output appears as normal in midi monitor, i just need to set the sensitivity.

Thanks!

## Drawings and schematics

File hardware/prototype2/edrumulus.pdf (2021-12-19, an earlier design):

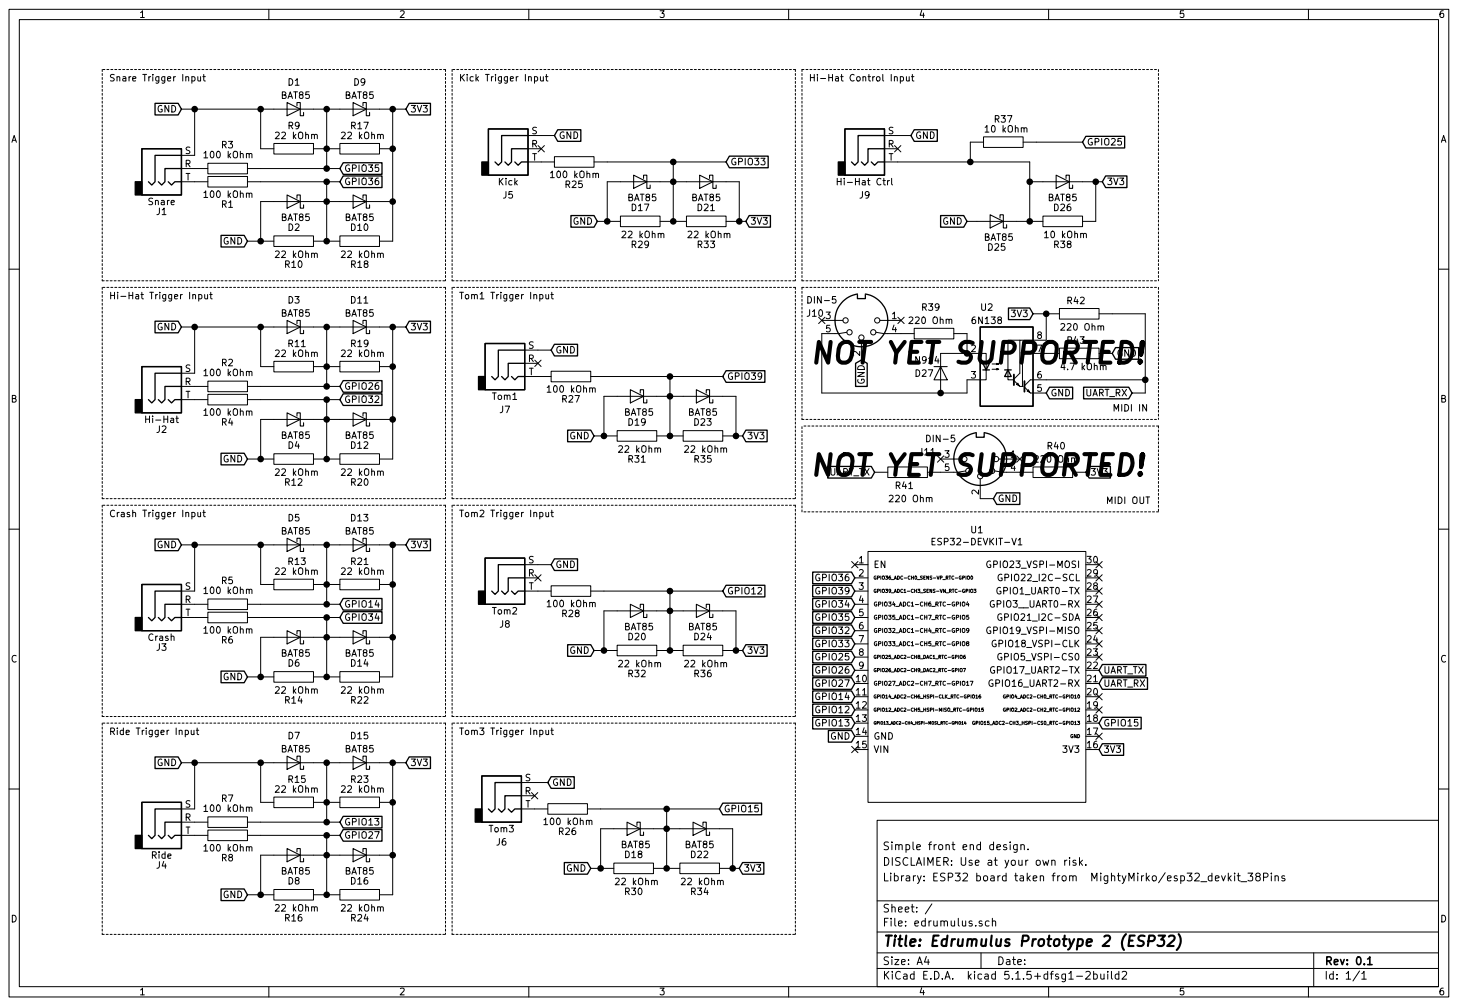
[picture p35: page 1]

Hi-Hat Trigger Input

Simple front end design.
DISCLAIMER: Use at your own risk.
Id: 1/1 Title: Edrumulus Prototype 2 (ESP32) File: edrumulus.sch Sheet: / Library: ESP32 board taken from MightyMirko/esp32_devkit_38Pins

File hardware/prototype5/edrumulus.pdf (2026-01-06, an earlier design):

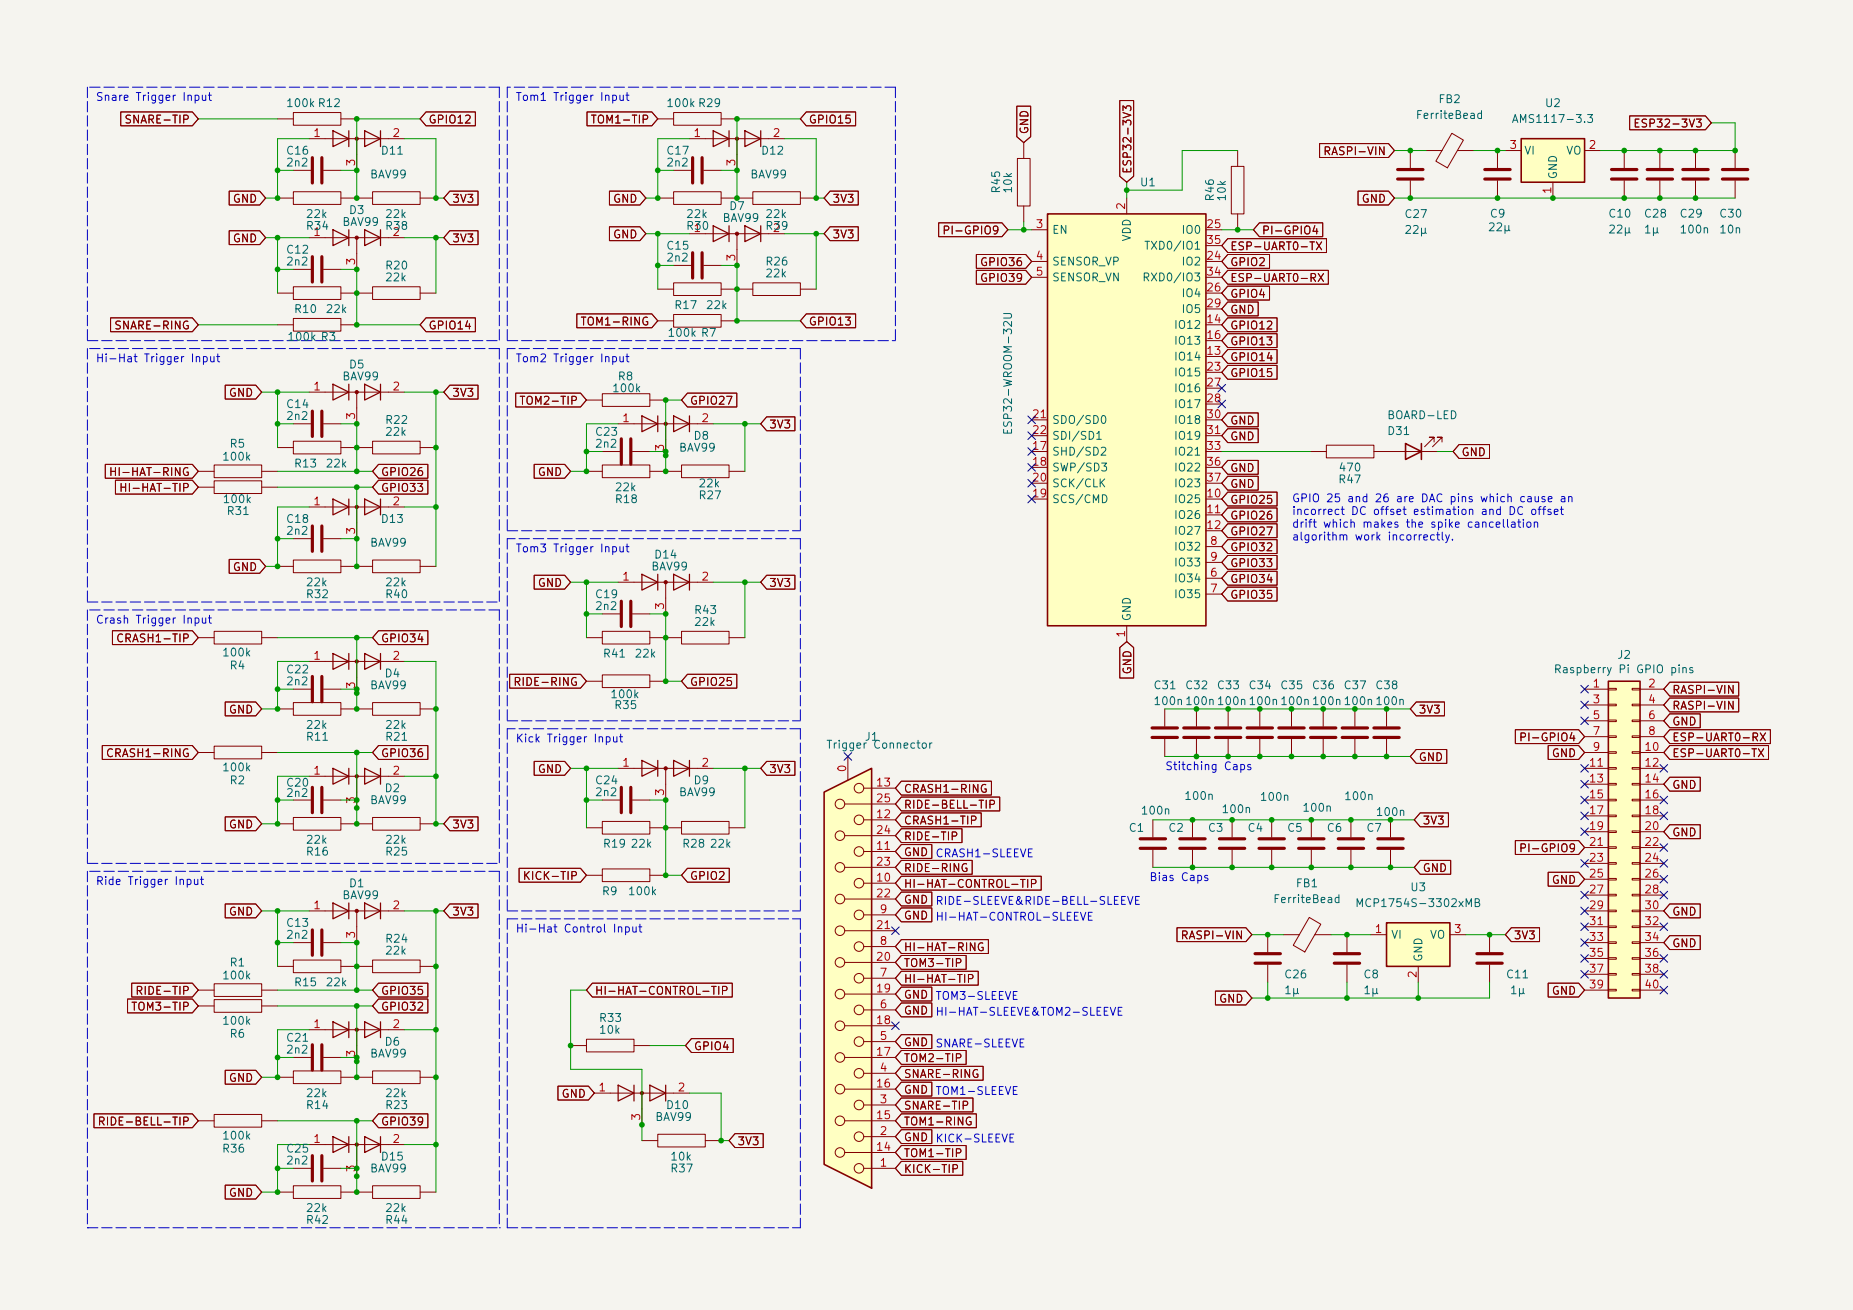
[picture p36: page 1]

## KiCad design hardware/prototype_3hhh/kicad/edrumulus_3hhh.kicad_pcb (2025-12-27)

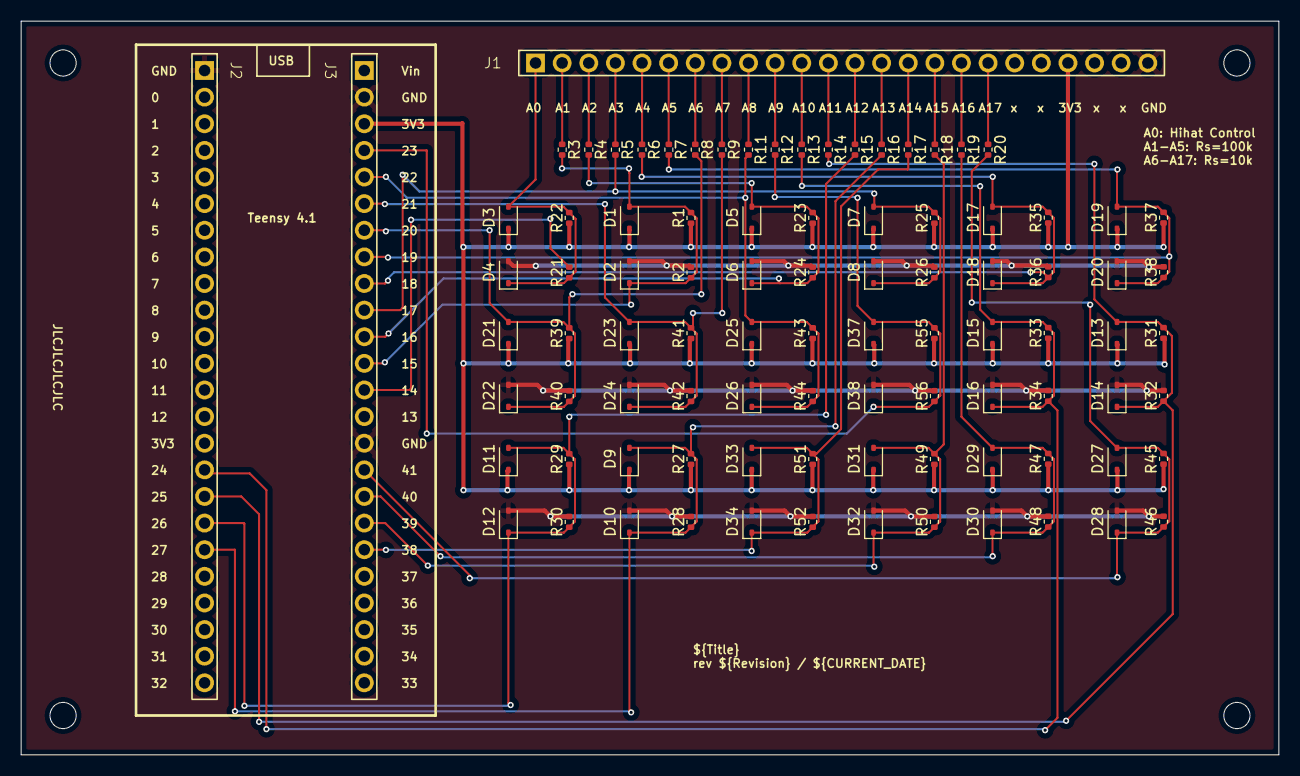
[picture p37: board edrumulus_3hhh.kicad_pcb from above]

Board: 2 copper layers, 120.0 x 70.0 mm, 92 parts (0 on the bottom side), 38 nets.

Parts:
D1, D2, D3, D4, D5, D6, D7, D8, D9, D10, D11, D12, D13, D14, D15, D16, D17, D18, D19, D20, D21, D22, D23, D24, D25, D26, D27, D28, D29, D30, D31, D32, D33, D34, D37, D38: D; D_SOD-323
J1, J2, J3: Conn_01x24_Socket; 1x24P Female Header Hong Cheng HC-PM254-8.5H-1x24PZ
R1, R2, R8, R9, R11, R12, R13, R14, R15, R16, R17, R18, R19, R20, R21, R22, R23, R24, R25, R26, R27, R28, R29, R30, R31, R32, R33, R34, R35, R36, R37, R38, R39, R40, R41, R42, R43, R44, R45, R46, R47, R48, R49, R50, R51, R52, R55, R56: 10k; R_0402_1005Metric
R3, R4, R5, R6, R7: 100k; R_0402_1005Metric

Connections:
+3V3: D1.1 (K), D3.1 (K), D5.1 (K), D7.1 (K), D9.1 (K), D11.1 (K), D13.1 (K), D15.1 (K), D17.1 (K), D19.1 (K), D21.1 (K), D23.1 (K), D25.1 (K), D27.1 (K), D29.1 (K), D31.1 (K), D33.1 (K), D37.1 (K), J1.21, J3.3, R1.1, R22.1, R23.1, R25.1, R27.1, R29.1, R31.1, R33.1, R35.1, R37.1, R39.1, R41.1, R43.1, R45.1, R47.1, R49.1, R51.1, R55.1
GND: D2.2 (A), D4.2 (A), D6.2 (A), D8.2 (A), D10.2 (A), D12.2 (A), D14.2 (A), D16.2 (A), D18.2 (A), D20.2 (A), D22.2 (A), D24.2 (A), D26.2 (A), D28.2 (A), D30.2 (A), D32.2 (A), D34.2 (A), D38.2 (A), J1.24, J2.1, J3.2, J3.15, R2.2, R24.2, R26.2, R28.2, R30.2, R32.2, R34.2, R36.2, R38.2, R40.2, R42.2, R44.2, R46.2, R48.2, R50.2, R52.2, R56.2
unnamed: D1.2 (A), D2.1 (K), J3.12, R1.2, R2.1, R3.2
unnamed: D3.2 (A), D4.1 (K), J1.1, R21.1, R22.2
unnamed: D5.2 (A), D6.1 (K), J3.11, R4.2, R23.2, R24.1
unnamed: D7.2 (A), D8.1 (K), J3.10, R5.2, R25.2, R26.1
unnamed: D9.2 (A), D10.1 (K), J2.19, R16.2, R27.2, R28.1
unnamed: D11.2 (A), D12.1 (K), J2.18, R15.2, R29.2, R30.1
unnamed: D13.2 (A), D14.1 (K), J2.17, R14.2, R31.2, R32.1
unnamed: D15.2 (A), D16.1 (K), J2.16, R13.2, R33.2, R34.1
unnamed: D17.2 (A), D18.1 (K), J3.9, R6.2, R35.2, R36.1
unnamed: D19.2 (A), D20.1 (K), J3.8, R7.2, R37.2, R38.1
unnamed: D21.2 (A), D22.1 (K), J3.7, R8.2, R39.2, R40.1
unnamed: D23.2 (A), D24.1 (K), J3.6, R9.2, R41.2, R42.1
unnamed: D25.2 (A), D26.1 (K), J3.5, R11.2, R43.2, R44.1
unnamed: D27.2 (A), D28.1 (K), J3.16, R20.2, R45.2, R46.1
unnamed: D29.2 (A), D30.1 (K), J3.17, R19.2, R47.2, R48.1
unnamed: D31.2 (A), D32.1 (K), J3.18, R18.2, R49.2, R50.1
unnamed: D33.2 (A), D34.1 (K), J3.19, R17.2, R51.2, R52.1
unnamed: D37.2 (A), D38.1 (K), J3.4, R12.2, R55.2, R56.1
unnamed: J1.2, R3.1
unnamed: J1.3, R4.1
unnamed: J1.4, R5.1
unnamed: J1.5, R6.1
unnamed: J1.6, R7.1
unnamed: J1.7, R8.1
unnamed: J1.8, R9.1
unnamed: J1.9, R11.1
unnamed: J1.10, R12.1
unnamed: J1.11, R13.1
unnamed: J1.12, R14.1
unnamed: J1.13, R15.1
unnamed: J1.14, R16.1
unnamed: J1.15, R17.1
unnamed: J1.16, R18.1
unnamed: J1.17, R19.1
unnamed: J1.18, R20.1
unnamed: J3.13, R21.2

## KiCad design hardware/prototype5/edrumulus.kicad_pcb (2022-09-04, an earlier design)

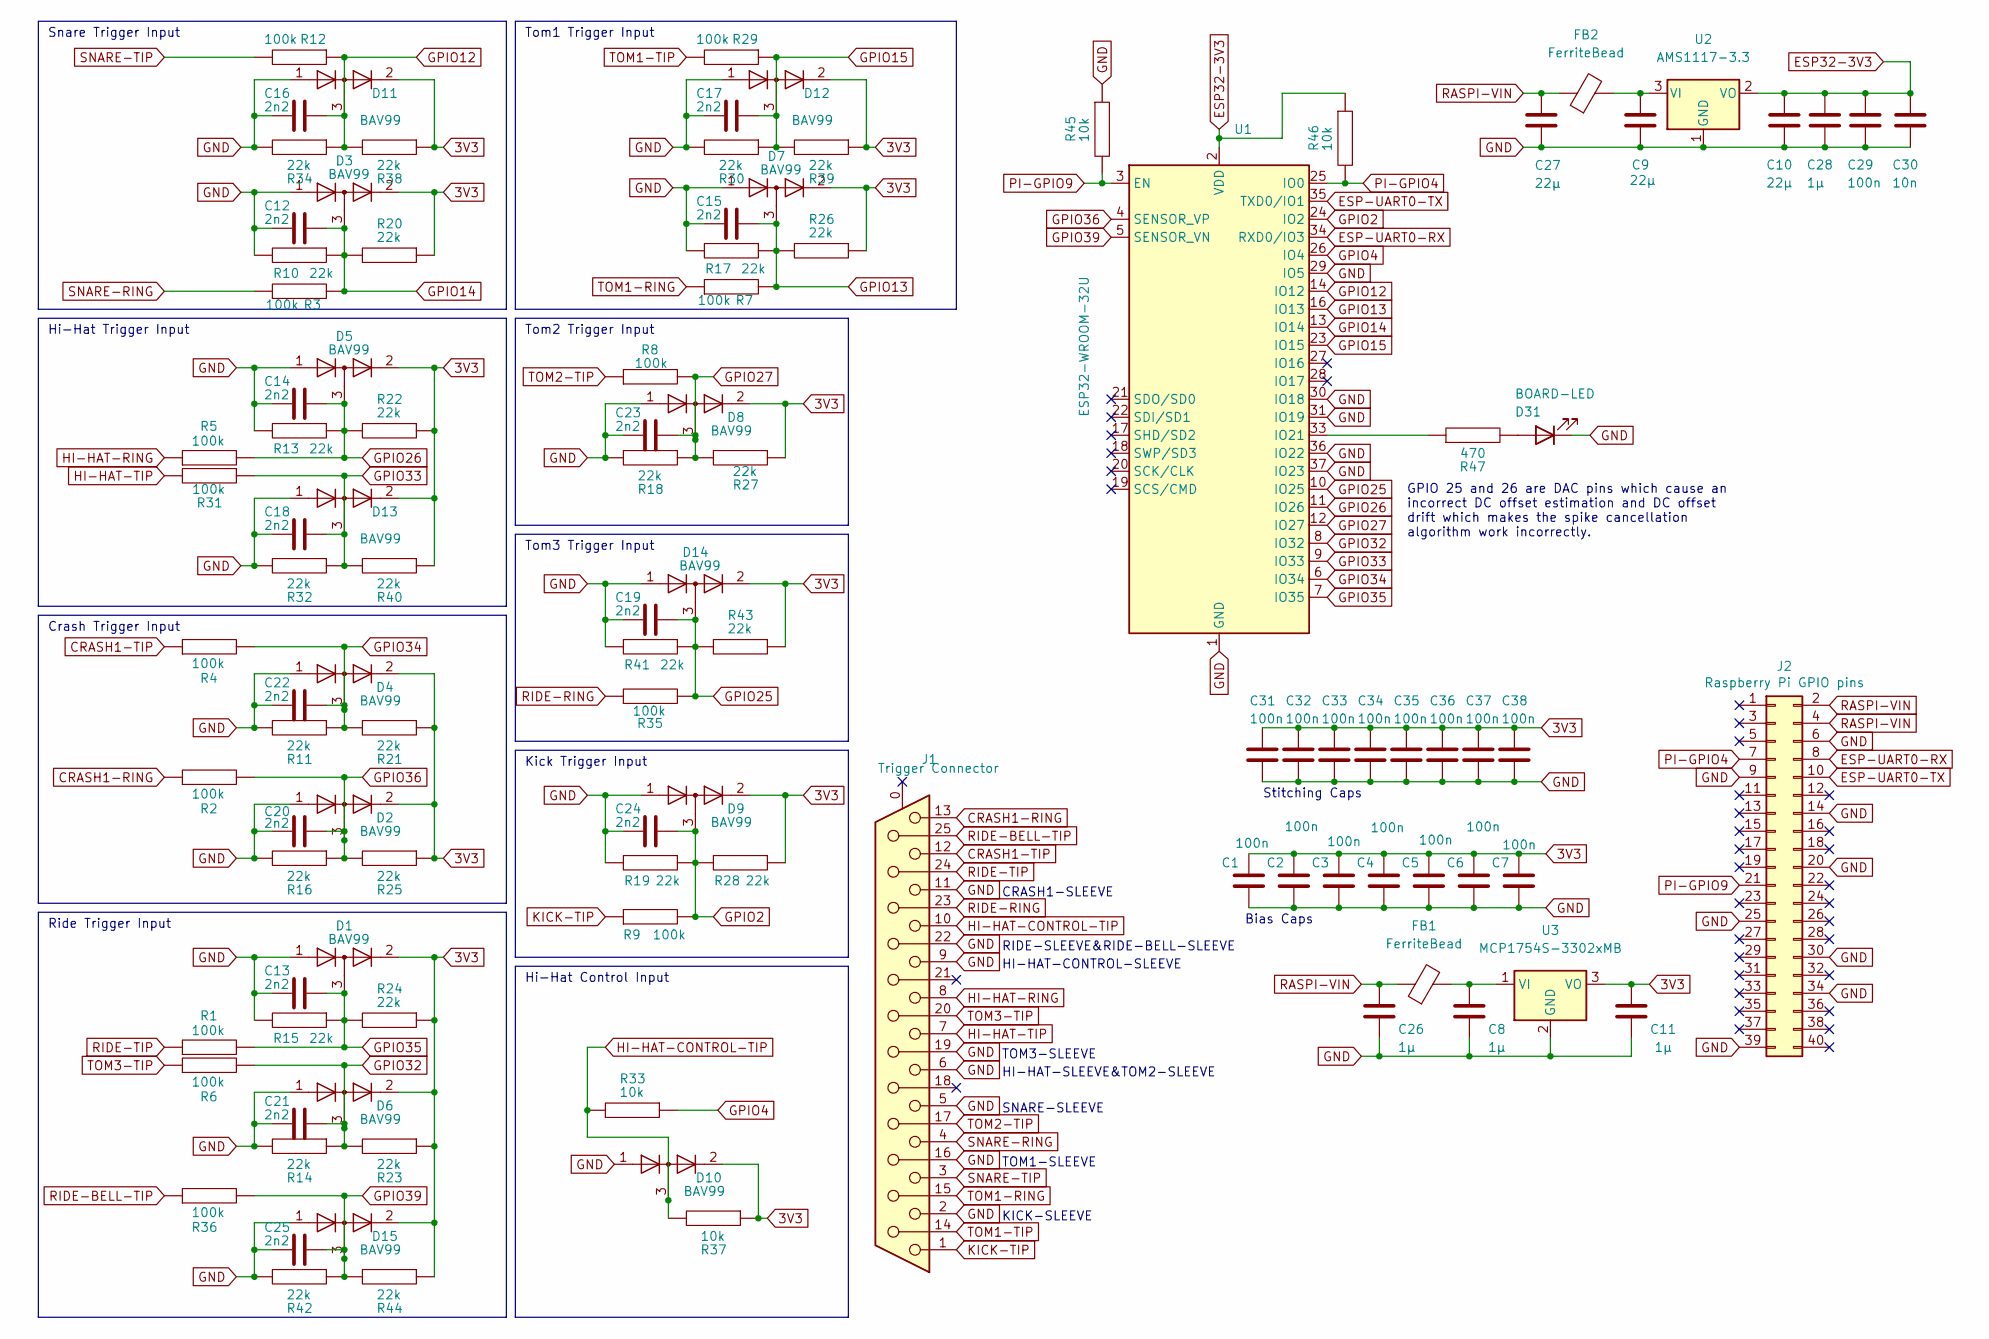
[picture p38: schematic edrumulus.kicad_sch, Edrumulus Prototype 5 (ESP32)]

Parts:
C1, C2, C3, C4, C5, C6, C7, C29, C31, C32, C33, C34, C35, C36, C37, C38: 100n; C_0603_1608Metric_Pad1.08x0.95mm_HandSolder
C8, C11, C26, C28: 1µ; C_0603_1608Metric_Pad1.08x0.95mm_HandSolder
C9, C10: 22µ; C_1210_3225Metric_Pad1.33x2.70mm_HandSolder
C12, C13, C14, C15, C16, C17, C18, C19, C20, C21, C22, C23, C24, C25: 2n2; C_0603_1608Metric_Pad1.08x0.95mm_HandSolder
C27: 22µ; C_0603_1608Metric_Pad1.08x0.95mm_HandSolder
C30: 10n; C_0603_1608Metric_Pad1.08x0.95mm_HandSolder
D1, D2, D3, D4, D5, D6, D7, D8, D9, D10, D11, D12, D13, D14, D15: BAV99; SOT-23
D31: BOARD-LED; LED_0603_1608Metric
FB1, FB2: FerriteBead; L_1210_3225Metric_Pad1.42x2.65mm_HandSolder
J1: Trigger Connector; DSUB-25_Female_Horizontal_P2.77x2.84mm_EdgePinOffset7.70mm_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
J2: Raspberry Pi GPIO pins; PinSocket_2x20_P2.54mm_Vertical
R1, R2, R3, R4, R5, R6, R7, R8, R9, R12, R29, R31, R35, R36: 100k; R_0603_1608Metric_Pad0.98x0.95mm_HandSolder
R10, R11, R13, R14, R15, R16, R17, R18, R19, R20, R21, R22, R23, R24, R25, R26, R27, R28, R30, R32, R34, R38, R39, R40, R41, R42, R43, R44: 22k; R_0603_1608Metric_Pad0.98x0.95mm_HandSolder
R33, R37, R45, R46: 10k; R_0603_1608Metric_Pad0.98x0.95mm_HandSolder
R47: 470; R_0603_1608Metric_Pad0.98x0.95mm_HandSolder
U1: ESP32-WROOM-32U
U2: AMS1117-3.3; SOT-223-3_TabPin2
U3: MCP1754S-3302xMB; SOT-89-3

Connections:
3V3: C1.2, C2.2, C3.2, C4.2, C5.2, C6.2, C7.2, C11.1, C31.1, C32.1, C33.1, C34.1, C35.1, C36.1, C37.1, C38.1, D1.2 (A), D2.2 (A), D3.2 (A), D4.2 (A), D5.2 (A), D6.2 (A), D7.2 (A), D8.2 (A), D9.2 (A), D10.2 (A), D11.2 (A), D12.2 (A), D13.2 (A), D14.2 (A), D15.2 (A), R20.1, R21.1, R22.1, R23.1, R24.1, R25.1, R26.1, R27.1, R28.1, R37.1, R38.1, R39.1, R40.1, R43.1, R44.1, U3.3 (VO)
CRASH1-RING: J1.13, R2.1
CRASH1-TIP: J1.12, R4.1
ESP32-3V3: C10.1, C28.1, C29.1, C30.1, R46.1, U1.2 (VDD), U2.2 (VO)
ESP-UART0-RX: J2.8, U1.34 (RXD0/IO3)
ESP-UART0-TX: J2.10, U1.35 (TXD0/IO1)
GND: C1.1, C2.1, C3.1, C4.1, C5.1, C6.1, C7.1, C8.2, C9.2, C10.2, C11.2, C12.2, C13.2, C14.2, C15.2, C16.2, C17.2, C18.2, C19.2, C20.2, C21.2, C22.2, C23.2, C24.2, C25.2, C26.2, C27.2, C28.2, C29.2, C30.2, C31.2, C32.2, C33.2, C34.2, C35.2, C36.2, C37.2, C38.2, D1.1 (K), D2.1 (K), D3.1 (K), D4.1 (K), D5.1 (K), D6.1 (K), D7.1 (K), D8.1 (K), D9.1 (K), D10.1 (K), D11.1 (K), D12.1 (K), D13.1 (K), D14.1 (K), D15.1 (K), D31.1 (K), J1.2, J1.5, J1.6, J1.9, J1.11, J1.16, J1.19, J1.22, J2.6, J2.9, J2.14, J2.20, J2.25, J2.30, J2.34, J2.39, R10.2, R11.2, R13.2, R14.2, R15.2, R16.2, R17.2, R18.2, R19.2, R30.2, R32.2, R34.2, R41.2, R42.2, R45.1, U1.1 (GND), U1.15 (GND), U1.29 (IO5), U1.30 (IO18), U1.31 (IO19), U1.36 (IO22), U1.37 (IO23), U1.38 (GND), U1.39 (GND), U2.1 (GND), U3.2 (GND)
GPIO2: C24.1, D9.3 (K), R9.2, R19.1, R28.2, U1.24 (IO2)
GPIO4: R33.1, U1.26 (IO4)
GPIO12: C16.1, D11.3 (K), R12.1, R34.1, R38.2, U1.14 (IO12)
GPIO13: C15.1, D7.3 (K), R7.2, R17.1, R26.2, U1.16 (IO13)
GPIO14: C12.1, D3.3 (K), R3.2, R10.1, R20.2, U1.13 (IO14)
GPIO15: C17.1, D12.3 (K), R29.1, R30.1, R39.2, U1.23 (IO15)
GPIO25: C19.1, D14.3 (K), R35.2, R41.1, R43.2, U1.10 (IO25)
GPIO26: C14.1, D5.3 (K), R5.2, R13.1, R22.2, U1.11 (IO26)
GPIO27: C23.1, D8.3 (K), R8.2, R18.1, R27.2, U1.12 (IO27)
GPIO32: C21.1, D6.3 (K), R6.2, R14.1, R23.2, U1.8 (IO32)
GPIO33: C18.1, D13.3 (K), R31.1, R32.1, R40.2, U1.9 (IO33)
GPIO34: C22.1, D4.3 (K), R4.2, R11.1, R21.2, U1.6 (IO34)
GPIO35: C13.1, D1.3 (K), R1.2, R15.1, R24.2, U1.7 (IO35)
GPIO36: C20.1, D2.3 (K), R2.2, R16.1, R25.2, U1.4 (SENSOR_VP)
GPIO39: C25.1, D15.3 (K), R36.2, R42.1, R44.2, U1.5 (SENSOR_VN)
HI-HAT-CONTROL-TIP: D10.3 (K), J1.10, R33.2, R37.2
HI-HAT-RING: J1.8, R5.1
HI-HAT-TIP: J1.7, R31.2
KICK-TIP: J1.1, R9.1
unnamed: C8.1, FB1.2, U3.1 (VI)
unnamed: C9.1, FB2.2, U2.3 (VI)
unnamed: D31.2 (A), R47.2
unnamed: R47.1, U1.33 (IO21)
PI-GPIO4: J2.7, R46.2, U1.25 (IO0)
PI-GPIO9: J2.21, R45.2, U1.3 (EN)
RASPI-VIN: C26.1, C27.1, FB1.1, FB2.1, J2.2, J2.4
RIDE-BELL-TIP: J1.25, R36.1
RIDE-RING: J1.23, R35.1
RIDE-TIP: J1.24, R1.1
SNARE-RING: J1.4, R3.1
SNARE-TIP: J1.3, R12.2
TOM1-RING: J1.15, R7.1
TOM1-TIP: J1.14, R29.2
TOM2-TIP: J1.17, R8.1
TOM3-TIP: J1.20, R6.1

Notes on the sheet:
Snare Trigger Input
KICK-SLEEVE
CRASH1-SLEEVE
SNARE-SLEEVE
HI-HAT-CONTROL-SLEEVE
HI-HAT-SLEEVE&TOM2-SLEEVE
Tom3 Trigger Input
RIDE-SLEEVE&RIDE-BELL-SLEEVE
Tom1 Trigger Input
Bias Caps
GPIO 25 and 26 are DAC pins which cause an incorrect DC offset estimation and DC offset drift which makes the spike cancellation algorithm work incorrectly.
Kick Trigger Input
Crash Trigger Input
Hi-Hat Trigger Input
Hi-Hat Control Input
TOM3-SLEEVE
Stitching Caps
TOM1-SLEEVE
Tom2 Trigger Input
Ride Trigger Input

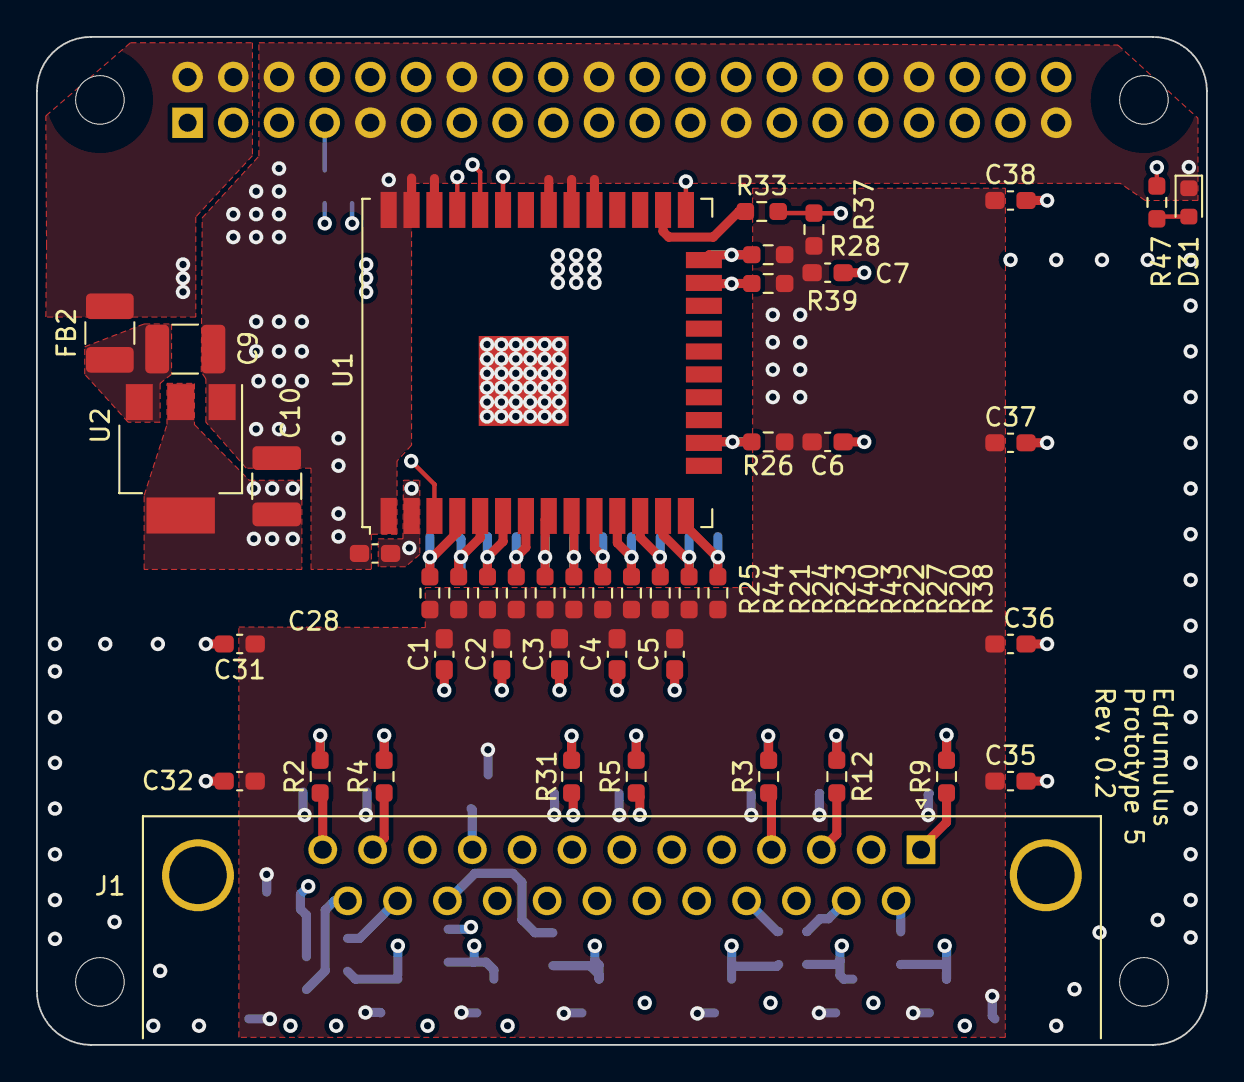
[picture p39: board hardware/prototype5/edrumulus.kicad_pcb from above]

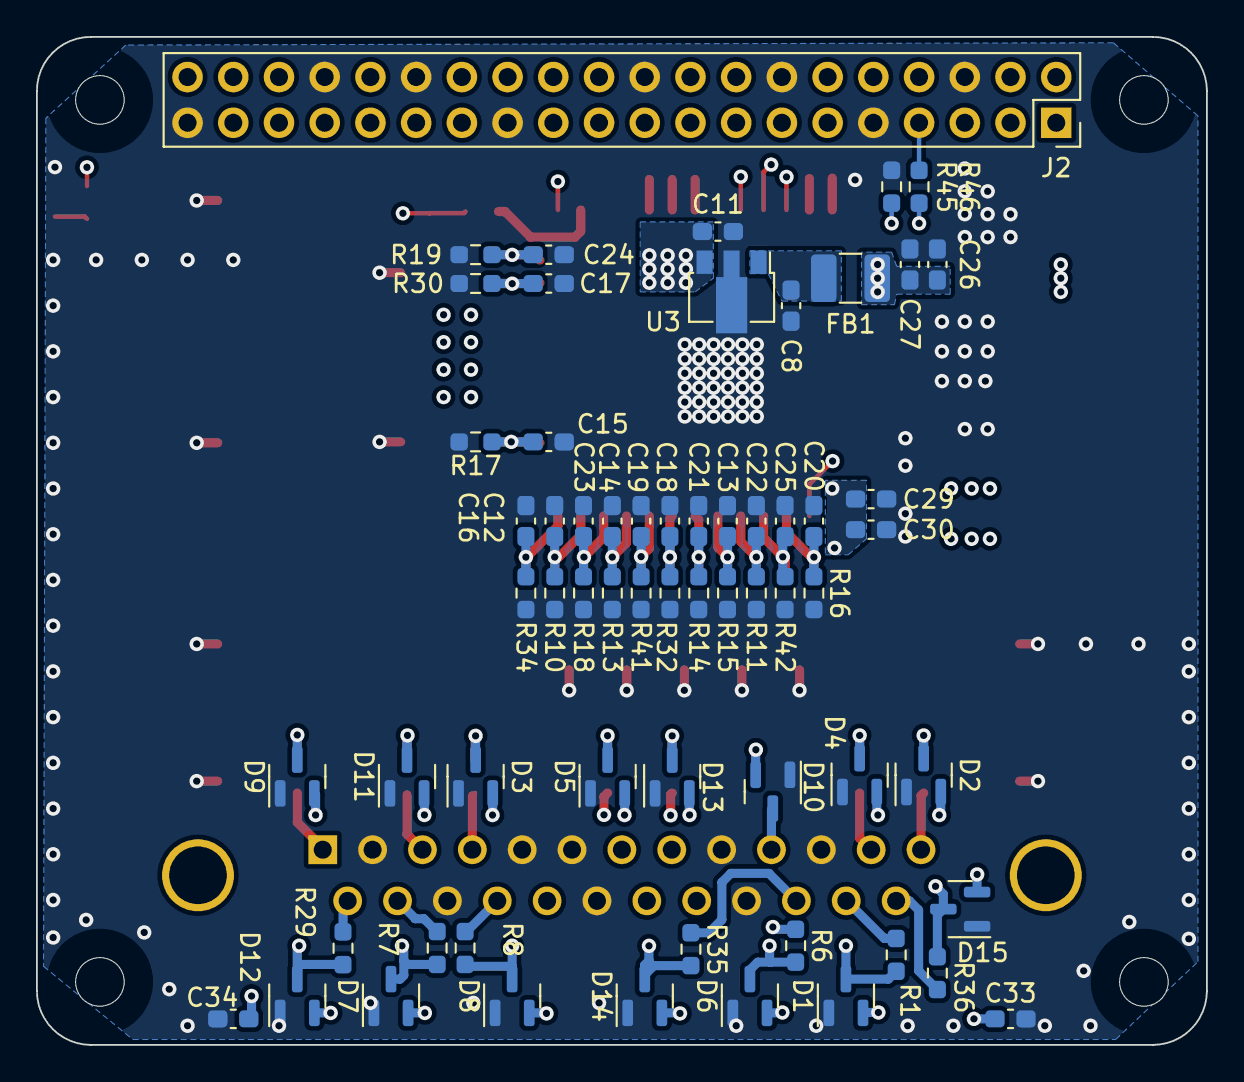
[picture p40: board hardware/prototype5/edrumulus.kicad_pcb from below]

Board: 4 copper layers, 65.0 x 56.0 mm, 112 parts (63 on the bottom side), 42 nets.

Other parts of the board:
MH1, MH2, MH3, MH4: MountingHole_2.7mm_M2.5

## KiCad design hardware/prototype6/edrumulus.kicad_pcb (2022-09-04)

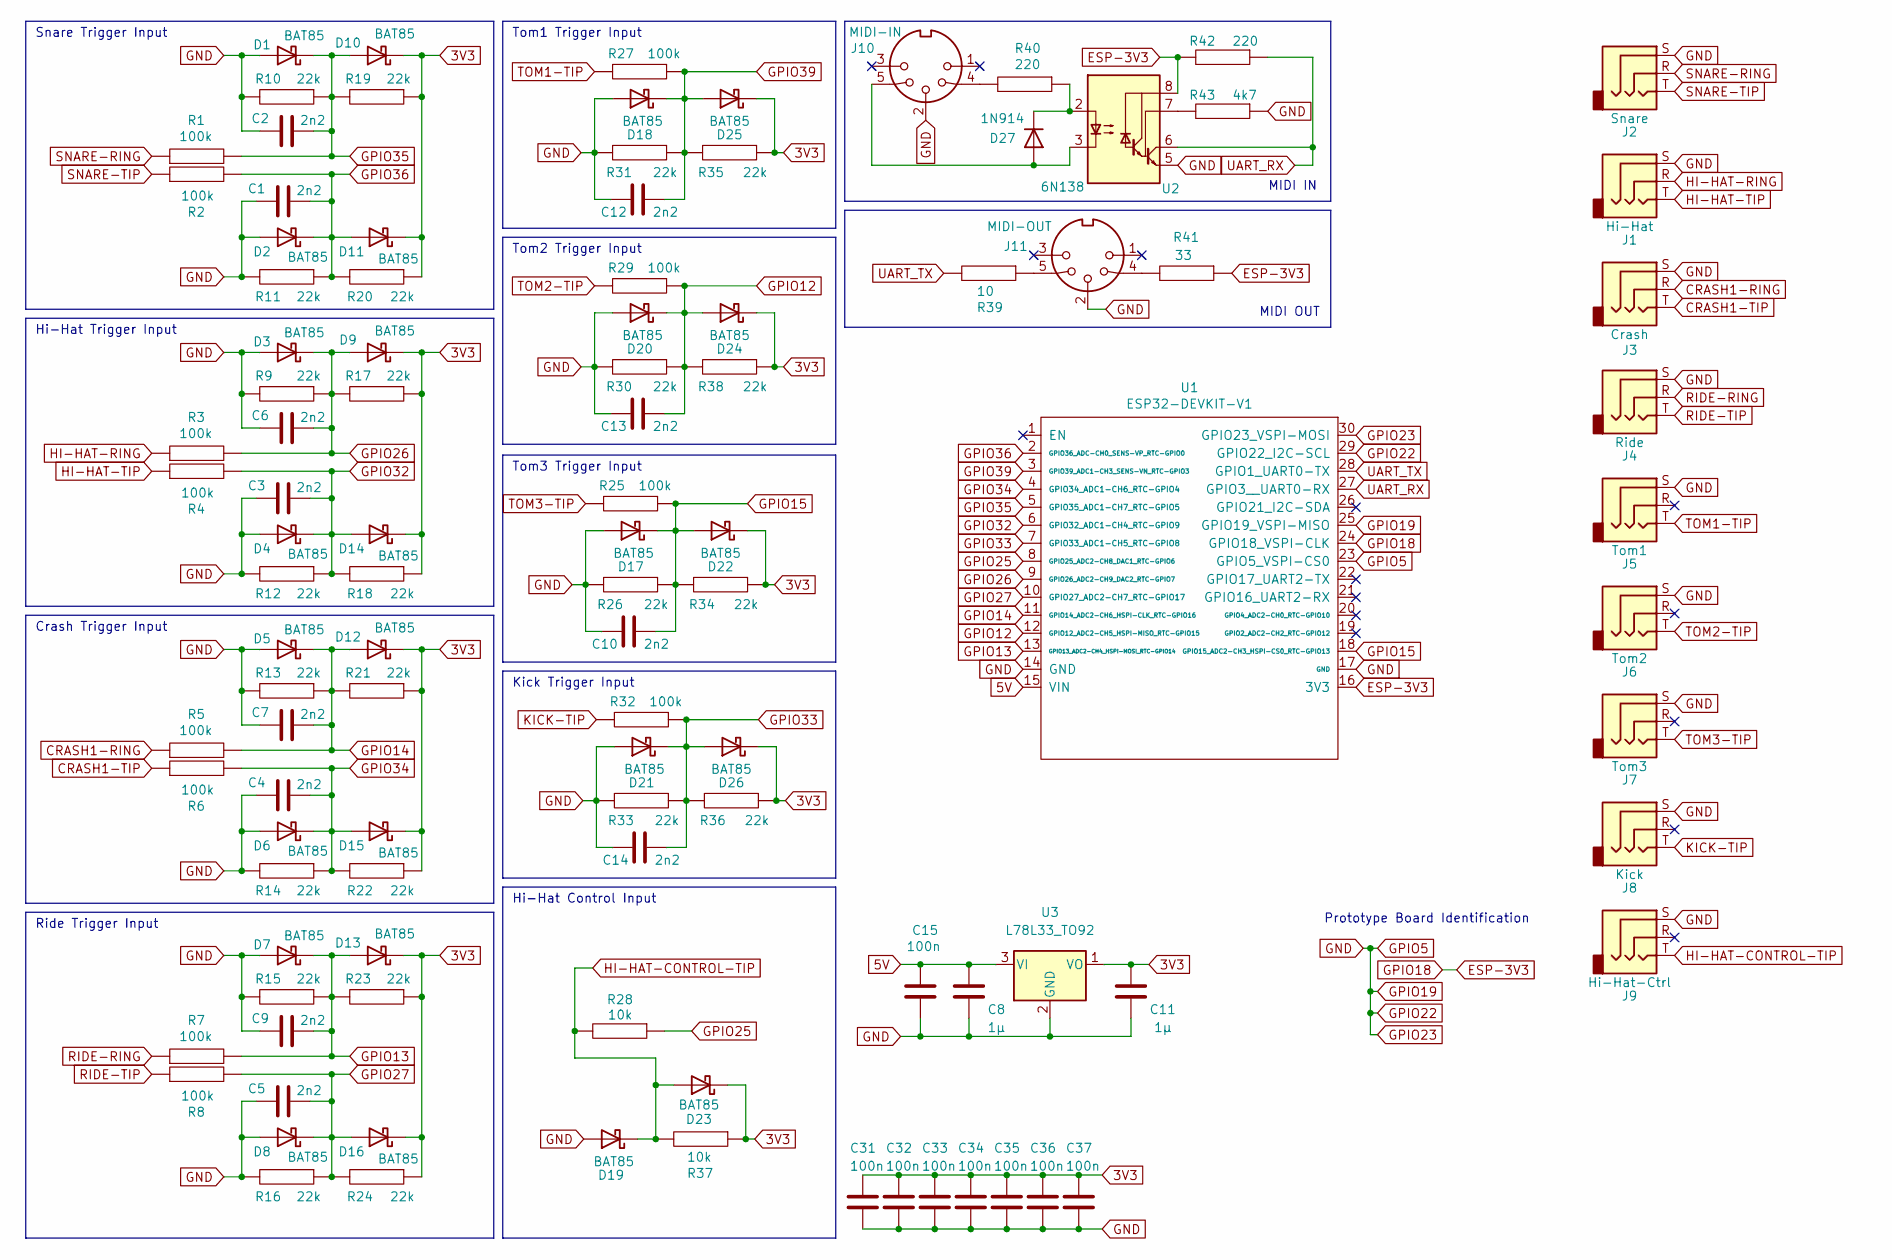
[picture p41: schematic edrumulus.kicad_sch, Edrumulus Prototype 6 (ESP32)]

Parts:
C1, C2, C3, C4, C5, C6, C7, C9, C10, C12, C13, C14: 2n2; C_Disc_D5.0mm_W2.5mm_P5.00mm
C8, C11: 1µ; CP_Radial_D8.0mm_P3.50mm
C15, C31, C32, C33, C34, C35, C36, C37: 100n; C_Disc_D5.0mm_W2.5mm_P5.00mm
D1, D2, D3, D4, D5, D6, D7, D8, D9, D10, D11, D12, D13, D14, D15, D16, D17, D18, D19, D20, D21, D22, D23, D24, D25, D26: BAT85; D_DO-35_SOD27_P7.62mm_Horizontal
D27: 1N914; D_DO-35_SOD27_P7.62mm_Horizontal
J1: Hi-Hat; Jack_6.35mm_Neutrik_NMJ6HCD2_Horizontal
J2: Snare; Jack_6.35mm_Neutrik_NMJ6HCD2_Horizontal
J3: Crash; Jack_6.35mm_Neutrik_NMJ6HCD2_Horizontal
J4: Ride; Jack_6.35mm_Neutrik_NMJ6HCD2_Horizontal
J5: Tom1; Jack_6.35mm_Neutrik_NMJ6HCD2_Horizontal
J6: Tom2; Jack_6.35mm_Neutrik_NMJ6HCD2_Horizontal
J7: Tom3; Jack_6.35mm_Neutrik_NMJ6HCD2_Horizontal
J8: Kick; Jack_6.35mm_Neutrik_NMJ6HCD2_Horizontal
J9: Hi-Hat-Ctrl; Jack_6.35mm_Neutrik_NMJ6HCD2_Horizontal
J10: MIDI-IN; DIN-5
J11: MIDI-OUT; DIN-5
R1, R2, R3, R4, R5, R6, R7, R8, R25, R27, R29, R32: 100k; R_Axial_DIN0207_L6.3mm_D2.5mm_P10.16mm_Horizontal
R9, R10, R11, R12, R13, R14, R15, R16, R17, R18, R19, R20, R21, R22, R23, R24, R26, R30, R31, R33, R34, R35, R36, R38: 22k; R_Axial_DIN0207_L6.3mm_D2.5mm_P10.16mm_Horizontal
R28, R37: 10k; R_Axial_DIN0207_L6.3mm_D2.5mm_P10.16mm_Horizontal
R39: 10; R_Axial_DIN0207_L6.3mm_D2.5mm_P10.16mm_Horizontal
R40, R42: 220; R_Axial_DIN0207_L6.3mm_D2.5mm_P10.16mm_Horizontal
R41: 33; R_Axial_DIN0207_L6.3mm_D2.5mm_P10.16mm_Horizontal
R43: 4k7; R_Axial_DIN0207_L6.3mm_D2.5mm_P10.16mm_Horizontal
U1: ESP32-DEVKIT-V1; esp32_devkit_v1
U2: 6N138; DIP-8_W7.62mm_Socket
U3: L78L33_TO92; TO-92_Inline

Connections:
3V3: C11.1, C31.1, C32.1, C33.1, C34.1, C35.1, C36.1, C37.1, D9.1 (K), D10.1 (K), D11.1 (K), D12.1 (K), D13.1 (K), D14.1 (K), D15.1 (K), D16.1 (K), D22.1 (K), D23.1 (K), D24.1 (K), D25.1 (K), D26.1 (K), R17.1, R18.1, R19.1, R20.1, R21.1, R22.1, R23.1, R24.1, R34.1, R35.1, R36.1, R37.1, R38.1, U3.1 (VO)
5V: C8.1, C15.1, U1.15 (VIN), U3.3 (VI)
CRASH1-RING: J3.R, R5.1
CRASH1-TIP: J3.T, R6.1
GPIO5: C1.2, C2.2, C3.2, C4.2, C5.2, C6.2, C7.2, C8.2, C9.2, C10.2, C11.2, C12.2, C13.2, C14.2, C15.2, C31.2, C32.2, C33.2, C34.2, C35.2, C36.2, C37.2, D1.2 (A), D2.2 (A), D3.2 (A), D4.2 (A), D5.2 (A), D6.2 (A), D7.2 (A), D8.2 (A), D17.2 (A), D18.2 (A), D19.2 (A), D20.2 (A), D21.2 (A), J1.S, J2.S, J3.S, J4.S, J5.S, J6.S, J7.S, J8.S, J9.S, J10.2, J11.2, R9.2, R10.2, R11.2, R12.2, R13.2, R14.2, R15.2, R16.2, R26.2, R30.2, R31.2, R33.2, R43.1, U1.14 (GND), U1.17 (GND), U1.23 (GPIO5_VSPI-CS0), U1.25 (GPIO19_VSPI-MISO), U1.29 (GPIO22_I2C-SCL), U1.30 (GPIO23_VSPI-MOSI), U2.5 (GND), U3.2 (GND)
GPIO12: C13.1, D20.1 (K), D24.2 (A), R29.1, R30.1, R38.2, U1.12 (GPIO12_ADC2-CH5_HSPI-MISO_RTC-GPIO15)
GPIO13: C9.1, D7.1 (K), D13.2 (A), R7.2, R15.1, R23.2, U1.13 (GPIO13_ADC2-CH4_HSPI-MOSI_RTC-GPIO14)
GPIO14: C7.1, D5.1 (K), D12.2 (A), R5.2, R13.1, R21.2, U1.11 (GPIO14_ADC2-CH6_HSPI-CLK_RTC-GPIO16)
GPIO15: C10.1, D17.1 (K), D22.2 (A), R25.1, R26.1, R34.2, U1.18 (GPIO15_ADC2-CH3_HSPI-CS0_RTC-GPIO13)
GPIO18: R41.1, R42.2, U1.16 (3V3), U1.24 (GPIO18_VSPI-CLK), U2.8 (VCC)
GPIO25: R28.1, U1.8 (GPIO25_ADC2-CH8_DAC1_RTC-GPIO6)
GPIO26: C6.1, D3.1 (K), D9.2 (A), R3.2, R9.1, R17.2, U1.9 (GPIO26_ADC2-CH9_DAC2_RTC-GPIO7)
GPIO27: C5.1, D8.1 (K), D16.2 (A), R8.2, R16.1, R24.2, U1.10 (GPIO27_ADC2-CH7_RTC-GPIO17)
GPIO32: C3.1, D4.1 (K), D14.2 (A), R4.2, R12.1, R18.2, U1.6 (GPIO32_ADC1-CH4_RTC-GPIO9)
GPIO33: C14.1, D21.1 (K), D26.2 (A), R32.1, R33.1, R36.2, U1.7 (GPIO33_ADC1-CH5_RTC-GPIO8)
GPIO34: C4.1, D6.1 (K), D15.2 (A), R6.2, R14.1, R22.2, U1.4 (GPIO34_ADC1-CH6_RTC-GPIO4)
GPIO35: C2.1, D1.1 (K), D10.2 (A), R1.2, R10.1, R19.2, U1.5 (GPIO35_ADC1-CH7_RTC-GPIO5)
GPIO36: C1.1, D2.1 (K), D11.2 (A), R2.2, R11.1, R20.2, U1.2 (GPIO36_ADC-CH0_SENS-VP_RTC-GPIO0)
GPIO39: C12.1, D18.1 (K), D25.2 (A), R27.1, R31.1, R35.2, U1.3 (GPIO39_ADC1-CH3_SENS-VN_RTC-GPIO3)
HI-HAT-CONTROL-TIP: D19.1 (K), D23.2 (A), J9.T, R28.2, R37.2
HI-HAT-RING: J1.R, R3.1
HI-HAT-TIP: J1.T, R4.1
KICK-TIP: J8.T, R32.2
unnamed: D27.1 (K), R40.1, U2.2 (C1)
unnamed: D27.2 (A), J10.5, U2.3 (C2)
unnamed: J10.4, R40.2
unnamed: J11.4, R41.2
unnamed: J11.5, R39.1
unnamed: R43.2, U2.7 (VO1)
RIDE-RING: J4.R, R7.1
RIDE-TIP: J4.T, R8.1
SNARE-RING: J2.R, R1.1
SNARE-TIP: J2.T, R2.1
TOM1-TIP: J5.T, R27.2
TOM2-TIP: J6.T, R29.2
TOM3-TIP: J7.T, R25.2
UART_RX: R42.1, U1.27 (GPIO3__UART0-RX), U2.6 (VO2)
UART_TX: R39.2, U1.28 (GPIO1_UART0-TX)

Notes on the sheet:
Tom3 Trigger Input
MIDI OUT
Hi-Hat Control Input
Tom1 Trigger Input
Prototype Board Identification
Kick Trigger Input
Ride Trigger Input
Hi-Hat Trigger Input
Snare Trigger Input
Crash Trigger Input
Tom2 Trigger Input
MIDI IN

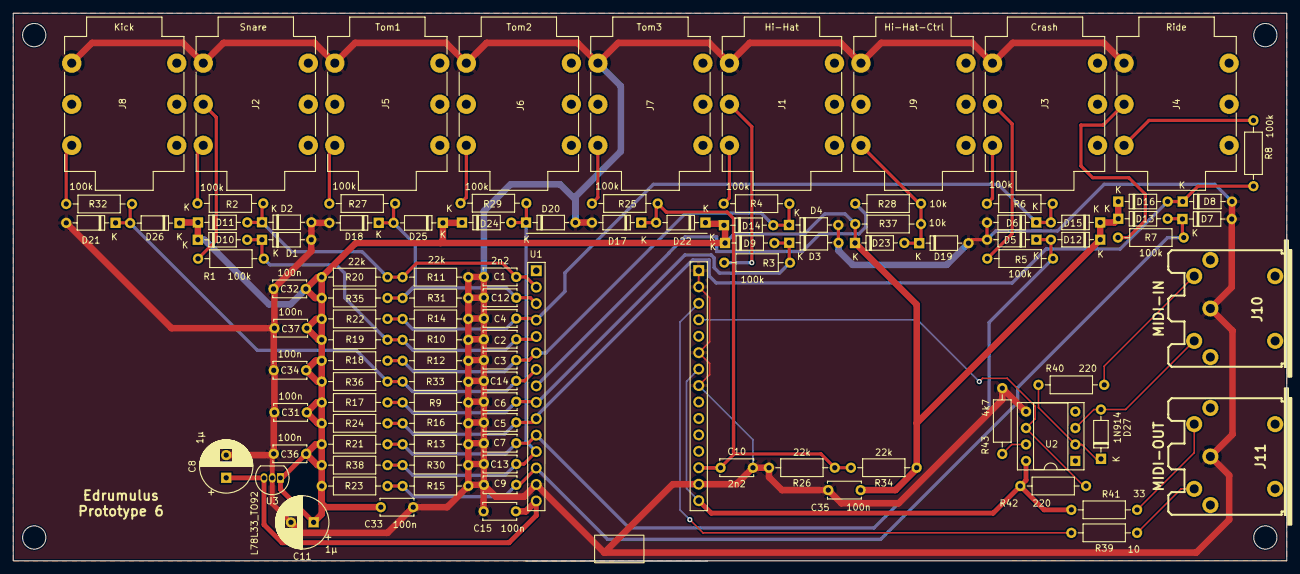
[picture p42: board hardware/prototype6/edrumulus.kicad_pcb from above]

Board: 2 copper layers, 196.7 x 84.6 mm, 106 parts (0 on the bottom side), 38 nets.

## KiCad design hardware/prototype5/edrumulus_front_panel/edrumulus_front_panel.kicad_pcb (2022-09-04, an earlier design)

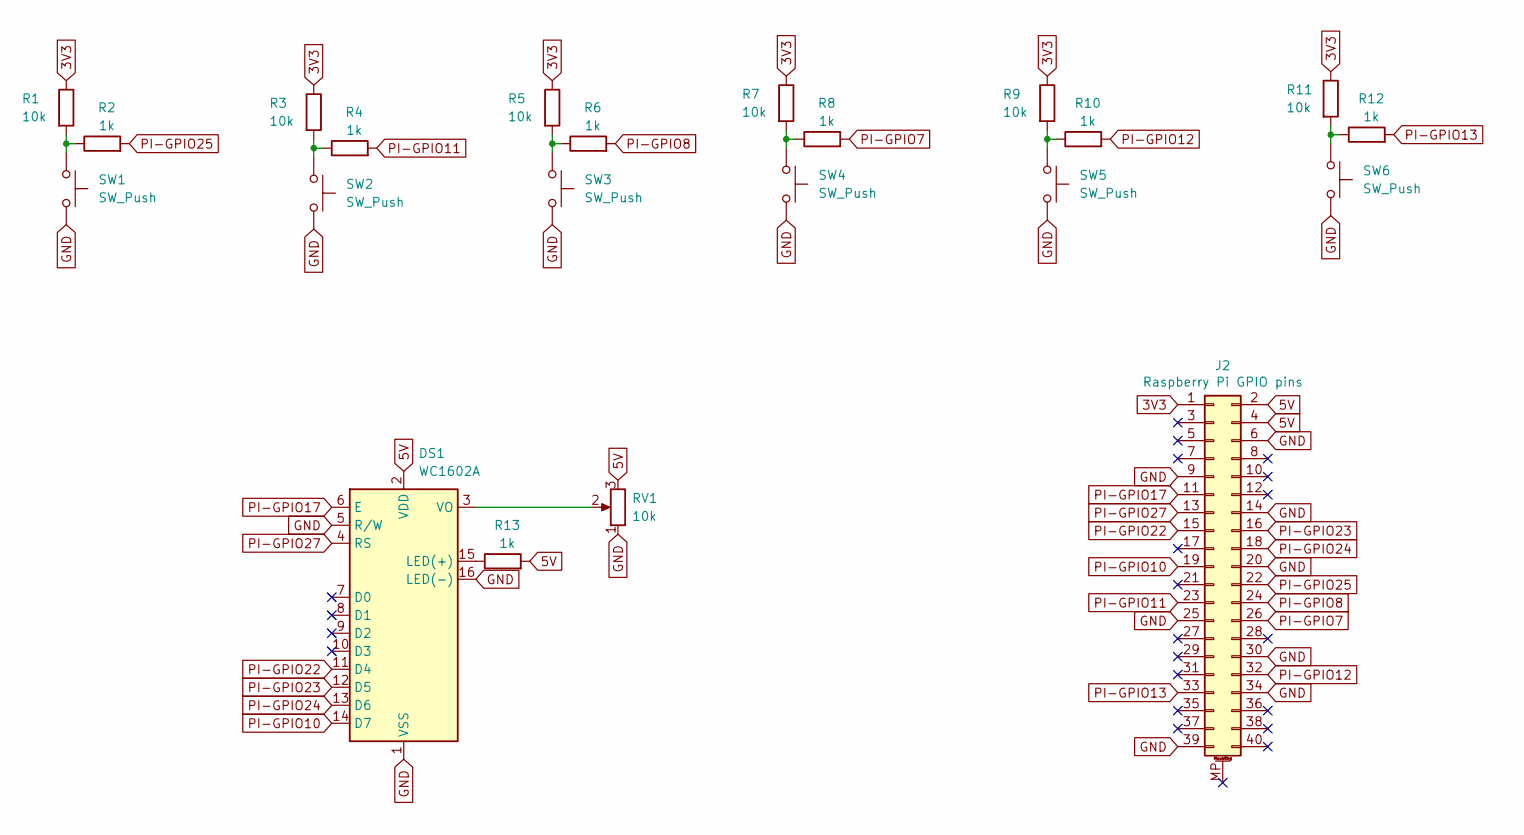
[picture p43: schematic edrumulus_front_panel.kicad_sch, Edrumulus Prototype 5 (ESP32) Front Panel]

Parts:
DS1: WC1602A
J2: Raspberry Pi GPIO pins; PinHeader_2x20_P2.54mm_Vertical
R1, R3, R5, R7, R9, R11: 10k; R_1206_3216Metric_Pad1.30x1.75mm_HandSolder
R2, R4, R6, R8, R10, R12, R13: 1k; R_1206_3216Metric_Pad1.30x1.75mm_HandSolder
RV1: 10k; Potentiometer_ACP_CA9-H2,5_Horizontal
SW1, SW2, SW3, SW4, SW5, SW6: SW_Push; SW_PUSH_6mm_H7.3mm

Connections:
3V3: J2.1, R1.1, R3.1, R5.1, R7.1, R9.1, R11.1
5V: DS1.2 (VDD), J2.2, J2.4, R13.2, RV1.3
GND: DS1.1 (VSS), DS1.5 (R/W), DS1.16 (LED(-)), J2.6, J2.9, J2.14, J2.20, J2.25, J2.30, J2.34, J2.39, RV1.1, SW1.2, SW2.2, SW3.2, SW4.2, SW5.2, SW6.2
unnamed: DS1.3 (VO), RV1.2
unnamed: DS1.15 (LED(+)), R13.1
unnamed: R1.2, R2.1, SW1.1
unnamed: R3.2, R4.1, SW2.1
unnamed: R5.2, R6.1, SW3.1
unnamed: R7.2, R8.1, SW4.1
unnamed: R9.2, R10.1, SW5.1
unnamed: R11.2, R12.1, SW6.1
PI-GPIO7: J2.26, R8.2
PI-GPIO8: J2.24, R6.2
PI-GPIO10: DS1.14 (D7), J2.19
PI-GPIO11: J2.23, R4.2
PI-GPIO12: J2.32, R10.2
PI-GPIO13: J2.33, R12.2
PI-GPIO17: DS1.6 (E), J2.11
PI-GPIO22: DS1.11 (D4), J2.15
PI-GPIO23: DS1.12 (D5), J2.16
PI-GPIO24: DS1.13 (D6), J2.18
PI-GPIO25: J2.22, R2.2
PI-GPIO27: DS1.4 (RS), J2.13

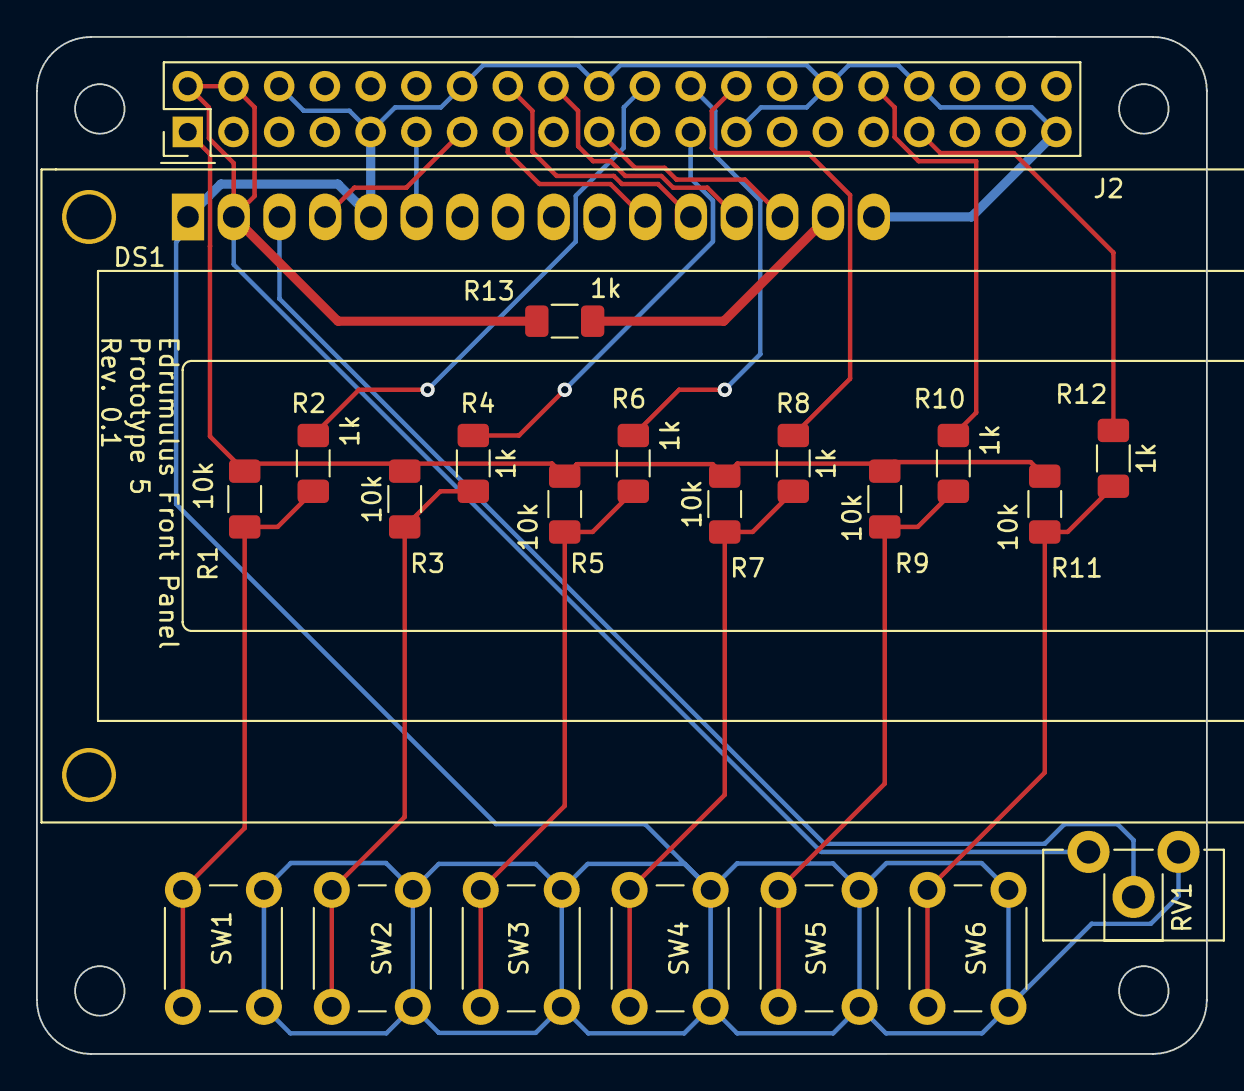
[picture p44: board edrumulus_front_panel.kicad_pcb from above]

Board: 2 copper layers, 65.0 x 56.5 mm, 22 parts (0 on the bottom side), 23 nets.

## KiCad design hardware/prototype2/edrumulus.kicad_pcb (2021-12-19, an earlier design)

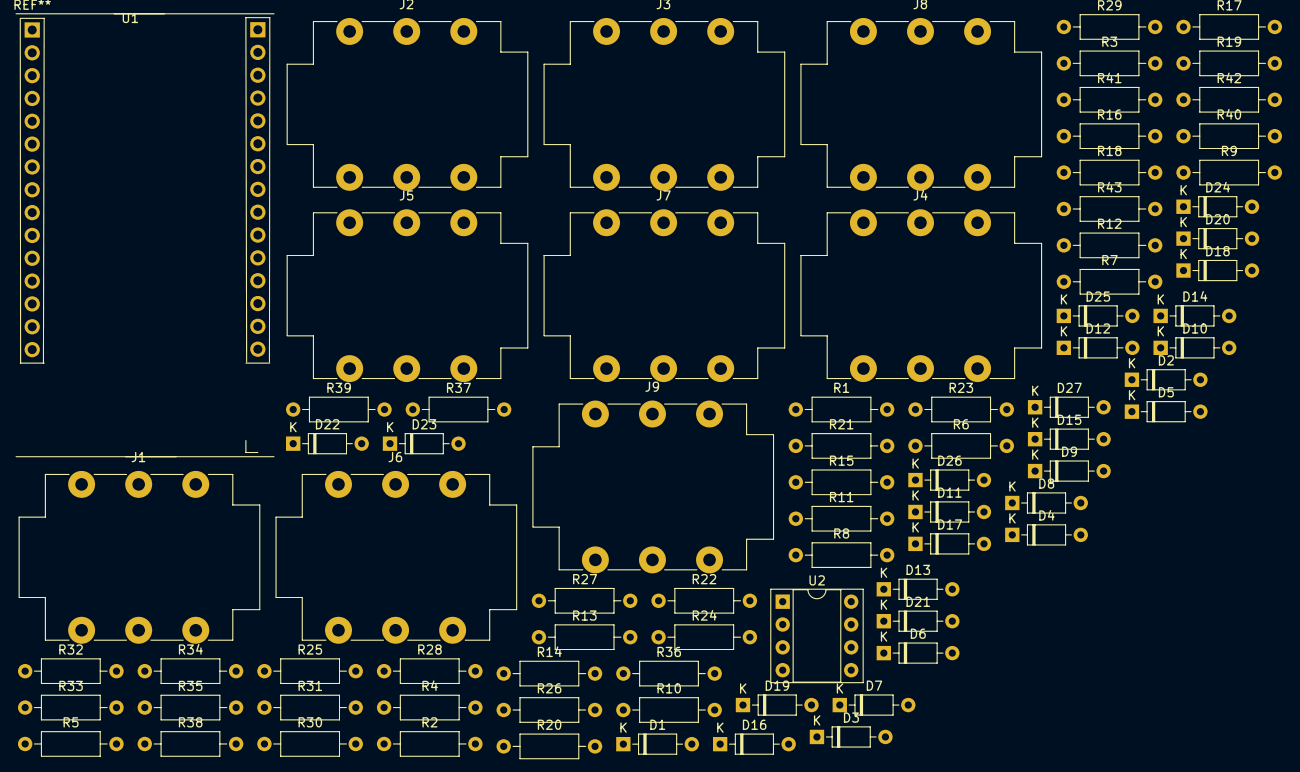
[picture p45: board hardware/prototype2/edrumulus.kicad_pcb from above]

Board: 2 copper layers, 81 parts (0 on the bottom side), 33 nets, no tracks yet.

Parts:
D1, D2, D3, D4, D5, D6, D7, D8, D9, D10, D11, D12, D13, D14, D15, D16, D17, D18, D19, D20, D21, D22, D23, D24, D25, D26: BAT85; D_DO-35_SOD27_P7.62mm_Horizontal
D27: 1N914; D_DO-35_SOD27_P7.62mm_Horizontal
J1: Snare; Jack_6.35mm_Neutrik_NMJ6HCD2_Horizontal
J2: Hi-Hat; Jack_6.35mm_Neutrik_NMJ6HCD2_Horizontal
J3: Crash; Jack_6.35mm_Neutrik_NMJ6HCD2_Horizontal
J4: Ride; Jack_6.35mm_Neutrik_NMJ6HCD2_Horizontal
J5: Kick; Jack_6.35mm_Neutrik_NMJ6HCD2_Horizontal
J6: Tom3; Jack_6.35mm_Neutrik_NMJ6HCD2_Horizontal
J7: Tom1; Jack_6.35mm_Neutrik_NMJ6HCD2_Horizontal
J8: Tom2; Jack_6.35mm_Neutrik_NMJ6HCD2_Horizontal
J9: Hi-Hat Ctrl; Jack_6.35mm_Neutrik_NMJ6HCD2_Horizontal
R1, R2, R3, R4, R5, R6, R7, R8, R25, R26, R27, R28: 100 kOhm; R_Axial_DIN0207_L6.3mm_D2.5mm_P10.16mm_Horizontal
R9, R10, R11, R12, R13, R14, R15, R16, R17, R18, R19, R20, R21, R22, R23, R24, R29, R30, R31, R32, R33, R34, R35, R36: 22 kOhm; R_Axial_DIN0207_L6.3mm_D2.5mm_P10.16mm_Horizontal
R37, R38: 10 kOhm; R_Axial_DIN0207_L6.3mm_D2.5mm_P10.16mm_Horizontal
R39, R40, R41, R42: 220 Ohm; R_Axial_DIN0207_L6.3mm_D2.5mm_P10.16mm_Horizontal
R43: 4.7 kOhm; R_Axial_DIN0207_L6.3mm_D2.5mm_P10.16mm_Horizontal
U1: ESP32-DEVKIT-V1; esp32_devkit_v1
U2: 6N138; DIP-8_W7.62mm_Socket

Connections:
3V3: D9.1, D10.1, D11.1, D12.1, D13.1, D14.1, D15.1, D16.1, D21.1, D22.1, D23.1, D24.1, D26.1, R17.1, R18.1, R19.1, R20.1, R21.1, R22.1, R23.1, R24.1, R33.1, R34.1, R35.1, R36.1, R38.1, R40.1, R42.2, U1.16, U2.8
GND: D1.2, D2.2, D3.2, D4.2, D5.2, D6.2, D7.2, D8.2, D17.2, D18.2, D19.2, D20.2, D25.2, J1.S, J2.S, J3.S, J4.S, J5.S, J6.S, J7.S, J8.S, J9.S, R9.2, R10.2, R11.2, R12.2, R13.2, R14.2, R15.2, R16.2, R29.2, R30.2, R31.2, R32.2, R43.1, U1.14, U2.5
GPIO12: D20.1, D24.2, R28.2, R32.1, R36.2, U1.12
GPIO13: D7.1, D15.2, R7.2, R15.1, R23.2, U1.13
GPIO14: D5.1, D13.2, R5.2, R13.1, R21.2, U1.11
GPIO15: D18.1, D22.2, R26.2, R30.1, R34.2, U1.18
GPIO25: R37.1, U1.8
GPIO26: D3.1, D11.2, R2.2, R11.1, R19.2, U1.9
GPIO27: D8.1, D16.2, R8.2, R16.1, R24.2, U1.10
GPIO32: D4.1, D12.2, R4.2, R12.1, R20.2, U1.6
GPIO33: D17.1, D21.2, R25.2, R29.1, R33.2, U1.7
GPIO34: D6.1, D14.2, R6.2, R14.1, R22.2, U1.4
GPIO35: D1.1, D9.2, R3.2, R9.1, R17.2, U1.5
GPIO36: D2.1, D10.2, R1.2, R10.1, R18.2, U1.2
GPIO39: D19.1, D23.2, R27.2, R31.1, R35.2, U1.3
unnamed: D25.1, D26.2, J9.T, R37.2, R38.2
unnamed: D27.1, R39.1, U2.2
unnamed: D27.2, U2.3
unnamed: J1.R, R3.1
unnamed: J1.T, R1.1
unnamed: J2.R, R2.1
unnamed: J2.T, R4.1
unnamed: J3.R, R5.1
unnamed: J3.T, R6.1
unnamed: J4.R, R7.1
unnamed: J4.T, R8.1
unnamed: J5.T, R25.1
unnamed: J6.T, R26.1
unnamed: J7.T, R27.1
unnamed: J8.T, R28.1
unnamed: R43.2, U2.7
UART_RX: R42.1, U1.21, U2.6
UART_TX: R41.2, U1.22

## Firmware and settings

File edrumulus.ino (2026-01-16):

// Copyright (c) 2020-2026 Volker Fischer
// SPDX-License-Identifier: GPL-2.0-or-later

// ESP32 default pin definition ("-1" means that this channel is unused):
// For older prototypes or custom implementations, simply change the GPIO numbers in the table below
// to match your hardware (note that the GPIO assignment of Prototype 2 is the same as Prototype 4).
// clang-format off
// analog pins setup:               snare | kick | hi-hat | hi-hat-ctrl | crash | tom1 | ride | tom2 | tom3 | crash2
static int analog_pins4[]         = { 36,    33,     32,       25,         34,     39,    27,    12,    15,     4 };
static int analog_pins_rimshot4[] = { 35,    -1,     26,       -1,         14,     -1,    13,    -1,    -1,     0 };
// clang-format on

// if you want to use less number of pads, simply adjust number_pads4 value
// const int number_pads4 = sizeof(analog_pins4) / sizeof(int); // example: use all inputs defined in analog_pins4
const int number_pads4 = 9; // example: do not use crash2 and shrink number of pads from 10 to 9
// const int number_pads4 = 1; // example: just one single pad

#include "edrumulus.h"

#ifdef USE_MIDI
#  ifdef ESP_PLATFORM
#    include <MIDI.h>
#    ifdef USE_TINYUSB
#      include <Adafruit_TinyUSB.h>
Adafruit_USBD_MIDI usb_midi;
MIDI_CREATE_INSTANCE(Adafruit_USBD_MIDI, usb_midi, MIDI);
#    else
MIDI_CREATE_DEFAULT_INSTANCE();
#    endif
#    define MYMIDI MIDI
#    define MIDI_CONTROL_CHANGE_TYPE midi::ControlChange
#    define MIDI_SEND_AFTER_TOUCH sendAfterTouch
#    define MIDI_SERIAL 38400
#  endif
#  ifdef TEENSYDUINO
#    define MYMIDI usbMIDI
#    define MIDI_CONTROL_CHANGE_TYPE usbMIDI.ControlChange
#    define MIDI_SEND_AFTER_TOUCH sendAfterTouchPoly
#  endif
#endif

// local variables and defines
Edrumulus edrumulus;
const int midi_channel      = 10;           // default for edrums is 10
const int hihat_pad_idx     = 2;            // this definition should not be changed
const int hihatctrl_pad_idx = 3;            // this definition should not be changed
int       number_pads       = number_pads4; // initialization value, may be overwritten by get_prototype_pins()
int       status_LED_pin    = 0;            // initialization value, will be set in get_prototype_pins()
bool      is_status_LED_on  = false;        // initialization value
int       selected_pad      = 0;            // initialization value

void setup()
{
  // get the pin-to-pad assignments
  int*      analog_pins         = analog_pins4;         // initialize with the default setup
  int*      analog_pins_rimshot = analog_pins_rimshot4; // initialize with the default setup
  const int prototype           = Edrumulus_hardware::get_prototype_pins(&analog_pins,
                                                               &analog_pins_rimshot,
                                                               &number_pads,
                                                               &status_LED_pin);

  // initialize GPIO port for status LED and set it to on during setup
  pinMode(status_LED_pin, OUTPUT);
  digitalWrite(status_LED_pin, HIGH);

#if defined(USE_SERIAL_DEBUG_PLOTTING) && defined(ESP_PLATFORM)
  number_pads = min(number_pads, 7); // only max. 7 pads are supported for ESP32 serial debug plotting
#endif
#ifdef USE_MIDI
#  ifdef USE_TINYUSB
  TinyUSBDevice.setProductDescriptor("Edrumulus");
#  endif
  MYMIDI.begin();
#endif
#ifdef MIDI_SERIAL
  if (prototype == 5)
  {
    Serial.begin(115200); // faster communication on prototype 5
  }
  else
  {
    Serial.begin(MIDI_SERIAL);
  }
#else
  Serial.begin(115200);
#endif

  edrumulus.setup(number_pads, analog_pins, analog_pins_rimshot);
  digitalWrite(status_LED_pin, LOW); // set board LED to low right after setup is done
#ifdef ESP_PLATFORM
  preset_settings(); // for ESP32, the load/save of settings is not supported, preset instead
#else
  read_settings();
#endif
}

void preset_settings()
{
  // default MIDI note assignments
  edrumulus.set_midi_notes(0, 38, 40); // snare
  edrumulus.set_midi_notes(1, 36, 36); // kick
  edrumulus.set_midi_notes(hihat_pad_idx, 22 /*42*/, 22);
  edrumulus.set_midi_notes_open(hihat_pad_idx, 26 /*46*/, 26);
  edrumulus.set_midi_notes(hihatctrl_pad_idx, 44, 44); // Hi-Hat pedal hit
  edrumulus.set_midi_notes(4, 49, 55);                 // crash
  edrumulus.set_midi_notes(5, 48, 50);                 // tom 1
  edrumulus.set_midi_notes(6, 51, 53 /*59*/);          // ride (edge: 59, bell: 53)
  edrumulus.set_midi_notes(7, 45, 47);                 // tom 2
  edrumulus.set_midi_notes(8, 43, 58);                 // tom 3
  edrumulus.set_midi_notes(9, 57, 52);                 // crash 2

  // default drum kit setup
  edrumulus.set_pad_type(0, Pad::PD8);  // snare
  edrumulus.set_pad_type(1, Pad::KD7);  // kick
  edrumulus.set_pad_type(2, Pad::PD6);  // Hi-Hat
  edrumulus.set_pad_type(3, Pad::FD8);  // Hi-Hat-ctrl
  edrumulus.set_pad_type(4, Pad::CY6);  // crash
  edrumulus.set_pad_type(5, Pad::TP80); // tom 1
  edrumulus.set_pad_type(6, Pad::CY8);  // ride
  edrumulus.set_pad_type(7, Pad::TP80); // tom 2
  edrumulus.set_pad_type(8, Pad::TP80); // tom 3
  edrumulus.set_pad_type(9, Pad::CY6);  // crash 2
}

void loop()
{
  // this function is blocking at the system sampling rate
  edrumulus.process();

  // status LED handling
  if (edrumulus.get_status_is_overload() || edrumulus.get_status_is_error())
  {
    if (!is_status_LED_on)
    {
      digitalWrite(status_LED_pin, HIGH);
      is_status_LED_on = true;
#ifdef USE_MIDI
      if (edrumulus.get_status_is_error())
      {
        const int dc_offset_error_channel = edrumulus.get_status_dc_offset_error_channel();
        if (dc_offset_error_channel >= 0)
        {
          // > 63 means DC offset error and pad/input index is coded in one value
          MYMIDI.sendNoteOff(125, 64 + dc_offset_error_channel, 1);
        }
        else
        {
          // 1 means to set error state
          MYMIDI.sendNoteOff(125, 1, 1);
        }
      }
#endif
    }
  }
  else
  {
    if (is_status_LED_on)
    {
      digitalWrite(status_LED_pin, LOW);
      is_status_LED_on = false;
#ifdef USE_MIDI
      MYMIDI.sendNoteOff(125, 0, 1); // 0 means that all errors are cleared
#endif
    }
  }

#ifdef USE_MIDI
  // load indicator
  if (const int load = edrumulus.get_load_indicator(); load >= 0)
  {
    MYMIDI.sendNoteOff(124, load, 1);
  }

  // send MIDI note to drum synthesizer
  for (int pad_idx = 0; pad_idx < number_pads; pad_idx++)
  {
    if (edrumulus.get_peak_found(pad_idx))
    {
      // get current MIDI note and velocity (maybe note will be overwritten later on)
      const int midi_velocity = edrumulus.get_midi_velocity(pad_idx);
      int       midi_note     = edrumulus.get_midi_note(pad_idx);

      // send midi positional control message if positional sensing is enabled for the current pad
      if (edrumulus.get_pos_sense_is_used(pad_idx))
      {
        const int midi_pos = edrumulus.get_midi_pos(pad_idx);
        MYMIDI.sendControlChange(16, midi_pos, midi_channel); // positional sensing
      }

      // send Hi-Hat control message right before each Hi-Hat pad hit
      if (pad_idx == hihat_pad_idx)
      {
        const int  midi_ctrl_ch    = edrumulus.get_midi_ctrl_ch(hihatctrl_pad_idx);
        const int  midi_ctrl_value = edrumulus.get_midi_ctrl_value(hihatctrl_pad_idx);
        const bool hi_hat_is_open  = edrumulus.get_midi_ctrl_is_open(hihatctrl_pad_idx);
        MYMIDI.sendControlChange(midi_ctrl_ch, midi_ctrl_value, midi_channel);

        // if Hi-Hat is open, overwrite MIDI note
        if (hi_hat_is_open)
        {
          midi_note = edrumulus.get_midi_note_open(pad_idx);
        }
      }

      MYMIDI.sendNoteOn(midi_note, midi_velocity, midi_channel); // (note, velocity, channel)
      MYMIDI.sendNoteOff(midi_note, 0, midi_channel);            // we need a note off
    }

    if (edrumulus.get_control_found(pad_idx))
    {
      const int midi_ctrl_ch    = edrumulus.get_midi_ctrl_ch(pad_idx);
      const int midi_ctrl_value = edrumulus.get_midi_ctrl_value(pad_idx);
      MYMIDI.sendControlChange(midi_ctrl_ch, midi_ctrl_value, midi_channel);
    }

    if (edrumulus.get_choke_on_found(pad_idx))
    {
      // special case: if MIDI note open rim is set to zero, we use NoteOn instead of aftertouch
      // for cymbal choke (#85), where the MIDI note for NoteOn is defined by MIDI note open norm
      if (edrumulus.get_midi_note_open_rim(pad_idx) == 0)
      {
        // special case: if grabbed edge found, we send a MIDI NoteOn
        const int midi_choke_noteon = edrumulus.get_midi_note_open_norm(pad_idx);
        MYMIDI.sendNoteOn(midi_choke_noteon, 127, midi_channel);
        MYMIDI.sendNoteOff(midi_choke_noteon, 0, midi_channel); // we need a note off
      }
      else
      {
        // if grabbed edge found, polyphonic aftertouch at 127 is transmitted for all notes of the pad
        MYMIDI.MIDI_SEND_AFTER_TOUCH(edrumulus.get_midi_note_norm(pad_idx), 127, midi_channel);
        MYMIDI.MIDI_SEND_AFTER_TOUCH(edrumulus.get_midi_note_rim(pad_idx), 127, midi_channel);
        MYMIDI.MIDI_SEND_AFTER_TOUCH(edrumulus.get_midi_note_open_norm(pad_idx), 127, midi_channel);
        MYMIDI.MIDI_SEND_AFTER_TOUCH(edrumulus.get_midi_note_open_rim(pad_idx), 127, midi_channel);
      }
    }
    else if (edrumulus.get_choke_off_found(pad_idx))
    {
      // if released edge found, polyphonic aftertouch at 0 is transmitted for all notes of the pad
      MYMIDI.MIDI_SEND_AFTER_TOUCH(edrumulus.get_midi_note_norm(pad_idx), 0, midi_channel);
      MYMIDI.MIDI_SEND_AFTER_TOUCH(edrumulus.get_midi_note_rim(pad_idx), 0, midi_channel);
      MYMIDI.MIDI_SEND_AFTER_TOUCH(edrumulus.get_midi_note_open_norm(pad_idx), 0, midi_channel);
      MYMIDI.MIDI_SEND_AFTER_TOUCH(edrumulus.get_midi_note_open_rim(pad_idx), 0, midi_channel);
    }
  }

  // receiving MIDI messages to change the pad settings: edrumuluscontrol.m -> loopMIDI -> Hairless MIDI
  if (MYMIDI.read(midi_channel))
  {
    if (MYMIDI.getType() == MIDI_CONTROL_CHANGE_TYPE)
    {
      const int controller = MYMIDI.getData1();
      const int value      = MYMIDI.getData2();

      // controller 102: pad type
      if (controller == 102)
      {
        edrumulus.set_pad_type(selected_pad, static_cast<Pad::Epadtype>(value));
        edrumulus.write_setting(selected_pad, 0, value);

        // on a pad type change, return all parameters of the selected pad
        confirm_setting(controller, value, true);
      }

      // controller 103: threshold
      if (controller == 103)
      {
        edrumulus.set_velocity_threshold(selected_pad, value);
        edrumulus.write_setting(selected_pad, 1, value);
        confirm_setting(controller, value, false);
      }

      // controller 104: sensitivity
      if (controller == 104)
      {
        edrumulus.set_velocity_sensitivity(selected_pad, value);
        edrumulus.write_setting(selected_pad, 2, value);
        confirm_setting(controller, value, false);
      }

      // controller 105: positional sensing threshold
      if (controller == 105)
      {
        edrumulus.set_pos_threshold(selected_pad, value);
        edrumulus.write_setting(selected_pad, 3, value);
        confirm_setting(controller, value, false);
      }

      // controller 106: positional sensing sensitivity
      if (controller == 106)
      {
        edrumulus.set_pos_sensitivity(selected_pad, value);
        edrumulus.write_setting(selected_pad, 4, value);
        confirm_setting(controller, value, false);
      }

      // controller 107: rim shot threshold
      if (controller == 107)
      {
        edrumulus.set_rim_shot_threshold(selected_pad, value);
        edrumulus.write_setting(selected_pad, 5, value);
        confirm_setting(controller, value, false);
      }

      // controller 108: select pad
      if ((controller == 108) && (value < MAX_NUM_PADS))
      {
        selected_pad = value;

        // on a pad selection, return all parameters of the selected pad
        confirm_setting(controller, value, true);
      }

      // controller 109: MIDI curve type
      if (controller == 109)
      {
        edrumulus.set_curve(selected_pad, static_cast<Pad::Ecurvetype>(value));
        edrumulus.write_setting(selected_pad, 6, value);
        confirm_setting(controller, value, false);
      }

      // controller 110: spike cancellation level
      if (controller == 110)
      {
        edrumulus.set_spike_cancel_level(value);
        edrumulus.write_setting(number_pads, 0, value);
        confirm_setting(controller, value, false);
      }

      // controller 111: enable/disable rim shot and positional sensing support
      if (controller == 111)
      {
        edrumulus.set_rim_shot_is_used(selected_pad, (value % 2) != 0);        // 0 1 0 1
        edrumulus.write_setting(selected_pad, 7, (value % 2) != 0);            // 0 1 0 1
        edrumulus.set_pos_sense_is_used(selected_pad, ((value / 2) % 2) != 0); // 0 0 1 1
        edrumulus.write_setting(selected_pad, 8, ((value / 2) % 2) != 0);      // 0 0 1 1
        confirm_setting(controller, value, false);
      }

      // controller 112: normal MIDI note
      if (controller == 112)
      {
        edrumulus.set_midi_note_norm(selected_pad, value);
        edrumulus.write_setting(selected_pad, 9, value);
        confirm_setting(controller, value, false);
      }

      // controller 113: MIDI note for rim
      if (controller == 113)
      {
        edrumulus.set_midi_note_rim(selected_pad, value);
        edrumulus.write_setting(selected_pad, 10, value);
        confirm_setting(controller, value, false);
      }

      // controller 114: cross talk cancellation
      if (controller == 114)
      {
        edrumulus.set_cancellation(selected_pad, value);
        edrumulus.write_setting(selected_pad, 11, value);
        confirm_setting(controller, value, false);
      }

      // controller 115: apply preset settings and store these to the EEPROM
      if (controller == 115)
      {
        preset_settings();
        write_all_settings();
        confirm_setting(controller, value, false);
      }

      // controller 116: normal MIDI note open (Hi-Hat)
      if (controller == 116)
      {
        edrumulus.set_midi_note_open_norm(selected_pad, value);
        edrumulus.write_setting(selected_pad, 12, value);
        confirm_setting(controller, value, false);
      }

      // controller 117: MIDI note open (Hi-Hat) for rim
      if (controller == 117)
      {
        edrumulus.set_midi_note_open_rim(selected_pad, value);
        edrumulus.write_setting(selected_pad, 13, value);
        confirm_setting(controller, value, false);
      }

      // controller 118: mask time
      if (controller == 118)
      {
        edrumulus.set_mask_time(selected_pad, value);
        edrumulus.write_setting(selected_pad, 14, value);
        confirm_setting(controller, value, false);
      }

      // controller 119: rim shot boost
      if (controller == 119)
      {
        edrumulus.set_rim_shot_boost(selected_pad, value);
        edrumulus.write_setting(selected_pad, 15, value);
        confirm_setting(controller, value, false);
      }

      // controller 120: pad coupling
      if (controller == 120)
      {
        edrumulus.set_coupled_pad_idx(selected_pad, value);
        edrumulus.write_setting(selected_pad, 16, value);
        confirm_setting(controller, value, false);
      }

      // controller 121: rim positional sensing threshold
      if (controller == 121)
      {
        edrumulus.set_rim_pos_threshold(selected_pad, value);
        edrumulus.write_setting(selected_pad, 17, value);
        confirm_setting(controller, value, false);
      }

      // controller 122: rim positional sensing sensitivity
      if (controller == 122)
      {
        edrumulus.set_rim_pos_sensitivity(selected_pad, value);
        edrumulus.write_setting(selected_pad, 18, value);
        confirm_setting(controller, value, false);
      }

      // controller 123: load indicator
      if (controller == 123)
      {
        edrumulus.set_enable_load_indicator(value);
        confirm_setting(controller, value, false);
      }
    }
  }
#endif
}

#ifdef USE_MIDI
// give feedback to the controller GUI via MIDI Note Off
void confirm_setting(const int  controller,
                     const int  value,
                     const bool send_all)
{
  if (send_all)
  {
    // return all parameters of the selected pad
    MYMIDI.sendNoteOff(102, static_cast<int>(edrumulus.get_pad_type(selected_pad)), 1);
    MYMIDI.sendNoteOff(103, edrumulus.get_velocity_threshold(selected_pad), 1);
    MYMIDI.sendNoteOff(104, edrumulus.get_velocity_sensitivity(selected_pad), 1);
    MYMIDI.sendNoteOff(105, edrumulus.get_pos_threshold(selected_pad), 1);
    MYMIDI.sendNoteOff(106, edrumulus.get_pos_sensitivity(selected_pad), 1);
    MYMIDI.sendNoteOff(107, edrumulus.get_rim_shot_threshold(selected_pad), 1);
    MYMIDI.sendNoteOff(108, selected_pad, 1);
    MYMIDI.sendNoteOff(109, static_cast<int>(edrumulus.get_curve(selected_pad)), 1);
    MYMIDI.sendNoteOff(110, edrumulus.get_spike_cancel_level(), 1);
    MYMIDI.sendNoteOff(111, edrumulus.get_rim_shot_is_used(selected_pad) + 2 * edrumulus.get_pos_sense_is_used(selected_pad), 1);
    MYMIDI.sendNoteOff(112, edrumulus.get_midi_note_norm(selected_pad), 1);
    MYMIDI.sendNoteOff(113, edrumulus.get_midi_note_rim(selected_pad), 1);
    MYMIDI.sendNoteOff(114, edrumulus.get_cancellation(selected_pad), 1);
    MYMIDI.sendNoteOff(116, edrumulus.get_midi_note_open_norm(selected_pad), 1);
    MYMIDI.sendNoteOff(117, edrumulus.get_midi_note_open_rim(selected_pad), 1);
    MYMIDI.sendNoteOff(118, edrumulus.get_mask_time(selected_pad), 1);
    MYMIDI.sendNoteOff(119, edrumulus.get_rim_shot_boost(selected_pad), 1);
    MYMIDI.sendNoteOff(120, edrumulus.get_coupled_pad_idx(selected_pad), 1);
    MYMIDI.sendNoteOff(121, edrumulus.get_rim_pos_threshold(selected_pad), 1);
    MYMIDI.sendNoteOff(122, edrumulus.get_rim_pos_sensitivity(selected_pad), 1);
    // NOTE: 123 is load indicator setting which is not stored
    // NOTE: 124 is reserved for load indicator
    // NOTE: 125 is reserved for error message
    MYMIDI.sendNoteOff(126, VERSION_MINOR, 1);
    MYMIDI.sendNoteOff(127, VERSION_MAJOR, 1);
  }
  else
  {
    // return only the given parameter
    MYMIDI.sendNoteOff(controller, value, 1); // can be checked, e.g., in the log file
  }
}
#endif

void read_settings()
{
  for (int i = 0; i < number_pads; i++)
  {
    // NOTE that it is important that set_pad_type() is called first because it resets all other parameters
    edrumulus.set_pad_type(i, static_cast<Pad::Epadtype>(edrumulus.read_setting(i, 0)));
    edrumulus.set_velocity_threshold(i, edrumulus.read_setting(i, 1));
    edrumulus.set_velocity_sensitivity(i, edrumulus.read_setting(i, 2));
    edrumulus.set_pos_threshold(i, edrumulus.read_setting(i, 3));
    edrumulus.set_pos_sensitivity(i, edrumulus.read_setting(i, 4));
    edrumulus.set_rim_shot_threshold(i, edrumulus.read_setting(i, 5));
    edrumulus.set_curve(i, static_cast<Pad::Ecurvetype>(edrumulus.read_setting(i, 6)));
    edrumulus.set_rim_shot_is_used(i, edrumulus.read_setting(i, 7));
    edrumulus.set_pos_sense_is_used(i, edrumulus.read_setting(i, 8));
    edrumulus.set_midi_note_norm(i, edrumulus.read_setting(i, 9));
    edrumulus.set_midi_note_rim(i, edrumulus.read_setting(i, 10));
    edrumulus.set_cancellation(i, edrumulus.read_setting(i, 11));
    edrumulus.set_midi_note_open_norm(i, edrumulus.read_setting(i, 12));
    edrumulus.set_midi_note_open_rim(i, edrumulus.read_setting(i, 13));
    edrumulus.set_mask_time(i, edrumulus.read_setting(i, 14));
    edrumulus.set_rim_shot_boost(i, edrumulus.read_setting(i, 15));
    edrumulus.set_coupled_pad_idx(i, edrumulus.read_setting(i, 16));
    edrumulus.set_rim_pos_threshold(i, edrumulus.read_setting(i, 17));
    edrumulus.set_rim_pos_sensitivity(i, edrumulus.read_setting(i, 18));
  }
  edrumulus.set_spike_cancel_level(edrumulus.read_setting(number_pads, 0));
}

void write_all_settings()
{
  for (int i = 0; i < number_pads; i++)
  {
    edrumulus.write_setting(i, 0, edrumulus.get_pad_type(i));
    edrumulus.write_setting(i, 1, edrumulus.get_velocity_threshold(i));
    edrumulus.write_setting(i, 2, edrumulus.get_velocity_sensitivity(i));
    edrumulus.write_setting(i, 3, edrumulus.get_pos_threshold(i));
    edrumulus.write_setting(i, 4, edrumulus.get_pos_sensitivity(i));
    edrumulus.write_setting(i, 5, edrumulus.get_rim_shot_threshold(i));
    edrumulus.write_setting(i, 6, edrumulus.get_curve(i));
    edrumulus.write_setting(i, 7, edrumulus.get_rim_shot_is_used(i));
    edrumulus.write_setting(i, 8, edrumulus.get_pos_sense_is_used(i));
    edrumulus.write_setting(i, 9, edrumulus.get_midi_note_norm(i));
    edrumulus.write_setting(i, 10, edrumulus.get_midi_note_rim(i));
    edrumulus.write_setting(i, 11, edrumulus.get_cancellation(i));
    edrumulus.write_setting(i, 12, edrumulus.get_midi_note_open_norm(i));
    edrumulus.write_setting(i, 13, edrumulus.get_midi_note_open_rim(i));
    edrumulus.write_setting(i, 14, edrumulus.get_mask_time(i));
    edrumulus.write_setting(i, 15, edrumulus.get_rim_shot_boost(i));
    edrumulus.write_setting(i, 16, edrumulus.get_coupled_pad_idx(i));
    edrumulus.write_setting(i, 17, edrumulus.get_rim_pos_threshold(i));
    edrumulus.write_setting(i, 18, edrumulus.get_rim_pos_sensitivity(i));
  }
  edrumulus.write_setting(number_pads, 0, edrumulus.get_spike_cancel_level());
}

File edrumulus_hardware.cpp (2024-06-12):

/******************************************************************************\
 * Copyright (c) 2020-2024
 * Author(s): Volker Fischer
 ******************************************************************************
 * This program is free software; you can redistribute it and/or modify it under
 * the terms of the GNU General Public License as published by the Free Software
 * Foundation; either version 2 of the License, or (at your option) any later
 * version.
 * This program is distributed in the hope that it will be useful, but WITHOUT
 * ANY WARRANTY; without even the implied warranty of MERCHANTABILITY or FITNESS
 * FOR A PARTICULAR PURPOSE. See the GNU General Public License for more
 * details.
 * You should have received a copy of the GNU General Public License along with
 * this program; if not, write to the Free Software Foundation, Inc.,
 * 51 Franklin Street, Fifth Floor, Boston, MA  02110-1301, USA
\******************************************************************************/

#include "edrumulus_hardware.h"

Edrumulus_hardware* edrumulus_hardware_pointer = nullptr;

Edrumulus_hardware::Edrumulus_hardware()
{
  // global pointer to this class needed for static callback function
  edrumulus_hardware_pointer = this;
}


// -----------------------------------------------------------------------------
// Teensy 4.0/4.1/3.6 ----------------------------------------------------------
// -----------------------------------------------------------------------------
#ifdef TEENSYDUINO

int Edrumulus_hardware::get_prototype_pins ( int** analog_pins,
                                             int** analog_pins_rimshot,
                                             int*  number_pins,
                                             int*  status_LED_pin )
{
  // analog pins setup:               snare | kick | hi-hat | hi-hat-ctrl | crash | tom1 | ride | tom2 | tom3
  static int analog_pins1[]         = { A10,   A11,   A12,        A13,       A1,     A6,    A4,    A5 };
  static int analog_pins_rimshot1[] = {  A9,    -1,    A0,         -1,       A3,     A8,    A2,    A7 };
  *analog_pins         = analog_pins1;
  *analog_pins_rimshot = analog_pins_rimshot1;
  *number_pins         = sizeof ( analog_pins1 ) / sizeof ( int );
  *status_LED_pin      = BOARD_LED_PIN;
  return 0;
}


void Edrumulus_hardware::setup ( const int conf_Fs,
                                 const int number_pads,
                                 const int number_inputs[],
                                 int       analog_pin[][MAX_NUM_PAD_INPUTS] )
{
  // set essential parameters
  Fs = conf_Fs;

  // create linear vectors containing the pin information for each pad and pad-input
  total_number_inputs = 0; // we use it as a counter, too

  for ( int i = 0; i < number_pads; i++ )
  {
    for ( int j = 0; j < number_inputs[i]; j++ )
    {
      // store pin number in vector
      input_pin[total_number_inputs] = analog_pin[i][j];
      total_number_inputs++;

#if defined(ARDUINO_TEENSY40) || defined(ARDUINO_TEENSY41) // Teensy 4.0/4.1 specific code
      // disable MIMXRT1062DVL6A "keeper" on all Teensy 4.0/4.1 ADC input pins
      // NOTE: pinMode() needs absolute pin numbers, e.g. 0 for A0 will not work
      pinMode ( analog_pin[i][j], INPUT_DISABLE );
#endif
    }
  }

  // set the ADC properties: averaging 8 samples with high speed sampling gives
  // us the best compromise between ADC speed and spike protection
  adc_obj.adc0->setResolution      ( 12 ); // we want to get the full ADC resolution of the Teensy 4.0
  adc_obj.adc0->setAveraging       ( 8 );
  adc_obj.adc0->setConversionSpeed ( ADC_CONVERSION_SPEED::HIGH_SPEED );
  adc_obj.adc0->setSamplingSpeed   ( ADC_SAMPLING_SPEED::HIGH_SPEED );
  adc_obj.adc1->setResolution      ( 12 ); // we want to get the full ADC resolution of the Teensy 4.0
  adc_obj.adc1->setAveraging       ( 8 );
  adc_obj.adc1->setConversionSpeed ( ADC_CONVERSION_SPEED::HIGH_SPEED );
  adc_obj.adc1->setSamplingSpeed   ( ADC_SAMPLING_SPEED::HIGH_SPEED );

  // wait for ADC calibration to complete
  adc_obj.adc0->wait_for_cal();
  adc_obj.adc1->wait_for_cal();

  // initialize timer flag (semaphore)
  timer_ready = false;

  // prepare timer at a rate of given sampling rate
  myTimer.begin ( on_timer, 1000000 / Fs ); // here we define the sampling rate (1 MHz / Fs)
}


void Edrumulus_hardware::write_setting ( const int  pad_index,
                                         const int  address,
                                         const byte value )
{
  EEPROM.update ( pad_index * MAX_NUM_SET_PER_PAD + address, value );
}


byte Edrumulus_hardware::read_setting ( const int pad_index,
                                        const int address )
{
  return EEPROM.read ( pad_index * MAX_NUM_SET_PER_PAD + address );
}


void Edrumulus_hardware::on_timer()
{
  // tell the main loop that a sample can be read by setting the flag (semaphore)
  edrumulus_hardware_pointer->timer_ready = true;
}
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

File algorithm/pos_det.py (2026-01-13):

#!/usr/bin/env python3

# Copyright (c) 2022-2026 Volker Fischer
# SPDX-License-Identifier: GPL-2.0-or-later

import numpy as np
import matplotlib.pyplot as plt
import matplotlib.gridspec as gridspec
import matplotlib.patches as mpatches
import serial

# initializations
try:
  ser = serial.Serial('/dev/ttyUSB0', 115200, timeout=0.01)
except:
  ser = [] # in error case "ser" is a list (is checked below)
print('close plot window to quit')
click_point  = (None, None)
sensor1      = np.array(0.433, dtype=complex)
sensor1.imag = 0.25
sensor2      = np.array(0, dtype=complex)
sensor2.imag = -0.5
sensor3      = np.array(-0.433, dtype=complex)
sensor3.imag = 0.25
rim_radius   = 0.75
fig          = plt.figure(tight_layout=True)
gs           = gridspec.GridSpec(1, 1)
ax0          = fig.add_subplot(gs[0])
fignum       = fig.number
plt.ion()
plt.axis('square')


def onclick(event):
  global click_point
  click_point = (event.xdata, event.ydata)


def get_position(r1, r2):
  # code taken from https://github.com/corrados/edrumulus/discussions/70#discussioncomment-4014893
  # created by jstma:
  # these equations can be calculated in the initialization
  x0               = sensor1.real
  y0               = sensor1.imag
  x1               = sensor2.real
  y1               = sensor2.imag
  x2               = sensor3.real
  y2               = sensor3.imag
  x0_sq_plus_y0_sq = x0 * x0 + y0 * y0
  a1               = 2 * (x0 - x1)
  b1               = 2 * (y0 - y1)
  a2               = 2 * (x0 - x2)
  b2               = 2 * (y0 - y2)
  div1             = a1 * b2 - a2 * b1
  div2             = a2 * b1 - a1 * b2

  # these equations have to calculated for each position detection
  c1      = r1 * r1 + x0_sq_plus_y0_sq - x1 * x1 - y1 * y1
  c2      = r2 * r2 + x0_sq_plus_y0_sq - x2 * x2 - y2 * y2
  d1      = (2 * r1 * b2 - 2 * r2 * b1) / div1
  e1      = (    c1 * b2 -     c2 * b1) / div1
  d2      = (2 * r1 * a2 - 2 * r2 * a1) / div2
  e2      = (    c1 * a2 -     c2 * a1) / div2
  d_e1_x0 = e1 - x0
  d_e2_y0 = e2 - y0
  a       = d1 * d1 + d2 * d2 - 1
  b       = 2 * d_e1_x0 * d1 + 2 * d_e2_y0 * d2
  c       = d_e1_x0 * d_e1_x0 + d_e2_y0 * d_e2_y0

  # two solutions to the quadratic equation, only one solution seems to always be correct
  r_2 = (-b - np.sqrt(b * b - 4 * a * c)) / (2 * a)
  x   = d1 * r_2 + e1
  y   = d2 * r_2 + e2
  r   = np.sqrt(x * x + y * y)

  # clip calculated radius to rim radius
  if r > rim_radius:
    r = rim_radius
  return x, y, r


cid = fig.canvas.mpl_connect('button_press_event', onclick)
while True:
  ax0.cla()

  # pad edge boundary circle
  ax0.add_patch(mpatches.Circle((0.5, 0.5), rim_radius, fill=False, linewidth=4))
  plt.text(0.44, -0.17, "Drums", weight="bold")

  # sensors
  plt.scatter(sensor1.real + 0.5, sensor1.imag + 0.5, marker="x", c="g", s=150)
  plt.scatter(sensor2.real + 0.5, sensor2.imag + 0.5, marker="x", c="g", s=150)
  plt.scatter(sensor3.real + 0.5, sensor3.imag + 0.5, marker="x", c="g", s=150)

  # create current mouse click vector
  click_vector      = np.array(click_point[0], dtype=complex)
  click_vector.imag = click_point[1];
  click_vector     -= 0.5 + 0.5j

  l1 = np.abs(click_vector - sensor1)
  l2 = np.abs(click_vector - sensor2)
  l3 = np.abs(click_vector - sensor3)

  l21 = l2 - l1
  l31 = l3 - l1
  l32 = l3 - l2

  # approximation of distance: r = max(|L21|, |L31|, |L32|) (using some magic factor of 0.7)
  r_est = np.max(np.array([np.abs(l21), np.abs(l31), np.abs(l32)])) * 0.7

  # get position algorithm
  x_get, y_get, r_get = get_position(l21, l31)

  # show ideal circle (dashed) and circle based on approximation
  ax0.add_patch(mpatches.Circle((0.5, 0.5), np.abs(click_vector), fill=False, color="b", ls='--'))
  ax0.add_patch(mpatches.Circle((0.5, 0.5), r_est, fill=False, color="b", lw=2))

  # show click point and get position point
  plt.scatter(click_point[0], click_point[1], marker="*", c="r", s=100)
  plt.scatter(x_get + 0.5, y_get + 0.5, marker="*", c="g", s=100)

  # for a test return measured differences via a serial string from Edrumulus
  if type(ser) is not list: # check for valid "ser" object
    a = ser.readline().decode("utf-8")
    if len(a) > 0:
      a = a.split(",")[0:3] # use this if x and y are sent with Serial.println
      a = [float(x) for x in a]
      print(a)
      if a[2] == 1000: # marker
        plt.scatter(a[0] + 0.5, a[1] + 0.5, marker="*", c="b", s=700)
      else:
        x_get, y_get, r_get = get_position(a[0] / 17, a[1] / 17)
        if np.sqrt(x_get * x_get + y_get * y_get) <= rim_radius:
          plt.scatter(x_get + 0.5, y_get + 0.5, marker="*", c="b", s=700)
        ax0.add_patch(mpatches.Circle((0.5, 0.5), r_get, fill=False, color="g", ls='--'))
      plt.pause(0.05)

  plt.show()
  plt.pause(0.03)
  if not plt.fignum_exists(fignum): # if plot window is closed then quit
    break

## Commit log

2021-09-22 Added algorithm for checking the initial peak that it is not too small. It checks in the scan time for peaks that are 20 dB higher than the initial peak. If such a peak is found, this peak is used in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
2021-09-24 bug fix: velocity on kick pad was inconsistent (especially on loud hits)
    [edrumulus.cpp]
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2021-10-02 bug fix: 10 kOhm resistor instead of 10 Ohm
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2021-10-11 added test signal for Teensy 4.0 noise testing
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2021-10-15 fix moving average normalization so that hil and hil_filt can use the same threshold
    [edrumulus.cpp, edrumulus.h]
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2021-10-17 fixes for rim shot detection, improvement of edrumuluscontrol
    [edrumulus.cpp]
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2021-11-20 testing new IIR filter design for detecting peaks in noise (bandpass filter)
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2021-11-21 remove the Hilbert filter and replace it with an IIR band-pass filter
2021-11-25 fix first peak detection, delay original x to match filtered x, set peak-diff-threshold to 8 dB
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2021-12-01 started porting edrumulus c++ code -> process_sample() port still missing, i.e., it does not yet compile successfully
    [edrumulus.cpp, edrumulus.h]
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2021-12-06 try to fix the KD-7 "hard hit" problem with using a constant decay value in the mask time, i.e., the mask time does still trigger if a succeeding hit is much louder than the current hit
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2021-12-07 bug fix: max peak of filtered signal for constant decay during mask time shall be measured in complete scan time
2021-12-08 consider the velocity threshold offset for the velocity sensitivity to avoid having to adjust the sensitivity if the velocity threshold is changed
    [edrumulus.cpp]
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2021-12-10 bug fix: mask_time_decay_fact_db was not initialized
    [edrumulus.cpp]
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2021-12-16 bug fix and cleanup of unused history
    [edrumulus.cpp, edrumulus.h]
2021-12-16 fix PD120 pad setting
    [edrumulus.cpp]
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2021-12-17 finished one stereo jack
    [edrumulus.sch]
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2021-12-18 finished schematic of prototype 2
    [edrumulus.sch]
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2021-12-18 create a net list and use not connected markers
    [edrumulus.sch]
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2021-12-18 use correct pin out of ESP32 DEVKITV1
    [edrumulus.sch]
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2021-12-18 initial version of PCB
    [edrumulus.kicad_pcb]
2021-12-18 fix bug with MIDI IN/OUT
    [edrumulus.kicad_pcb, edrumulus.sch]
2021-12-18 some updated to PCB
    [edrumulus.kicad_pcb]
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2021-12-18 some tests, moving components
    [edrumulus.kicad_pcb]
2021-12-19 small fixes
    [edrumulus.kicad_pcb, edrumulus.sch]
2021-12-19 clean up schematics -> PCB must be re-started from scratch
    [edrumulus.kicad_pcb, edrumulus.sch]
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2021-12-19 bug fix with audio jack connector names
    [edrumulus.kicad_pcb, edrumulus.sch]
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2021-12-28 fixes compiler unused variable warning
    [edrumulus.cpp]
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2021-12-31 port hot spot bug fix to C++ -> does not work as expected
    [edrumulus.cpp]
2021-12-31 bug fix with the hot spot suppression
    [edrumulus.cpp]
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2022-01-01 some test parameters for Teensy hot spot signal -> not working
2022-01-01 revert hot spot implementation in edrumulus and C++ because the current algorithm does not perform well
    [edrumulus.cpp, edrumulus.h]
2022-01-01 fixed a bug in rim shot detection: use peak_val for the metric instead of first_peak_val
    [edrumulus.cpp]
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2022-01-09 fix a crash with the ESP32 (I assume that the crash was caused by not enough memory available on the ESP32)
    [edrumulus.ino]
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2022-01-15 bug fix -> EdrumulusGUI with ESP32 did connect itselfs MIDI ports
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2022-01-22 added some test code for storing settings, not working
    [edrumulus.h, edrumulus.ino, edrumulus_hardware.cpp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]
2022-01-22 the timer must be disabled on ESP32 to be able to write EEPROM settings, otherwise we get a crash
    [edrumulus.h, edrumulus.ino, edrumulus_hardware.cpp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]
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2022-02-17 small fix in comment
    [edrumulus.cpp]
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2022-07-14 template files for new prototype development
    [edrumulus.sch]
2022-07-14 finish trigger connection for prototype 4
    [edrumulus.sch]
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2022-07-16 fix schematics for prototype4
    [edrumulus.sch]
2022-07-17 bug fix for sub d connector (do not mirror the component)
    [edrumulus.kicad_pcb, edrumulus.sch]
2022-07-17 port to KiCad 6
    [edrumulus.kicad_pcb, edrumulus.kicad_sch]
2022-07-18 component sorting for prototype 4
    [edrumulus.kicad_pcb]
2022-07-18 more component sorting for prototype 4
    [edrumulus.kicad_pcb]
2022-07-19 sort more components for prototype 4
    [edrumulus.kicad_pcb]
2022-07-19 optimize ESP32 dev board model
    [edrumulus.kicad_pcb]
2022-07-19 diodes must have larger size on PCB
    [edrumulus.kicad_pcb, edrumulus.kicad_sch]
2022-07-20 some more component reordering for prototype 4
    [edrumulus.kicad_pcb, edrumulus.kicad_sch]
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2022-07-20 finished the first routing of prototype 4
    [edrumulus.kicad_pcb]
2022-07-21 fix the edges (round edges)
    [edrumulus.kicad_pcb]
2022-07-21 fix some warnings
    [edrumulus.kicad_pcb]
2022-07-21 optimize connections for prototype 4
    [edrumulus.kicad_pcb]
2022-07-21 some more optimizations for prototype 4
    [edrumulus.kicad_pcb]
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2022-07-21 added an additional GND to the ESP32 board
    [edrumulus.kicad_pcb, edrumulus.kicad_sch]
2022-07-21 added text for ESP placement
    [edrumulus.kicad_pcb]
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2022-07-25 disable settings storage on ESP32 for now because it does not work reliable
    [edrumulus.ino, edrumulus_hardware.cpp]
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2022-08-06 added support for a simple signal overload correction algorithm
    [edrumulus.cpp, edrumulus.h]
2022-08-07 added template for prototype 5 hardware
    [edrumulus.kicad_pcb, edrumulus.kicad_sch]
2022-08-07 some more work for prototype 5
    [edrumulus.kicad_sch]
2022-08-07 some more work on prototype 5
    [edrumulus.kicad_sch]
2022-08-08 added enable and LED
    [edrumulus.kicad_sch]
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2022-08-13 some more prototype 5 development
    [edrumulus.kicad_pcb, edrumulus.kicad_sch]
2022-08-14 some more layout cleanup for prototype 5
    [edrumulus.kicad_pcb]
2022-08-14 some more compenent sorting for prototype 5
    [edrumulus.kicad_pcb]
2022-08-14 more work on prototype 5
    [edrumulus.kicad_pcb]
2022-08-20 some prototype 5 routing
    [edrumulus.kicad_pcb]
2022-08-20 prototype 5 component placement
    [edrumulus.kicad_pcb, edrumulus.kicad_sch]
2022-08-20 more prototype 5 routing
    [edrumulus.kicad_pcb]
2022-08-20 connect GPIOs for boot/enable, some more routing for prototype 5
    [edrumulus.kicad_pcb, edrumulus.kicad_sch]
2022-08-20 new linear controller for SDB bias
    [edrumulus.kicad_pcb, edrumulus.kicad_sch]
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2022-08-20 some more routing for the prototype 5
    [edrumulus.kicad_pcb]
2022-08-20 even more routing for the prototype 5
    [edrumulus.kicad_pcb]
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2022-08-21 more routing prototype 5
    [edrumulus.kicad_pcb]
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2022-08-21 fix some errors in prototype 5
    [edrumulus.kicad_pcb]
2022-08-21 fix annotations and other problems in prototype 5
    [edrumulus.kicad_pcb, edrumulus.kicad_sch]
2022-08-21 fix warnings in prototype 5 PCB
    [edrumulus.kicad_pcb]
2022-08-21 some small fixes for prototype 5
    [edrumulus.kicad_pcb]
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2022-08-22 try to avoid ground loop for prototype 5
    [edrumulus.kicad_pcb]
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2022-08-23 change resistor size from 1206 to 0603 for prototype 5
    [edrumulus.kicad_pcb, edrumulus.kicad_sch]
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2022-08-23 use 0603 for the caps for prototype 5
    [edrumulus.kicad_pcb, edrumulus.kicad_sch]
2022-08-23 added the caps on the lower bias resistor for prototype 5
    [edrumulus.kicad_pcb, edrumulus.kicad_sch]
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2022-08-25 Add 3 0603 capacitors to the ESP32_3V3 net. Add one 1210 ferrite bead between RASPI-VIN and pin1 of U3. Add one 1210 ferrite bead between RASPI-VIN and pin3 of U2. Also place an 0603 cap on the RASPI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
    [edrumulus.kicad_pcb, edrumulus.kicad_sch]
2022-08-25 added initial version of edrumulus prototype 5 front panel PCB
    [edrumulus_front_panel.kicad_pcb, edrumulus_front_panel.kicad_sch]
2022-08-25 adding buttons to the front panel for prototype 5
    [edrumulus_front_panel.kicad_pcb, edrumulus_front_panel.kicad_sch]
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2022-08-27 some more work for the display hat for prototype 5
    [edrumulus_front_panel.kicad_sch]
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2022-08-29 delivery jstma for prototype 5 on 8/28/2022 #2
    [edrumulus.kicad_pcb, edrumulus.kicad_sch]
2022-08-29 delivery jstma for prototype 5 on 8/28/2022 #3
    [edrumulus.kicad_pcb, edrumulus.kicad_sch]
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2022-08-29 finished initial prototpye 6 schematics (still fine tuning has to be done)
    [edrumulus.kicad_sch]
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2022-08-30 delivery jstma for prototype 5 on 8/30/2022 #1
    [edrumulus.kicad_pcb]
2022-08-30 delivery jstma for prototype 5 on 8/30/2022 #2
    [edrumulus.kicad_pcb]
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2022-08-30 fix ESP32 dev board foot print (had to be rotated by 180 degrees
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2022-09-01 more fine tuning and fixing for prototype 6
    [edrumulus.kicad_pcb]
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2022-09-01 fixes for the front panel for prototype 5
    [edrumulus_front_panel.kicad_pcb, edrumulus_front_panel.kicad_sch]
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2022-09-01 use lower resistors for MIDI out because we have 3.3V
    [edrumulus.kicad_pcb, edrumulus.kicad_sch]
2022-09-01 small fix
    [edrumulus.kicad_pcb]
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2022-09-02 change the schematics to support a GPIO board identification for prototype 5
    [edrumulus.kicad_sch]
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2022-09-04 small fix for gerber output of front panel
    [edrumulus_front_panel.kicad_pcb]
2022-09-04 create gerber file for prototype 5 front panel
    [edrumulus_front_panel.kicad_pcb]
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2022-09-04 do not use subtract soldermask from silkscreen for generating Gerber files for prototype 5 -> update zip file
    [edrumulus.kicad_pcb]
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2022-09-15 added test files for noise capturing with prototype 6
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2022-09-24 bug fix on GUI on pad type change
    [edrumulus.ino]
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2022-09-24 fix problem that flash ESP32 did only work on second attempt
2022-09-24 re-enable storage on ESP32 to be able to debug the issue, increase snare level in mixdown_kits
    [edrumulus.ino, edrumulus_hardware.cpp]
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2022-10-15 small fix: if condition not necessary
    [edrumulus.cpp]
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2022-10-24 use a shortcut for speed optimization
    [edrumulus.cpp]
2022-10-24 temporarily reduce the number of inputs so that we do not have a speed issue for testing a multiple sensor pad
    [edrumulus_hardware.cpp]
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2022-10-26 remove sSensorResults and use first_peak_delay from sensor struct -> not yet working correctly...
    [edrumulus.cpp, edrumulus.h]
2022-10-27 bug fix and introduce test code for using sensor with second highest velocity for rim shot detection
    [edrumulus.cpp]
2022-11-01 some fixes for pos det Python file
    [pos_det.py]
2022-11-03 some small fixes for pos_det.py
    [pos_det.py]
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2022-11-12 some fixes for the debugging of position detection
    [edrumulus.cpp, pos_det.py]
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2022-11-22 bug fix for peak detection in create_drumgizmo_kit.py
    [create_drumgizmo_kit.py]
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2022-11-27 small fix for sampling rate
    [create_drumgizmo_kit.py]
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2022-11-30 some fixes and code improvements
    [create_drumgizmo_kit.py]
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2022-12-03 try to fix start of strike samples issue and added hi-hat top samples
    [create_drumgizmo_kit.py]
2022-12-17 fixes for PearlMMX drum kit creation
    [create_drumgizmo_kit.py]
2022-12-27 use an absolute treshold instead of a relative (which gave problems with different positional sensing recordings)
    [create_drumgizmo_kit.py]
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2023-01-06 disable settings storage on ESP32 again since it still does not work reliable
    [edrumulus.ino, edrumulus_hardware.cpp]
2023-01-06 fix for matlibplot issue
    [create_drumgizmo_kit.py]
2023-01-08 bug fix and improvement
    [edrumulus_gui.py]
2023-01-08 fix load settings issue (it too way too long) -> now it loads all the settings very quickly
    [edrumulus.cpp, edrumulus.h, edrumulus_gui.py]
2023-01-09 revert last commit since it did not work
    [edrumulus_gui.py]
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2023-01-11 bug fix with delayed initialization: did not work for pedal control
    [edrumulus.cpp, edrumulus.h]
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2023-01-13 improve kit volume implementation, still not working correctly...
    [edrumulus_gui.py]
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2023-01-15 small fixes for showing kit/kit volume depending on availability
    [edrumulus_gui.py]
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2023-01-15 receive SIG (not yet working correctly...)
    [edrumulus_gui.py]
2023-01-16 bug fix with LCD update on button long press
    [edrumulus_gui.py]
2023-01-27 do not show error trace
2023-01-28 bug fix: overload detection must also be delayed if spike cancellation is enabled
    [edrumulus.cpp, edrumulus_hardware.cpp, edrumulus_hardware.h]
2023-01-29 fix overload correction algorithm
    [edrumulus.cpp, edrumulus.h]
2023-01-29 shorter overload history should also work (speed optimization)
    [edrumulus.cpp]
2023-02-03 bug fix: on ESP32, cymbal choke did not work correctly
    [edrumulus.cpp, edrumulus.h]
2023-02-06 bug fix with search range of first_peak_idx (should be ok in edrumulus.m), indicate sign of unfiltered x signal in plot with different color of the trace
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2023-03-17 serial print non-clipped and corrected values
    [edrumulus.cpp]
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2023-03-26 bug fix with sign of mean_neighbor_x
    [edrumulus.cpp]
2023-03-29 bug fix for Teensy in edrumulus_gui.py
    [edrumulus_gui.py]
2023-04-01 fix compiler errors for ESP32-S3 by using the analogRead() function but this will most probably not work since this function is way too slow...
    [edrumulus_hardware.cpp, edrumulus_hardware.h]
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2023-04-12 fix a crash for ESP32-S3 (needs more stack depth)
    [edrumulus_hardware.cpp]
2023-04-12 testing new Octave implementation -> not yet working correctly...
    [edrumulus.cpp]
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2023-04-13 fix Teensy compilation error, added some tests for ESP32-S3
    [edrumulus_hardware.cpp, edrumulus_hardware.h]
2023-04-13 fix compiler error and compiler warning for ESP32
    [edrumulus_hardware.h]
2023-04-15 try to replace adc1_get_raw
    [edrumulus_hardware.cpp]
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2023-04-16 fix preset to work even if not 9 inputs are defined
    [edrumulus.ino]
2023-04-16 testing own adc1 raw code -> not yet working correctly
    [edrumulus.cpp, edrumulus.ino, edrumulus_hardware.cpp]
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2023-04-17 try to fix ADC offset of ESP32-S3
    [edrumulus_hardware.cpp]
2023-04-17 bug fix for ADC2 and let get_raw() function do all the initialization
    [edrumulus_hardware.cpp]
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2023-04-23 bug fix with neighbor values
    [edrumulus.cpp]
2023-04-23 bug fix and code cleanup
    [edrumulus.cpp]
2023-04-23 fix USE_SERIAL_DEBUG_PLOTTING for ESP32
    [edrumulus.h]
2023-04-23 improve rim shot detection for rim switch pads (try to solve issue with ESP32 crosstalk between ADC channels)
    [edrumulus.cpp]
2023-04-24 fix for serial debugging on an ESP32
    [edrumulus.ino]
2023-04-24 bug fix with serial print debugging: avoid log(0) which gives inf in Arduino and this leads to unplotted points and unsynchronized traces in the graph
    [edrumulus.h]
2023-04-25 bug fix of edrumulus GUI on MacOS
    [edrumulus_gui.py]
2023-05-02 fix curve parameter (do new calibration with TD-27 using PD8 and PD80R pads)
    [edrumulus.cpp]
2023-05-03 remove Teensy 3.6 code since that model is not supported (too slow CPU for running Edrumulus)
    [edrumulus_hardware.cpp, edrumulus_hardware.h]
2023-05-20 fix crash on prototype 5
    [edrumulus_hardware.cpp]
2023-05-22 some fixes in webui
    [edrumulus_gui.py]
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2023-06-22 try to improve the clipping compensation algorithm -> improvement does not yet work correctly and needs to be fixed
    [edrumulus.cpp, edrumulus.ino]
2023-06-26 bug fix: fixed an out-of-bound read
    [edrumulus.cpp]
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2023-06-30 some fixes regarding the clipping compensation: enlarge overload history length (this is possible since we use a speed optimized FIFO now) and avoid modifying peak_delay
    [edrumulus.cpp]
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2023-07-03 small fixes with positional sensing
    [edrumulus.cpp, edrumulus.h]
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2023-07-29 small fix for second rim
    [edrumulus.cpp]
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2023-08-12 platformio config: add missing teensy36
2023-08-12 CI: build all boards at once
    Since pio ci --board doesn't have any effect with a global
    config anyway, it makes sense to just build all boards
    at the same time.
2023-08-13 platformio config: use arduino-esp32 2.0.9
    https://github.com/espressif/arduino-esp32/issues/8471
2023-08-14 added clarification for Issue #86
    [edrumulus_hardware.cpp]
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2023-09-26 correct hi-hat MIDI notes in PearlMMX kit
    [create_drumgizmo_kit.py]
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2023-10-01 remove warning message since the problem in ESP32 Arduino library is now solved
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2023-10-05 added sample shortening for Raspberry Pi usage and some other MIDI assignment optimizations
    [create_drumgizmo_kit.py]
2023-10-12 Teensy 4.1: support ADC pins 14-17
    Fixes #102
    [edrumulus_hardware.cpp, edrumulus_hardware.h]
2023-10-12 Revert "platformio config: use arduino-esp32 2.0.9"
    This reverts commit 8581fd7ca237542e5d4e3e3d0dcd18b65f945451.
    Versions >= 2.0.12 don't have the MIDI bug anymore.
    https://github.com/corrados/edrumulus/discussions/101
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2023-10-22 fixes edrumulus_gui.py removes trigger settings, if killed #108
    [edrumulus_gui.py]
2023-10-24 in error case, let the board LED blink
    [edrumulus.cpp, edrumulus.h]
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2023-11-01 show error state in GUI
    [edrumulus.ino, edrumulus_gui.py]
2023-11-02 show type of error and in case of DC offset error, show pad/input information in the GUI
    [edrumulus.cpp, edrumulus.h, edrumulus.ino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]
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2023-11-06 bug fix: use correct gradient calculation for pedal stomp detection (see discussion in Pull Request #110)
    [edrumulus.cpp, edrumulus.h]
2023-11-07 change SAMPLING RATE TOO LOW ERROR to SAMPLING RATE TOO LOW WARNING since if the sampling rate is just a bit too low, you can still play almost normally
    [edrumulus_gui.py]
2023-11-08 fix error message (see Pull Request #116)
    [edrumulus_gui.py]
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2023-11-12 fix for LCD GUI
    [edrumulus_gui.py]
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2023-11-13 fix volume issue with ecasound kits in edrumulus_gui
    [edrumulus_gui.py]
2023-11-14 fixed a typo: treshold -> threshold
    [edrumulus.cpp, edrumulus.h, edrumulus.ino]
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2023-11-29 update MIDI map from settings: not working since unused MIDI notes are treated as valid ones based on Pull Request #129
    [edrumulus_gui.py]
2023-11-29 fix auto pad selection, use first occurence of MIDI note for MIDI map
    [edrumulus_gui.py]
2023-11-29 fix issue with cymbal choke not working anymore (MIDI note 0 is used to select a different aftertouch method)
    [edrumulus.cpp]
2023-11-30 bug fix: go back to original version with import of rtmidi midiutil library
    [edrumulus_gui.py]
2023-11-30 some fixes for Windows serial
    [edrumulus_gui.py]
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2023-12-30 fix issue when resizing the GUI window
    [edrumulus_gui.py]
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2024-04-24 bug fix: direct piezo hits sometimes cause a MIDI mute #142
    [edrumulus.cpp, edrumulus.h]
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2024-06-09 now it compiles for new ESP32 library but does not yet work (reboots)
    [edrumulus_hardware.cpp]
2024-06-11 fix crashes under IDF V3.x
    [edrumulus_hardware.cpp]
2024-06-15 some clang format fixes
    [edrumulus.ino, hardware.cpp]
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2024-08-12 fix crashes on ESP32-S3
    [hardware.cpp]
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2025-05-17 manual: fix: shorting cannot break the ADC
2025-05-17 edrumulus 3hhh prototype
    See the README.md for details.
    I tested this a bit and it appears to work as expected.
    [BOM-edrumulus_3hhh.csv, edrumulus_3hhh.kicad_pcb, edrumulus_3hhh.kicad_sch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]
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2025-12-07 try to fix firmware upload on Raspberry Pi 4 prototype 5
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2025-12-31 some more work for load indicator (not yet working correctly)
    [edrumulus.cpp, edrumulus.h, edrumulus.ino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]
2025-12-31 fixes and clean up
    [edrumulus.ino, edrumulus_gui.py]
2025-12-31 modify code for checking load indicator correctness
    [pad.h]
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2026-01-01 if dc_offset_iir_gamma is double, a type conversion is no longer needed
    [edrumulus.cpp, edrumulus.h]
2026-01-01 avoid calculation in double precision where not needed
    [edrumulus.cpp]
2026-01-03 try to fix CI errors
    [pad.h]
2026-01-04 add initial support for crash2 input
    [edrumulus.ino, edrumulus_gui.py]
2026-01-04 avoid GPIO2 since it is the dev board LED pin, remove test code
    [edrumulus.ino, hardware.cpp]
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2026-01-07 consider crash2 for prototype 5
    [hardware.cpp]
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2026-01-15 bug fixes and cleanup
    [edrumulus.cpp]
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
